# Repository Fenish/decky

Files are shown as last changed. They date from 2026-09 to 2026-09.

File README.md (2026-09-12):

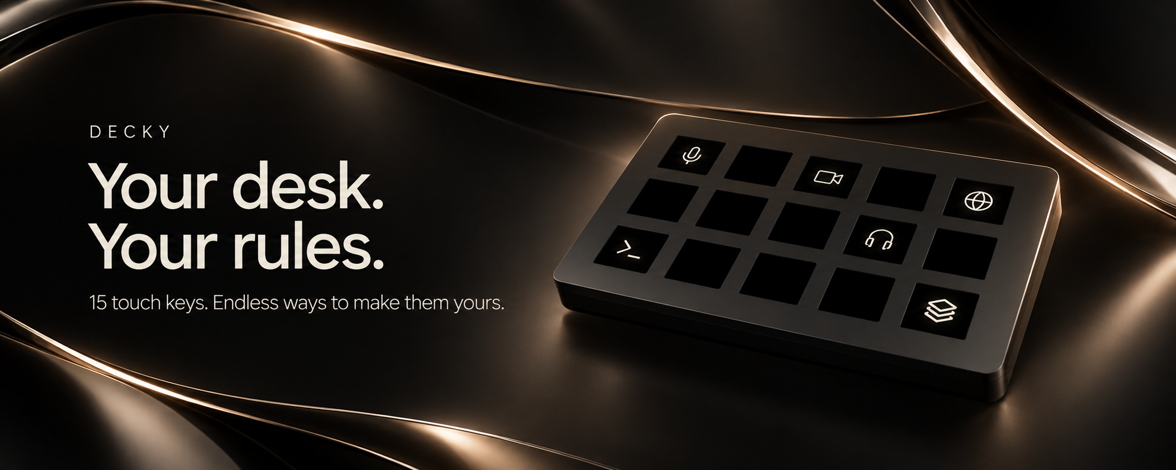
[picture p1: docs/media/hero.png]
Decky — Your desk. Your rules. Fifteen touch keys, endless ways to make them yours.


<p align="center">
  <strong>A personal touch control surface for the things you do every day.</strong><br>
  Built around a 7-inch display, a Windows app, and an enclosure you can print yourself.
</p>

<p align="center">
  <a href="#meet-your-new-workspace">Explore Decky</a> ·
  <a href="#make-it-your-own">Customize it</a> ·
  <a href="#build-your-decky">Get started</a> ·
  <a href="DeckSrc/desktop/README.md">Build it</a>
</p>

https://github.com/user-attachments/assets/fdbf7ccb-014a-4768-bcb0-b18ee1778c3f

https://github.com/user-attachments/assets/bed2e491-3eae-4fae-b585-68fe51a1e4fc

15 touch keys, USB and Wi-Fi, local SD artwork, and a Windows desktop app

## Meet your new workspace

Mute a call. Open your tools. Start the sequence that gets you live.

Decky puts your shortcuts, programs, scripts, and routines on a **5 × 3 touch
grid**. Give each key a purpose, build pages for different parts of your day,
and keep the controls you reach for right in front of you.

The desktop app pairs a floating grid with a contextual editor. Select a key and
the workspace slides aside; close the editor and the deck takes center stage
again.

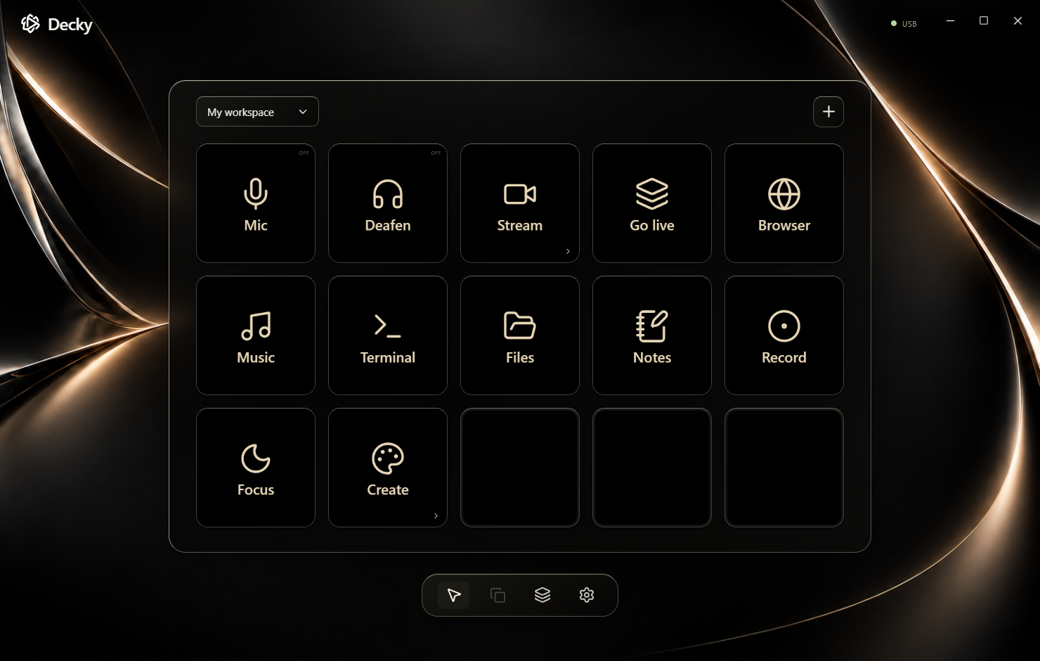
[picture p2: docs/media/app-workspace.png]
The actual Decky app with an example workspace for audio, streaming, tools, and focus


<p align="center"><sub>Actual Windows app · Example configuration · New workspaces start empty</sub></p>

### Small keys. Useful things.

| Shortcuts & hotkeys | Programs & websites | Macros & scripts |
| :--- | :--- | :--- |
| Bind your existing apps, record a combination, or let Decky reserve a free shortcut for you. | Find installed programs with their real icons. Put a favorite website one touch away. | Chain actions and delays into a routine, or launch a PowerShell script independently. |
| **Pages & folders** | **Normal & toggle keys** | **Your own artwork** |
| Keep streaming, work, and creative tools on separate pages, with a dedicated way back. | Run an action once, or give its OFF and ON appearances their own visual identity. | Search the Lucide icon library or bring your own PNG, JPEG, and WebP images. |

## Make it your own

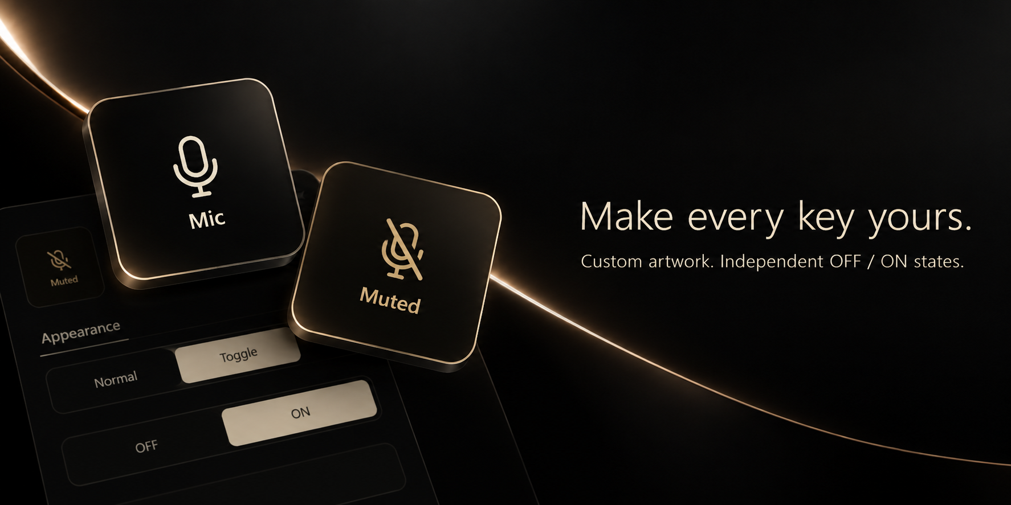
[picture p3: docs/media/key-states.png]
Illustrated close-up of Decky's microphone and muted appearances — Make every key yours


Choose the icon, label, accent, and background. Fine-tune image zoom, position,
rotation, and brightness. Leave the label out for a centered icon, or adjust the
space between the icon and its title.

**The editor and deck preview update together**, so you can see the result
before saving. Drag keys to move them, drop onto an occupied spot to swap, or
duplicate a key to build out a page. Unassigned keys stay pitch black.

<details>
<summary><strong>Look inside the real appearance editor</strong></summary>

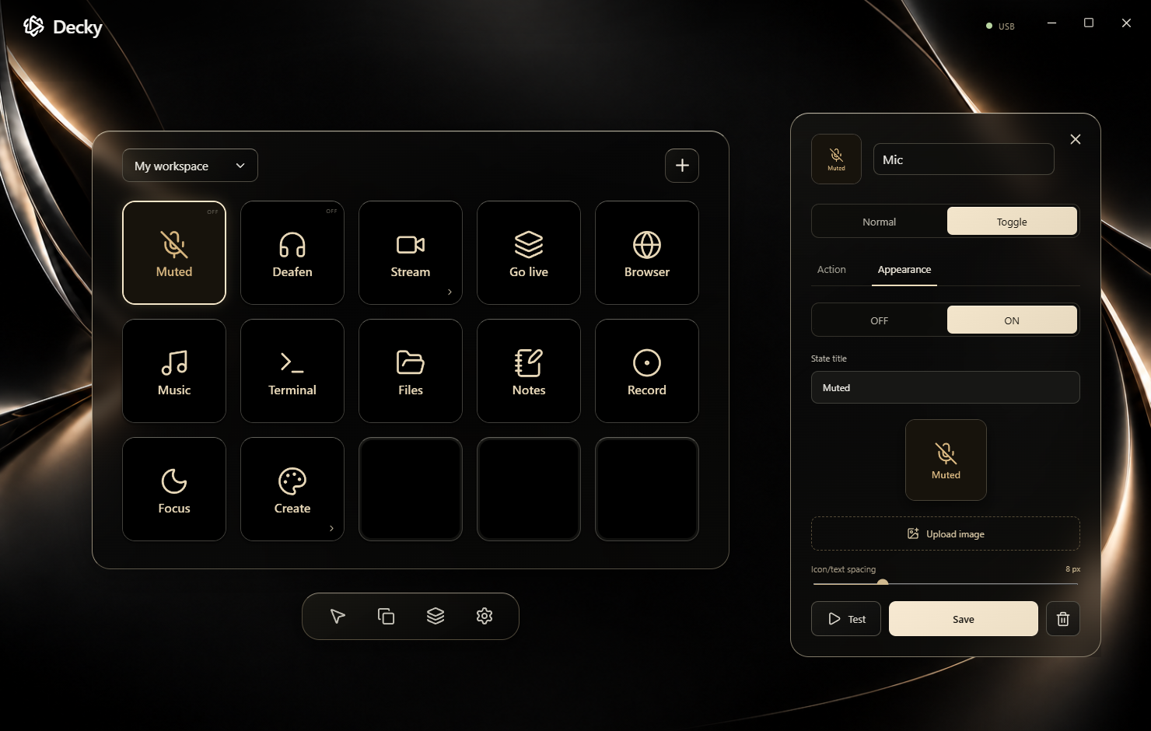
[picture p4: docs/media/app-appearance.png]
Decky's actual appearance editor with a custom ON-state preview


OFF and ON artwork are designed independently. Toggle state changes after a
successful action; it tracks the Decky session rather than reading another app's
state automatically.

</details>

<details>
<summary><strong>Build a routine with the macro editor</strong></summary>

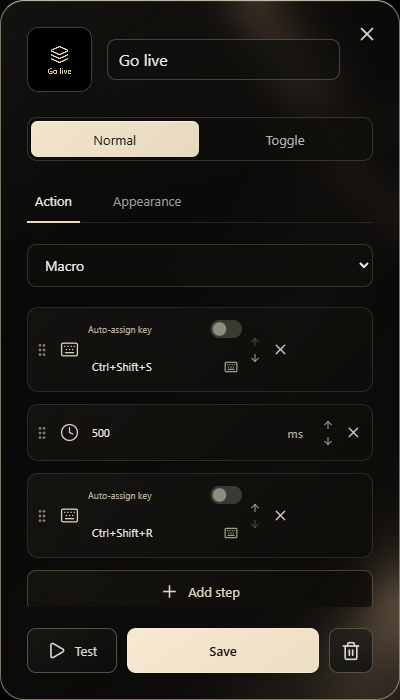
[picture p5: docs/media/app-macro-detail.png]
Actual macro editor showing two hotkeys separated by a 500 millisecond delay


Combine hotkeys, programs, websites, scripts, and delays into an ordered
sequence. Reorder steps with the editor controls. Independent scripts can keep
running while you use other keys.

</details>

## Give it a place at your desk

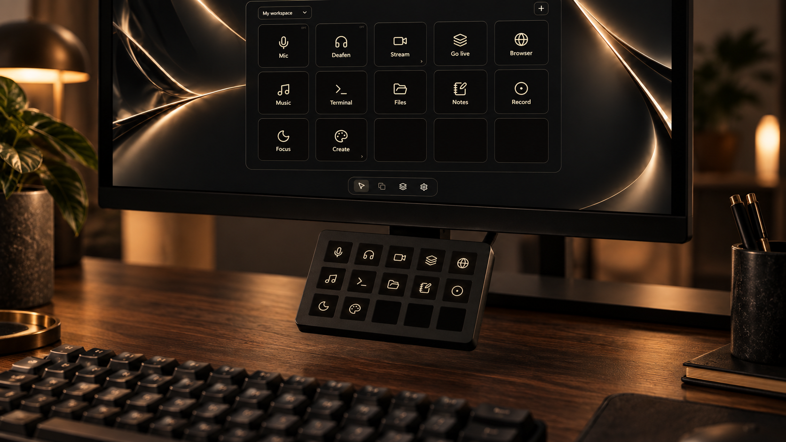
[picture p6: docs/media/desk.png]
Concept desk scene showing Decky mounted beneath a monitor with its Windows app on screen


Decky's 3D-printed enclosure is designed to hang beneath a monitor, keeping its
touch surface within reach. The repository includes the enclosure and clamp
assets alongside the software and firmware.

Pair a restrained ivory icon set with the obsidian-and-gold app, or fill your
keys with your own images. The same surface can become a streaming panel, a work
launcher, or a set of tools for the project you're in.

## Connected when you need it. Ready when you return.

### Plug in. Pair once.

Start over USB. In Settings, scan for a **2.4 GHz Wi-Fi network**, choose it,
and connect. Decky uses USB when available and falls back to paired, encrypted
Wi-Fi on your local network. USB still supplies power, and the Windows app keeps
your actions running from the system tray.

### Keep your artwork on the deck.

Add a microSD card and Decky saves your page artwork and toggle appearances
locally. After a restart, unchanged images load from the card into memory
instead of being uploaded again. Changing a toggle selects its preloaded
appearance and redraws the affected key.

### Make the next setup easier.

Export your profile to keep a copy of your configuration or move it to another
setup. Firmware installation and updates are available from the desktop app over
USB.

## Build your Decky

Decky is a **DIY hardware and software project**. Start with:

| Part | What you need |
| :--- | :--- |
| Display | Elecrow CrowPanel **Basic 7-inch**, ESP32-S3 with GT911 touch |
| Computer | A Windows PC running the Decky desktop app |
| Connection | A USB data cable; a shared local network for optional Wi-Fi |
| Storage | A microSD card for artwork that survives power cycles |
| Enclosure  | The project's 3D-printable enclosure and monitor-mount parts  |

To run the desktop app from the repository, install Node.js 22.16 or newer and
pnpm, then run:

```powershell
cd DeckSrc/desktop
pnpm install --frozen-lockfile
pnpm dev
```

Use the [firmware guide](DeckSrc/firmware/README.md) to prepare the panel. The firmware uses a pinned PlatformIO toolchain; the
repository's [hardware notes](DeckSrc/notes/memory/MEMORY.md) document the
board, touch input, SD card, and display setup.

## Under the surface

| Explore | Inside |
| :--- | :--- |
| [Windows desktop](DeckSrc/desktop) | Electron, React, TypeScript, key editing, actions, and device connections |
| [Device firmware](DeckSrc/firmware) | ESP32-S3 firmware, touch handling, rendering, wireless transport, and SD caching |
| [Hardware & build notes](DeckSrc/notes/memory/MEMORY.md) | The decisions and practical details behind the build |
| [Enclosure & mount](3D%20Models) | CAD exports and 3MF print files |
| [Branding](Branding) | Decky's logo sources and visual assets |

---

<p align="center">
  <strong>Make room for the way you work.</strong><br>
  <a href="#build-your-decky">Build Decky</a> · <a href="DeckSrc/desktop/README.md">Build the desktop app</a>
</p>

<p align="center"><sub>Hardware scenes and floating-key artwork are AI-generated product illustrations based on the project. App captures show an illustrative configuration in the real interface.</sub></p>

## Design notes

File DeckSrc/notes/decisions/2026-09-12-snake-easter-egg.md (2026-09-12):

---
name: 2026-09-12-snake-easter-egg
description:
  Five taps on an empty key play snake on the deck; one board behind the fifteen
  windows, steered by swiping, with the panel crushing into falling tiles at
  either end
metadata:
  type: decision
---

# Snake on the deck, and how it takes the panel

**Decision.** Five taps in a row on a key with nothing assigned to it start
snake on the deck itself (`firmware/src/game/snake.cpp`). The deck draws and
plays it; the window only keeps the score. When it ends the deck draws its own
page again, and the keys work as before.

**One board, not fifteen little ones.** The board is a single 20x12 grid over
the whole panel, and each key opening shows a 4x4 corner of it. The snake runs
behind the printed ribs and comes out the other side. Fifteen separate boards
was the alternative; it makes the ribs into walls, which is not a board.

**Swiping, not pressing.** A key press is a tile of the board, not a direction:
there is no natural place for four arrows on a grid that is also the playfield.
So a finger dragged anywhere across the panel turns the snake - 24 px in a
direction is a flick, less is a wobble - and the count-down before the first
move says SWIPE TO MOVE, a word to a key, because nothing else would tell you.
`KeyListener` gained a raw `touched(x, y, down, now)` for this: the game needs
the finger before the grid has decided which key it is over.

**The crush comes from the framebuffer.** Both ends of the game shatter what is
on screen into tiles that fall out of their openings. The tiles are the
picture's own colours, sampled one pixel per tile straight from
`panel::framebuffer()` (8x8 tiles a key, 960 in all, about 5 KB). Nothing has to
be kept, no page has to be re-read, and the memory the widgets needed back
yesterday ([[widgets]]) is untouched.

**Nothing else may draw while it runs.** Live patches, wheels and page states go
on arriving from the desktop during a game. They are all taken - the deck keeps
them - but the drawing is gated behind one predicate, `Deck::panel_free()`,
which now also covers the status screen and page changes it used to be spelled
out for at six call sites. The page is drawn whole when the panel comes back, so
everything that arrived meanwhile appears at once. Pausing the desktop's sends
instead was the alternative: more moving parts, and a deck that could still be
drawn over by anything that forgot.

**Why the desktop counts the taps.** The deck does not know which of its keys
are empty - it has pictures, not meaning. The desktop does, so `EmptyTaps` in
`deck-events.ts` counts taps on one empty key within 2.5 s of each other and
sends `GAME snake`; the deck's part is `GAME snake|off` and `EV GAME
SCORE|OVER`.

**Would change it.** A board that is too fast or too small to be fun on a real
panel (220 ms a step, down to 90 ms). Anyone finding it by accident - five taps
on an empty key is meant to be deliberate, and nothing on screen hints at it.

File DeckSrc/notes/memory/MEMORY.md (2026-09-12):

# Memory index

Durable facts about this project. One file per fact — read these before assuming
project context.

- [crowpanel-display](crowpanel-display.md) — the panel everything is
  dimensioned from
- [fusion-source-of-truth](fusion-source-of-truth.md) — measure in Fusion, never
  from memory
- [fusion-file-split](fusion-file-split.md) — which Fusion file holds what
- [print-support-free](print-support-free.md) — no supports, Bambu Studio, test
  prints
- [key-grid-layout](key-grid-layout.md) — 5x3, cell pitch, pixel-aligned
  openings
- [touch-input](touch-input.md) — GT911 on 0x14, no expander needed, no switches
- [no-visible-screws](no-visible-screws.md) — top cover stays clean, fasten from
  below
- [monitor-mount-scheme](monitor-mount-scheme.md) — magnet plate, clamp, GoPro
  joints, measured limits
- [open-source-unnamed](open-source-unnamed.md) — public open-source project
  named Decky; do not rename
- [decky-desktop](decky-desktop.md) — Decky identity, rewrite, black defaults,
  toggles, firmware and startup fix
- [bom](bom.md) — parts list, and the half of it the touch change killed
- [panel-pclk-limit](panel-pclk-limit.md) — 24 MHz pixel clock, bounded by
  bounce buffer size, not by the panel
- [screen-tearing-fix](screen-tearing-fix.md) — beam-synchronised writes, not
  double buffering
- [gif-encoding-for-the-panel](gif-encoding-for-the-panel.md) — full frames, no
  duplicates, and why the desktop file lies
- [pushing-media-without-flashing](pushing-media-without-flashing.md) — put an
  image or GIF on a key over serial, no reflash
- [frame-pack-format](frame-pack-format.md) — host decodes, deck only blits; the
  wire format
- [where-content-plays-from](where-content-plays-from.md) — PSRAM if it fits,
  card if not; and the card's hard 383 KB/s
- [sd-card-storage](sd-card-storage.md) — 4 MB flash is a hard limit; there is a
  TF slot on SPI
- [flashing-the-panel](flashing-the-panel.md) — CH340 driver, moving COM port,
  460800 baud, and the encoding trap
- [firmware-build-status](firmware-build-status.md) — what the board is
  currently running; the GIF player was deleted and is not in git
- [build-status](build-status.md) — what is printed, what is stale, what has not
  started
- [dont-run-long-lived-commands](dont-run-long-lived-commands.md) — the user
  starts dev servers and the app; they hang here
- [firmware-install](firmware-install.md) — the app flashes over USB; never NVS;
  two esptool-js traps
- [wifi-encryption](wifi-encryption.md) — AES-GCM frames after pairing, both
  sides must match
- [connection-priority](connection-priority.md) — USB first, Wi-Fi fallback, no
  manual switch
- [serial-unplug-stall](serial-unplug-stall.md) — a write to an unplugged port
  never returns and stalls every deck command
- [visual-tweaks-checked-by-hand](visual-tweaks-checked-by-hand.md) — styling
  changes: lint + UI checks, then hand over; the user checks the live app
- [release-pipeline](release-pipeline.md) — every product-code push to main
  releases itself; firmware has its own version
- [app-self-update](app-self-update.md) — installed Decky updates itself via
  electron-updater, differentially (blockmap, ~3 MB); the silent install is not
  yet seen on a real install
- [titlebar-drag-regions](titlebar-drag-regions.md) — nothing over the title
  bar's buttons may belong to the title bar; it steals their clicks
- [rgb-scanout-slip](rgb-scanout-slip.md) — a wrapped, shifted picture is the
  driver's bounce parity flipped by flash stalls; guarded every VSYNC, re-init
  never fixed it
- [packaging-drops-files](packaging-drops-files.md) — electron-builder silently
  drops *.obj and other extensions; package-check.mjs guards the installer
- [electron-run-as-node](electron-run-as-node.md) — shells here set
  ELECTRON_RUN_AS_NODE=1; unset it to launch Electron or the packaged app
- [deck-first-for-animation](deck-first-for-animation.md) — animated or heavy
  keys run on the deck; static or occasional ones are drawn by the app
- [widgets](widgets.md) — drawn by the app, LIVE-patched onto the deck;
  time-free base pictures, patched keys tracked per deck copy, every page warmed
  while loading, sound and prices as events, long titles slid by the deck,
  retired settings dropped on load
- [profiles](profiles.md) — several setups, one in use; a .deckyprofile carries
  one whole, and what travels is declared by each kind, never listed by hand
- [speedtest](speedtest.md) — our own Speedtest.net client: ask c.speedtest.net
  first or Istanbul gets Liechtenstein; one dropped connection must not fail the
  run
- [usb-upload-blocks](usb-upload-blocks.md) — 2 KB acknowledged blocks after
  BLOCK, thanks to the 8 KB receive buffer; test tools must honour READY's size
- [deck-restart-diagnosis](deck-restart-diagnosis.md) — why the deck restarted:
  `reset=`, deck.log, the core dump (empty means power), error 31 means replug
- [firmware-golden-run](firmware-golden-run.md) — prove a firmware change keeps
  behaviour: tools/golden_run.py record, flash, check (replies + screens)
- [generic-over-copies](generic-over-copies.md) — handler tables, not chains;
  one generic module told what it is, never per-type wrapper files
- [boot-loads-everything](boot-loads-everything.md) — nothing may be slow the
  first time after boot: every look, state and helper is loaded while the deck
  loads
- [discord-mute-state](discord-mute-state.md) — mute/deafen from Discord's local
  storage, ~5 s behind; RPC voice refused even for Decky's own app
- [discord-rich-presence](discord-rich-presence.md) — the public app ID is all
  it needs; never "Playing", only one of those shows
- [discord-rpc-control](discord-rpc-control.md) — full RPC control via
  StreamKit; channel members without joining; camera and stream state from
  Windows
- [integrations](integrations.md) — third-party apps (OBS first): declared in
  shared/integrations, a service each in main, widgets grouped by app
- [user-does-testing](user-does-testing.md) — the user tests on the deck and in
  the app; Claude checks the code and hands over

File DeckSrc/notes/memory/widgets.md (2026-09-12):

---
name: widgets
description:
  Widget keys are drawn by the desktop and patched onto the deck with LIVE; base
  pictures stay time-free; patched keys are tracked per deck copy; every page is
  warmed while the deck loads; sound and prices arrive as events, not polls
metadata:
  type: project
---

Widget keys (clock, timer, pomodoro, countdown, counter, ping, note, now
playing, volume, microphone, system, crypto, dice) are drawn by the desktop; the
deck receives pictures, and looks for the keys it turns itself.

- **Base pictures are time-free.** Page uploads carry what a widget's settings
  alone decide, so a page's signature never changes with the time. A digital
  clock's base picture is only its background, pixel-identical to an empty key.
- **The signature must stay the CRC of the pixels.** The SD store refuses any
  page whose pixels don't match it (`artwork_store.cpp`). Widget positions
  cannot go into the signature.
- **Live updates:** `LIVE <page> <sig> <cell> <baseCRC> <bytes> <crc>`, a
  tile/RLE patch, to any page the deck holds. The deck refuses it on a base
  mismatch, and the app then sends the whole key with base 0. It is gated by
  `live=1` in `ID`; hidden pages by `warm=1`.
- **Live pictures are kept apart from the page's own**
  ([[2026-09-11-live-layer]]). A page copy's own pictures stay exactly as sent,
  so they always match the signature and the card's copy loads. `LIVE` writes a
  per-key live picture.
  - **New versions:** a version built from a copy carries its live pictures and
    sliding text (`live=<mask>` in the `CACHE` reply). Only keys whose own
    picture changed go, as `PATCH`.
  - **Tracking:** `livePatched` in `main/widgets/live-keys.ts` (page id, then
    signature) mirrors what each copy shows.
  - **Widgets moved or removed:** such keys get their live picture dropped
    (`LIVE … 0 0 0`), or a moved clock leaves its time behind
    ([[2026-09-11-widgets-live-patches]]).
  - **Why:** re-sending every live widget whole took 10.4 s on the Debug page.
  - **The card save never holds an edit:** the deck shows a committed page
    first, then its main loop writes it to the card in 8 KB slices, so `COMMIT`
    answers in about 6 ms. Anything else on the card, or reusing a page slot,
    finishes the save first. Keep long card writes out of command handlers: the
    deck reads no touches and runs no animations meanwhile.
- **Every page is warmed while the deck loads** (`warm=1`). With the page cache
  the renderer sends each widget's picture as it is now and every look each
  deck-turned key can take ([[boot-loads-everything]]): a dial's muted look too,
  and a running countdown's drum, the page shown last. The app sends them after
  the pages and before showing one, counted in `HELLO`'s units. Afterwards a
  page not shown gets a widget's new picture when its state changes, at most
  every 5 s. The user asked for this: pages they switched to showed placeholders
  until visited.
- **The app waits for the deck.** While it loads - on connecting, or when the
  deck restarts - the app stays on its connection screen ("Decky is starting")
  and nothing is editable; the reveal plays after.
- **Presses:** a widget taps on release, and holds at 600 ms while still down
  (`HOLD_MS`). A finger that moved 10 px is a swipe: no tap, no hold.
- **Deck wheels (adjustable countdowns)** need finger movement:
  `EV <page> <cell> MOVE <y>`. The deck sends it only for keys named with
  `DRAG <mask>` (`drag=1` in `ID`). **Never let the firmware send unsolicited
  new line types:** released apps hand any line they can't parse to the command
  waiting for a reply (`serial.ts`), which breaks transfers. The app sends the
  mask when a page lands, and the deck clears it on `HELLO` and on disconnect.
- **Live frames are coalesced per key** (`liveQueue`): a waiting send takes the
  newest picture, so a fast swipe skips steps instead of queueing USB patches.
- **An adjustable countdown at rest is turned by the deck itself**
  (`firmware/src/keys/`, `wheel=1`).
  - **The look:** the app sends it once (`WHEEL`, `src/shared/wheel-spec.ts`):
    backdrop, the digits rasterised in the app's font, labels, and drum and
    physics settings. The deck keeps four looks by CRC, and `WHEELAT` re-arms
    one. `WHEEL` with cell -1 keeps a look without arming it.
  - **Motion:** the deck animates at the panel's rate and reports only the label
    it lands on (`EV … WHEEL`).
  - **Outside the page picture:** the wheel is drawn over the page copy without
    changing it, so `livePatched` is untouched. A `LIVE` picture for a key of
    the page shown ends its wheel.
  - **Tuning:** feel constants are in `WHEEL_FEEL` (app side) and need no
    reflash.
  - **Fallback:** without `wheel=1` the app steps the wheel from `MOVE` events.
- **Countdown sound** plays in the renderer through an `<audio>` element
  (`use-countdown-alarms.ts`), looping `kalimba.wav`. Fetching a bundled file
  would fail: Chromium's fetch refuses `file://` and the CSP allows only
  `connect-src 'self'`. The window needs
  `autoplayPolicy: "no-user-gesture-required"`, because it rings hidden in the
  tray, where no click ever happens. A tap on an ended countdown resets it.
- **Ping** times TCP to port 443 (ICMP is blocked on the user's network), with a
  second connection raced after 500 ms and ping.exe as a fallback.
- **Dials, rolls and the die (`dial=1`).** The volume is a dial: a version 2
  look (the key at its lowest, at its highest, and a per-pixel fill map). The
  deck reports `EV … VALUE` at most every 40 ms and the app sets Windows'
  volume.
  - **Coin, yes/no, list:** a drum; the app picks the side, and `WHEELROLL`
    spins to it, always forward (`rolling` in `ArmedWheel`).
  - **The die:** a 3D cube the deck draws and throws (look version 3,
    `src/shared/die.ts` mirrors its sums). Its "label" is how it lies (face,
    place, turn) and is kept as `rest` in widget state. How it lands must stay
    fair: see [[2026-09-11-deck-dice]].
  - **Same-kind looks:** a new look of the same kind takes over a key that is
    still moving without stopping it.
  - **How many looks the deck keeps:** one per key and one more, and never a
    look an armed key uses (`AnimatedKeys::LOOKS`). Released firmware up to
    0.1.4 kept four and dropped the one armed least lately, disarming its key
    without a word. So a refused `WHEELROLL` makes the app roll in its place and
    forget the arming (`rollOnDeck`); the look goes again with the key's next
    picture. Every mute makes a look of its own (greyed), so each dial on a page
    can need two.
- **Sliding text (`slide=1`).** A Now playing title or artist too long for the
  key is left out of its picture and sent to the deck as `SLIDE`
  (`shared/slide-spec.ts`; drawn by `features/widgets/slide.ts`). The deck
  slides it over the picture, so `LIVE` pictures change under it.
  - **Lifetime:** it belongs to the deck's copy of the page and goes with the
    key's live picture. `liveOverlays` in `main/widgets/live-keys.ts` mirrors
    `livePatched`: a new version carries it with the live picture, and `HELLO`
    and disconnect drop everything.
  - **Sending:** new text goes after its picture and is taken away before one,
    only when its CRC differs. The strip must render the same every time: the
    media key redraws every second, and new text restarts the slide.
  - See [[2026-09-11-sliding-text]].
- **Rings' arcs (`sweep=1`).** Only OBS's 5-second countdown ring has its arc
  moved by the deck (`SWEEP`, `shared/sweep-spec.ts`); the key's picture keeps
  only the track. Its drawing hands the arc to `moment.sweeps` through
  `sweepArc` (canvas-kit), with a motion: held, or `(t - zero) / turn` in the
  PC's clock. Keep motions exact integers from widget state, so the payload is
  identical second to second and goes once.
  - The timer (stopwatch and countdown) and pomodoro rings step with their
    digits, drawn into each second's picture (`timeRing`). The user tried them
    smooth and asked for "old version" for all but OBS.
  - Sliding text and arcs are both firmware `KeyOverlay`s and travel as
    `KeyOverlays` (`{ slide, sweep }`) through `liveKey`, the warmup and
    `LiveKeys`. An overlay taken away goes before the picture without it; one
    that comes or changes, after.
  - See [[2026-09-11-deck-rings]].
- **Readings** (volume, mic, media, CPU, prices) come from `WidgetFeeds` and are
  never saved. Only `KEPT_STATE` fields (what a person did) go to
  `widgets.json`.
  - **Sound is event-driven:** the Windows helper registers Core Audio volume
    callbacks (`watch-audio`) and writes `{"event":"audio"}` lines by itself;
    the app polls only every 15 s as a safety net. Echoes of the app's own
    volume sets are ignored for 400 ms so a turning dial never jumps back.
  - **Taps show at once:** mute and play/pause change the key before Windows
    answers; Windows' own word follows.
  - **Windows helper:** one persistent PowerShell
    (`main/system/windows-host.ps1`), one JSON line per request, answered in
    order; lines without an id are events.
  - **WinRT traps in PowerShell:** a WinRT stream is read by invoking
    `IInputStream.ReadAsync` through reflection on `$x.psobject.BaseObject`.
    Operations with progress need `AsTask` with both type arguments.
    `AsStreamForRead` and `GetInputStreamAt` fail from PowerShell. WinRT events
    are out of reach: the main loop blocks on `ReadLine`, so media is still read
    every second.
  - **Prices are live:** Binance's public stream
    (`wss://data-stream.binance.vision`, no key) for all coins on one socket,
    klines hourly for the chart, REST then CoinGecko for a coin the stream is
    quiet about (`main/widgets/crypto-feed.ts`). US dollars only (USDT).
- **Retired settings are dropped on load** (`retireWidgets` in
  `shared/config.ts`, each kind's `retire`): the network widget, crypto currency
  and interval; a microphone in a style since gone becomes an arc. Without it an
  old profile fails validation and the whole configuration is refused.
- **New firmware commands that older desktops can skip are `ID` flags**, not
  protocol bumps. Released apps reject any protocol above 7 (`serial.ts`).

**Why:** a 29 KB key cannot be resent every second over USB; patches take 20-95
ms, and uploads are bounded by [[usb-upload-blocks]].

**How to apply:** a new widget type needs no firmware change. It needs its kind,
its view, its action if it has one, and one registry line in each; a type
missing from a registry does not compile.

- **Kind** (`shared/widgets/<type>.ts`, `WidgetKind`): its settings type,
  defaults, validation, `nextChange`, and `press`/`swipe` if those change its
  state. Its type also joins the `Widget` union in `shared/widgets.ts`.
- **View** (`renderer/src/features/widgets/kinds/<type>/`, `WidgetView`): its
  drawing, its settings fields, `sample` (the made-up readings its style tiles
  show), and a `deckLook` if the deck turns it.
- **Action** (`main/widgets/actions/`, `WidgetAction`): only if a press does
  something beyond its own state - mute, play, roll. Its `gestures` table says
  what `tap`, `double`, `triple` and `hold` do. Only an action with `double` or
  `triple` makes its taps wait `TAP_GAP_MS` (300 ms) for another
  (`tap-runs.ts`), so give those to a widget only where the later tap is worth
  it.
- **Registries:** `shared/widgets/registry.ts`,
  `renderer/src/features/widgets/kinds/registry.ts`,
  `main/widgets/actions/registry.ts`.
- **Alike types share one generic module** ([[generic-over-copies]]): the volume
  and the microphone are `levelKind(...)`, `levelView(device)` (the
  `kinds/level/` folder, per-device icons and words in its `DEVICES`) and
  `SoundAction(device)`; the helper's `level`/`mute` requests take the device's
  flow. A turned dial goes to its action's `turned`.

Anything it reads goes in `WidgetFeeds` (a line in `sync`'s `reads`) - as events
where the source can tell of its changes - and anything a person sets that must
survive a restart goes in `KEPT_STATE`. Keep its base picture time-free.
Anything that must animate or follow a finger goes on the deck instead
([[deck-first-for-animation]]). Text that can outgrow its key goes to
`moment.slides` through `slideLine` rather than being cut with `clip`. A ring
the deck should move goes through `sweepArc` with a motion; the user wants that
only where asked (OBS's countdown). Removing a
setting needs its kind's `retire`.

**Designs are picked on the key, not only in the app.** A kind's `designs()`
lists the whole widgets it can be shown as (a clock's three faces, a die /
coin / yes-no / list, a level's arc and bar); a hold offers them on the key
itself, a dot each, every tap moves on, and three quiet seconds save the one
showing through `Workspace.setWidget`. `WidgetState.choosing` carries it, and
`deckTurned` answers null while it is set so the deck stops turning that key
and shows the preview instead. A widget whose hold already does something
never gets the picker, so freeing dice's hold (a duplicate of its tap) was
what let dice into it.

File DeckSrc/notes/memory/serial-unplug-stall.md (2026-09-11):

---
name: serial-unplug-stall
type: project
---

When the USB cable is pulled, the serial library closes the port itself (a
`close` event with `disconnected: true`). After that, a `write` or `drain` on
that port object never calls back: `@serialport/stream` holds them until the
port reopens, which it never does.

**Why it matters:** every deck command runs through one serial queue in the main
process. One write to a dead port stalls the queue forever, so the status check,
the Disconnected page and the Wi-Fi fallback all stop. Measured on the real
deck: the close event arrived about 1 s after the unplug, and a PING sent after
it was still waiting 12 s later.

**Wi-Fi has the same trap, worse.** A deck whose power goes never closes its TCP
connection: a write waits on TCP's own timeouts (minutes), and the whole queue
waits with it, so Decky goes on looking connected. Since 2026-09-12 the socket
is dropped when the deck ends it, a write over Wi-Fi gives up after 3 s, and a
ping still waiting while `DeckLink.silentFor` passes 8 s counts as the link gone
(`DeckSession.linkLost`, which also frees the queue by closing the link).

**How to apply:** `DeckLink` drops its port on `close` and refuses to write to a
port that is not open (`src/main/device/serial.ts`). Keep both, and the Wi-Fi
guards above. Any new code that talks to a port must not reuse a port object
after `close`. Watch the host, never the deck: listing ports and reading socket
state cost the deck nothing, while polling it would. `tests/serial.test.ts` pins
this with a fake port that behaves like the library.

Related: [[connection-priority]].

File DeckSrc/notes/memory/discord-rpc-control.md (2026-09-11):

---
name: discord-rpc-control
type: constraint
---

With a StreamKit-route token (see [[discord-mute-state]]), Discord granted every
extra scope asked for:
`rpc rpc.voice.write rpc.video.write rpc.screenshare.write rpc.notifications.read`
(2026-09-11). So the commands exist for mute/deafen, volumes, devices,
push-to-talk, soundboard, camera (`TOGGLE_VIDEO`), screen share
(`TOGGLE_SCREENSHARE`), and join/leave (`SELECT_VOICE_CHANNEL`).

What Decky can see:

- **Who is in any voice channel, without joining:** `GET_CHANNEL` returns each
  person's user (id, names, avatar hash) and mute/deafen. All 237 channels
  across 22 servers took 213 ms. Subscribing to `VOICE_STATE_CREATE` for a
  channel you are not in is accepted.
- **Camera and screen-share status do not come through RPC.** A voice state
  holds only `mute, deaf, self_mute, self_deaf, suppress`. Windows records them
  instead:
  `HKCU\...\CapabilityAccessManager\ConsentStore\{webcam, graphicsCaptureProgrammatic, graphicsCaptureWithoutBorder}\NonPackaged\*Discord.exe*`,
  where `LastUsedTimeStop` is 0 while in use. Discord's Clips recording counts
  as screen capture too.

On this PC, standalone Node (25) is reset by `discord.com` and
`cdn.discordapp.com`, while Electron's Node and `net.fetch` reach both. Run
Discord network tests through Electron (`ELECTRON_RUN_AS_NODE=1`, output
redirected to a file, since Electron is a GUI program).

**Notifications are events only, never counts.** No RPC command reads unread or
mention counts or read state (the client's full command list, datamined
2026-09-11). `NOTIFICATION_CREATE` (needs `rpc` and `rpc.notifications.read`)
fires from Discord's NotificationStore on a new message that would notify - not
while Discord's window is focused, not while a game with Discord's overlay is in
front (the overlay shows it instead), but even with desktop notifications set to
never. One that came before the link is never sent. `GET_CHANNEL` gives a
channel's last messages, with no read state; DMs cannot be listed over RPC. Old
mentions would need Discord's REST API with the user's account token -
self-botting, against Discord's terms: never offer it. The taskbar button's UIA
help text ("0 notifications") is Windows' own toast count, not Discord's badge,
and Discord's window title carries no count.

**Just started, Discord lists no devices yet.** The RPC voice settings take the
device in use from saved settings but `available_devices` from the media engine,
which fills it a moment later; `VOICE_SETTINGS_UPDATE` is sent at once on
SUBSCRIBE and again on any change. Until then the list holds one stand-in with
the default device's id `"default"` ("No Input Devices"), so an unlisted list is
"only that", not "empty". Anything drawn from the list must wait for the real
one (the switchers stay out of reach until then), or it changes twice.

**Deafened is muted, but `mute` does not say so.** Discord's `isSelfMute()`
includes deafened; the RPC reports the stored `mute`. Mute shows `mute || deaf`,
and `SET_VOICE_SETTINGS {mute: false}` while deafened undeafens.

**discord.log** (`%APPDATA%/Decky`) records the link coming and going and the
devices: read it first when a Discord start misbehaves.

**Discord's refusal echoes the token.** `AUTHENTICATE` with a bad token errors
`4009 Invalid access token: <the token>`. A script must not print RPC error
messages from `AUTHENTICATE` raw. A new Authorize (Decky's) ends the token an
earlier one gave (the lab's was refused after Decky authorized, 2026-09-11).

**Why it matters:** a Discord integration can drive almost everything from RPC,
but its camera and screen-share keys must read their state from Windows.

Related: [[discord-rich-presence]], [[electron-run-as-node]].

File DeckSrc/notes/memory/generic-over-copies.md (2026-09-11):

---
name: generic-over-copies
description:
  Code style the user asks for - handler tables instead of long if/else chains,
  and one generic, parameterised module instead of near-identical per-type files
metadata:
  type: feedback
---

**The user's rule:** structured, object-oriented code, never spaghetti.

- **Tables, not chains.** A long `if`/`else` or `switch` over kinds becomes a
  handler table: `{name, &Class::method}` rows in the firmware, typed
  `{ [K in Kind]: handler }` records in the app. A short exhaustive `switch`
  over a small closed enum is fine.
- **One generic module, told what it is.** When two things behave alike (the
  volume and the microphone), write the shared behaviour once and have each
  caller pass what differs: the level view is `levelView(device)`, called from
  the registry for each widget type, and `SoundAction(device)` does the same in
  main. Never a per-type file that only wraps the shared one.

**Why:** people try Decky within a week of 2026-09-11, and the user does not
want to ship badly structured code. They rejected a `switch (widget.type)`, and
then separate `volume-view.ts`/`mic-view.ts` wrappers around a shared module.

**How to apply:** before adding a second, similar type, make the first one
generic and rename it for what it is. Keep per-type data in a small table inside
the generic module, looked up lazily, never read while modules load (the widget
modules import one another in a ring). Related: [[widgets]].

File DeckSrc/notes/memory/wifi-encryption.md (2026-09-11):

---
name: wifi-encryption
type: constraint
---

From protocol 7, everything on the Wi-Fi link after the pairing handshake is
AES-128-GCM framed: `[u16 length][ciphertext][16-byte tag]`, a key per direction
from HMAC-SHA256(pairing secret, "decky c2s " / "decky s2c " + challenge), and a
per-direction frame counter as the nonce. The deck's challenge ends with
`aesgcm1`; the desktop refuses Wi-Fi to firmware without it. The framing exists
twice - `firmware/src/security/secure_link.cpp` and
`desktop/src/main/device/secure-channel.ts` - and the two must match byte for
byte. USB is not framed.

**Why it matters:** without it, anyone on the LAN able to inject into the TCP
stream could send deck commands or fake key presses that run the PC's bound
actions. Changing one side alone breaks every Wi-Fi connection.

See [[decisions/2026-09-10-encrypted-wifi]].

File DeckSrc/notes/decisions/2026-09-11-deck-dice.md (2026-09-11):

---
name: 2026-09-11-deck-dice
description:
  The die is a 3D cube the deck draws and throws; how its throw stays fair, and
  what made it fast enough
metadata:
  type: decision
---

# A 3D die on the deck, and keeping it fair

**Decision.** The dice widget's die is a cube the deck renders and simulates
itself (`firmware/src/wheel.cpp`, look version 3), not a drum of face pictures.
A tap throws it; it tumbles, hops, bounces off the key's edges, rolls and lies
flat wherever it stops. The deck reports its pose (face, place, turn) and the
app draws the same pose at rest (`src/shared/die.ts`).

**Why on the deck.** The user wanted it "rotating so fast and hitting walls,
think like it's 3D, then it stops wherever it is". Frames from the app take
20-130 ms each over USB ([[deck-first-for-animation]]). The look is 363 bytes;
the old drum die was 22 KB.

**Within its key, not across the screen.** The user wrote "roll around the grid"
and "boundary of screen". The deck's printed cover hides everything between the
key openings, so a die crossing keys would vanish under it. It stays in its key.

**Fairness - found by simulating before building.** A Node port of the physics
over thousands of throws:

- A throw that tumbles about a random axis by a random angle came up on its
  starting face about 40% of the time. A random axis-angle is not a uniformly
  random rotation; small turns are over-weighted.
- Picking where the air tumble ends as a Haar-random rotation (a random unit
  quaternion, Shoemake's method) is fair only if it is reached exactly. Landing
  3% short of the planned spin skewed it 21% / 10%. So the air phase is driven
  by elapsed time, not integrated.
- After landing, the spin must not continue about the air axis, which is tied to
  the chosen rotation. On the table it comes from the roll plus a fresh twist,
  and in the air the walls treat the die as a ball, so the path does not depend
  on how it is turned.
- With all three: 120,000 simulated throws came up 16.50-16.79% on every face.
  40 on the deck: [6, 4, 10, 7, 6, 7] (chi-squared p about 0.7).

**Speed.** The first build ran at 21 fps (26-37 ms a frame). Measuring each part
and a benchmark with no memory access showed the float code itself was slow.

- `-O2` and fast-math for `wheel.cpp` (min, max and square roots as single
  steps) took it to about 50 fps.
- Walking each face row by row, a shade table per face, pips drawn as their own
  ellipses and skipping black pixels under the shadow took it to 53-56 fps. The
  panel refreshes at about 54 Hz, so that is every frame it can show.
- An internal-RAM scratch buffer made no measurable difference and was taken
  out.

**Alternatives set aside.** App-rendered sprite frames (too big to send, and
limited to set orientations). Letting the app pick the face and steering the
settle onto it (a visible late flip). The drum of faces (not 3D, which the user
asked for).

**Would change it.** A measured bias on the deck over many throws. A panel with
headroom for a second animated die at full rate: two dice on one page share the
~54 Hz budget, untested.

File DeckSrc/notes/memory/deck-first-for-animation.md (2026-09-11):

---
name: deck-first-for-animation
description:
  Animated or heavy keys run on the deck itself; static or occasionally-updating
  keys are drawn by the Decky app
metadata:
  type: feedback
---

**The user's rule:** for heavy work or animated keys, use the deck first. For
static keys or ones that update now and then, use the Decky app.

**Why:** the link is the bottleneck. USB moves about 24 KB/s; a small patch
takes 20-130 ms and a whole key about a second. The deck redraws a key in about
2 ms. Anything that must follow a finger or move smoothly (a scrolling wheel,
momentum, snapping) cannot be streamed from the app. It was the user's call
after the app-drawn countdown wheel "teleported" from step to step (2026-09-11).

**How to apply:**

- **On the deck:** real-time or animated behaviour. The app sends what the deck
  needs once (shapes, lists, parameters) and the deck animates locally,
  reporting only the result.
- **In the app:** pictures that change on events or every second or more (a
  clock, ping, counter). These stay as `LIVE` patches.
- Put tunable feel (speeds, springs) in what the app sends, so tuning needs no
  reflash.

See [[widgets]].

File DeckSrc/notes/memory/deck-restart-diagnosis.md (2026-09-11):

---
name: deck-restart-diagnosis
description: How to tell why the deck restarted - reset reason, deck.log, core dump, error 31
metadata:
  type: project
---

When the deck restarts or disappears, find out why before changing code:

- `ID` ends with `reset=<reason>` (`poweron`, `sw`, `panic`, `taskwdt`,
  `brownout`...). The app writes crash, watchdog and brownout restarts to
  `%APPDATA%/Decky/deck.log`, along with uploads the deck did not answer and
  stray lines it printed.
- A crash leaves a core dump at `0x3F0000` (64 KB), which outlives power
  cycles. Decoding needs the `firmware.elf` of the build that crashed, so keep
  the ELF of anything you flash for testing. Commands are in the firmware
  README. Erase the partition after reading it, or a later restart gets blamed
  on the old crash.
- **An empty partition after a restart means it was not a panic.** It was
  verified on 2026-09-11 that this build does write dumps (a deliberate
  abort decoded correctly). So empty means power: a brownout or a dip.
- Windows "error code 31" / "device not functioning" on the COM port means
  the CH340 adapter is wedged. Only a replug fixes it; flashing cannot reach it
  until then. It came with the one unexplained restart, which points to power
  as well.

**Why:** the first restart (2026-09-11) looked like a firmware crash, but the
evidence said power.
**How to apply:** read `deck.log` and the dump first. A different USB port or
cable is the first thing to try for power restarts. See [[flashing-the-panel]]
and [[serial-unplug-stall]].

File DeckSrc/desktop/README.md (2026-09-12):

# Decky desktop

The Windows app for Decky: it draws the keys, sends them to the deck over USB or Wi-Fi, and runs
what a press asks for. This file is how to install, run, build and package it. What it does and why
it does it that way is in [`../notes/`](../notes/).

## Requirements

- Windows 10 or 11
- Node 22.16 or newer, and pnpm 10 (`corepack enable` gives you the pinned one)
- Google Chrome, for the UI and visual checks only
- PlatformIO, only if you also want the firmware bundled into the installer

## Install and run

From `DeckSrc/desktop`:

```powershell
pnpm install --frozen-lockfile
pnpm dev
```

`dev` and `preview` first run `scripts/ensure-electron.mjs`, which installs the Electron executable
when it is missing. Without it, Electron 44's on-demand installation conflicts with electron-vite
5's direct `path.txt` lookup and fails with `Error: Electron uninstall`.

Closing the window keeps Decky in the tray so its keys go on working; quit from the tray menu.

## Checks

Each exits on its own, so they can be chained in CI:

```powershell
pnpm typecheck     # both TypeScript projects
pnpm lint          # ESLint, Prettier included
pnpm test          # unit tests (vitest)
pnpm test:ui       # builds, then drives the built app in headless Chrome
pnpm test:visual   # the UI checks plus the disconnected screen
pnpm test:connection
```

The browser checks need Chrome installed. They route the built files straight to the page, with no
server and no Electron launch. Screenshots and other artifacts land in `output/`.

## Package

```powershell
pnpm package   # dist/win-unpacked/Decky.exe
pnpm dist      # NSIS installer
```

Both run `scripts/package-check.mjs`, which fails the build if a file that should be in the package
is missing. Builds are not code-signed; signing needs a publisher certificate.

To bundle firmware with the installer, build it first: `pio run -d ../firmware` copies the images
and `manifest.json` into `resources/firmware/`, which is gitignored and packed into the installer.
Without them the app still builds, and installs firmware it downloads from GitHub instead.

## Assets

Both scripts write files that are committed, so run them only when the source art changes:

```powershell
node scripts/build-icons.mjs     # resources/icon.png and icon.ico from Branding/logo-app.png
node scripts/convert-model.mjs   # public/models/decky.glb from the OBJ
```

## Where Decky keeps things

In `%APPDATA%/Decky`: `decky.json` (the profile), `widgets.json` (counters, timers),
`presence.json`, `wifi-pair.json`, `integrations/*.json`, and the logs `deck.log` and `discord.log`.

## Releases

A push to `main` that changes desktop or firmware sources builds and publishes both as one release
(`.github/workflows/release.yml`). The version counts up by itself: the patch number by default,
`[minor]` or `[major]` in the first line of a commit for a bigger step, `[skip release]` to hold a
push back. Setting `version` in `package.json` fixes the next number.

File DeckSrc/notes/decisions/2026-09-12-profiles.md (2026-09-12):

---
date: 2026-09-12
status: accepted
---

# Several profiles, and a .deckyprofile that carries everything a profile needs

**Context:** Decky has one profile, `decky.json`, and Settings can export it as
plain JSON and import it back over the top. That JSON names scripts and images
by absolute path, so it is only a profile on the PC it came from, and importing
replaces what you had. The user wants several profiles, switched only after
looking inside one, and a single file they can hand to someone else that brings
the whole setup with it: scripts, artwork, the lot.

## What a profile is

`%APPDATA%/Decky/profiles/<id>/`, one folder each:

```text
profiles.json            the list, and which is active
profiles/<id>/
  profile.json           pages and keys - today's decky.json
  widgets.json           counters, timers, the last dice roll
  integrations/*.json    one per app Decky talks to
  files/                 scripts and images the keys use
```

Kept out of profiles, because they belong to this PC and not to a setup: the
deck's Wi-Fi pairing, the window's own settings, update state. Switching
profiles never logs the deck out of anything.

Today's `decky.json` becomes `profiles/default/profile.json` the first time the
new build starts, and the old file is left where it is.

## The file

`<name>.deckyprofile`: a header (`DECKY`, a format number), a random salt and
IV, then the archive encrypted with AES-256-GCM. Inside: `meta.json` (name,
when, the Decky and protocol versions it came from, and counts), `profile.json`,
`integrations/`, and `files/`.

The key is derived from a constant inside Decky. **This is obfuscation, not
secrecy** - any copy of Decky opens any `.deckyprofile`, which is what "only
Decky can read it" means in practice. It stops the file being edited in a text
editor and makes it clearly Decky's. The UI says as much where it matters, and
credentials never go in at all (below).

Windows learns the extension from the installer (`fileAssociations`, icon built
from `Branding/decky-profile.png`), and the app registers it under HKCU when it
starts so a `pnpm dev` build behaves the same. Double-clicking one starts Decky
if it is closed, or wakes the running one through the single-instance lock it
already has; either way the file waits until the deck has finished loading, and
then Decky asks.

## It must catch new things by itself

The rule for everything below: **one declaration, where the thing is declared;
the profile machinery only walks the registries.** Adding a widget, an action, a
credential or an integration must not mean remembering to edit an export list.

- **Files a key uses.** Each action kind already declares how it is validated
  (`ACTION_CHECKS`); it now declares its file fields beside that. The bundler
  asks each kind for the paths in an action and for a copy of it with new paths,
  so it can rewrite them on import. The table is a mapped type over the action
  kinds, so a new kind **does not compile** until it says whether it has files.
  Widget kinds get the same optional hook.
- **Integrations.** The bundle walks `Object.keys(integrations)`, so a new app
  is carried the day it exists. Each service declares which of its settings are
  secret; those are dropped from an export and asked for again after an import.
  Same mapped type, same compile-time nag.
- **Everything else in the profile** travels as the JSON it already is, so a new
  field on a key, or a new widget type, rides along with no change here at all.
  `validateConfig` and `retireWidget` decide what survives the trip back.

## Looking before you leap

One inspector, used for both importing a file and switching to a stored profile.
It shows: where it came from and when, its pages and keys, its widgets by type -
**including the ones this Decky no longer has, named and counted, with the keys
that will be dropped** - the files it carries, and every program and script a
key would run. That last list is the point: a `.deckyprofile` is someone else's
setup, and it can point keys at executables. Nothing is written until the button
is pressed.

Importing always **adds a profile**; it never overwrites the one in use. Its
files land in the new profile's own folder and its keys are rewritten to point
there, so the profile works on a PC that has never seen those paths, and
deleting the profile takes its files with it. Programs (`.exe` you launch) are
recorded by path, not copied.

**Rejected:**

- _A password on the file._ Real secrecy, but it has to travel with the file
  anyway, and a lost password is a lost profile. Offered later if wanted.
- _Restoring files to the paths they had._ Exact on the machine it came from,
  and wrong everywhere else - it writes into folders that may belong to someone
  else.
- _Importing over the current profile._ A double-clicked file should never be
  able to wipe the setup you are using.
- _A hand-kept list of what to export._ It is wrong the first time someone adds
  a widget and forgets, and the failure is silent: a profile that quietly leaves
  something behind.

See [[integrations]], [[widgets]].

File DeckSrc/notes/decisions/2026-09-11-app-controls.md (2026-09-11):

# App controls: toggle keys that follow an app

**Asked:** Discord's mute, deafen, camera and screen share as toggle buttons,
"so i can put my own stuff on and off states".

**Decided:** one general action, `{ kind: "app"; app: IntegrationId; control:
string }`, checked against the app's declared `controls`. The alternative was a
Discord-only action kind (`{ kind: "discord", control }`). The general one
lets OBS offer a "Record" toggle, or any later app its own controls, with no new
action kind.

- A toggle with one does not flip on a press. `AppControls` sets every such key
  to `service.controlState(control)` whenever the app says something changed,
  and the page shown gets `STATE`.
- The press goes to `service.press(control)` from `Workspace.runKey`, as pages
  go to navigation. The runner never sees it (`isStep`).
- Picking a control makes a toggle at once. OFF is the app at rest (Mic); ON
  is the control's `on` look (Muted, red).

**What it constrains:** profiles now hold `kind: "app"` actions. Renaming or
reshaping it after a release needs a `retire` migration. It is unreleased, so it
can still change freely.

No critic: the schema is unreleased and changes for free until the next push.
The StreamKit route was the user's call, made knowing it is unofficial
([[discord-mute-state]]).

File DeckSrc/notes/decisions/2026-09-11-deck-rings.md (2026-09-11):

# Rings' arcs moved by the deck

**Problem (user report):** the OBS 5-second countdown ring and the timer's ring
step once a second. The user wanted them smooth.

**Decided:** the deck draws and moves the arc ([[deck-first-for-animation]]).
The key's picture keeps the ring's track; `SWEEP` sends the arc once: where the
ring is, its look, and how its end moves with the clock. The digits under it
stay `LIVE` patches, once a second.

**Why not the app:** a patch takes 20-130 ms over USB and competes with every
other live key, so a few steps a second at best. The user chose the deck when
asked.

**Why not a dial look:** a dial already fills per pixel against a map, but it is
a wheel look, and a `LIVE` picture ends a key's wheel. A timer's digits change
every second, which would stop it each second: the reason sliding text is an
overlay too ([[2026-09-11-sliding-text]]).

**The clock in the line, not the payload:** the motion is `(t - zero) / turn`
in the PC's clock, and `SWEEP`'s line ends with that clock as it is sent. The
payload is then the same for as long as the motion holds, so the CRC check that
keeps slides from being resent does the same here: a running stopwatch's arc
goes once. The price is the line's transit time (a few ms) as a fixed offset,
and the two clocks' drift (tens of ppm) over a long run. Neither shows on a
ring.

**One overlay base:** sliding text and the arc are both `KeyOverlay`s, one per
kind per key, drawn in a row pass. `SLIDE` and `SWEEP` share one handler, and
the desktop sends both as `KeyOverlays`. A new kind needs a class, a kind and a
table row ([[generic-over-copies]]).

**Order, changed for slides too:** an overlay taken away goes before the
picture that has none; one that comes or changes goes after its picture. Before,
removing sliding text went after the new picture, which briefly showed the text
twice.

No critic: `SWEEP` is behind an `ID` flag and unreleased, so the format can
still change on both sides for free (as with `SLIDE`).

**Later the same day:** having tried a 10-second countdown smooth on the Debug
page, the user asked for the Timer's countdown "stepped like before". Its arc
is drawn into each second's picture again; the stopwatch, pomodoro and OBS
countdown stay on the deck.

Then: "only obs 5 second smooth other old version pls". The stopwatch and
pomodoro step once a second again too; `SWEEP` carries OBS's countdown ring
alone. The mechanism stays general.

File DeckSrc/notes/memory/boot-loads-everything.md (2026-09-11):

---
name: boot-loads-everything
description:
  The user's rule - when the deck finishes loading, nothing may lag on first
  use; boot preloads every cache and every state a key can reach
metadata:
  type: feedback
---

**The user's rule:** "boot basically will load everything... every cache, every
state... when boot ends I don't want any lag on my deck." Nothing may be slow
the first time and fast afterwards.

**Why:** the first mute on the volume or the microphone took about a second (its
greyed dial look, 25 KB, travelled then: 889 ms, against 20 ms once the deck
kept it). The user asked that every widget and button get the same care.

**How to apply:** for any new widget, button or state, ask what its first use
builds, sends or starts, and do that while the deck loads.

- **Looks:** every look a key can take goes at boot (`lookKeys`, `deckLooks` in
  the renderer), not only the one for its state now.
- **Helpers:** start them at boot where the profile needs them. The keystroke
  helper starts with `ActionRunner.prepare`, and the Windows helper with the
  first sound or media widget.
- **Pictures:** pages, ON pictures, and widget pictures and sliding text are
  loaded for every page.
- **Limits:** the deck keeps looks one per key plus one; more than that and the
  oldest unused ones go. More than 8 pages do not fit in its memory at all, and
  then nothing is preloaded (`cachePages` refuses).

Related: [[widgets]], [[deck-first-for-animation]].

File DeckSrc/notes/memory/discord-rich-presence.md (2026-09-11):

---
name: discord-rich-presence
type: constraint
---

Decky's Discord application is `1548005754705813654` ("Decky", owned by the
user). The ID is public, and Rich Presence needs nothing else: handshake on
`\\.\pipe\discord-ipc-0` with `{v: 1, client_id}`, then
`SET_ACTIVITY {pid, activity}`. No OAuth, no secret, works for every user. The
activity clears when that pid's process exits or the pipe closes. The Public Key
is only for interaction webhooks. The Client Secret must never be in the repo or
the app.

Discord shows one "Playing" (type 0) activity at a time, and the one already
there stays. With the VS Code presence ("Code") running, "Playing Decky" was
accepted but shown nowhere; the same activity as type 3, "Watching Decky",
showed next to it (tested 2026-09-11).

**Why it matters:** as "Playing", Decky's presence is either invisible or pushes
out the game a user is actually playing. Use another type, behind an on/off
setting.

Related: [[discord-mute-state]].

**Built (2026-09-11):** Settings → Show on Discord (off by default).
`src/main/discord/discord-ipc.ts` is the pipe client, reusable for Discord's
controls later. `src/main/discord/presence.ts` gathers the facts: the deck
connected, a key open in the editor, OBS outputs, updates installing, and
presses today. `src/shared/presence.ts` turns them into the card. The user
chose "presses only, no names": pages and keys are never named. The picture
is the art asset `decky`, which the user uploads in the Developer Portal. At
most one update every 4 s, and only when the card changed.

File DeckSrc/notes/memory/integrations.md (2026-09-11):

---
name: integrations
description:
  Third-party apps Decky talks to (OBS first) - one family declared in
  shared/integrations, a service per app in main, widgets grouped by app; how to
  add one
metadata:
  type: project
---

**The family:** an app is declared once in `src/shared/integrations/<id>.ts`:
name, icon, settings fields (text, or secret), and for each standing (missing,
closed, off, denied, ready) a `brief`, the full `says`, and the card's button
(`buttons`: open, download or settings), plus its `download` page.
`INTEGRATIONS` names them all.

- **Main:** each app has a service (`src/main/integrations/<id>/`,
  `IntegrationService`: load, sync, status, check, save, open, stop) and a row
  in `IntegrationServices`. `WidgetReadings` syncs and stops them with pings and
  feeds.
- **Settings:** `integrations/settings-store.ts` keeps each app's settings in
  `%APPDATA%/Decky/integrations/<id>.json`, secrets encrypted, never in the
  profile.
- **Window:** the IPC is generic (`integration:status` / `integration:save` /
  `integration:open` / `integration:download` / `integration:status` events).
  The picker (Actions → Apps → app) is drawn from the declarations. Each app's
  page opens with its connection in one line (a brief standing from `brief`, and
  the standing's button: Open OBS while closed, Get OBS while missing, else
  Connect… or Edit opening a dialog with its fields and the full `says`), then a
  rule, then its keys; the same line is in its keys' editor. The user wanted it
  there, not in Settings, and the Apps rows as bare names.

**OBS:** obs-websocket 5 (OBS 28+, default `localhost:4455`). Widgets
`obs-record` and `obs-stream` come from `obsKind`, `group: "obs"`.

- A touch counts down 5 s before start or stop; a second touch calls it off.
- **Follow OBS's events, never re-asked statuses:** obs-websocket answers
  requests on a pool of threads, so answers can come back out of order. A status
  asked for during a stop once kept the Recording key running. Keys follow the
  events' `outputState` in order (`STATES` in `obs-service.ts`); the status is
  read only as the link opens.
- The link is kept while any OBS key exists, from Decky's start
  ([[boot-loads-everything]]). It retries every 3 s while OBS is closed or its
  server is off, every 15 s while OBS is not installed, and waits for new
  settings after a refused password.
- On the user's PC OBS is installed (registry `HKLM\SOFTWARE\OBS Studio`,
  default value the install folder; `bin\64bit\obs64.exe` under it).
  `ObsFinder.launch` starts it from that folder; never start OBS from a
  session - the user starts apps.

**How to apply:** a new app follows the README's "A new app needs" paragraph. It
is a new id, its declaration, its service folder and a row in each table; its
screens follow. Keep per-app specifics in tables inside its own module
([[generic-over-copies]]). Its widgets go through the widget registries as usual
([[widgets]]).

**Discord (2026-09-11):** the second app. Its keys:

- **Mute, Deafen, Camera, Screen share, Noise suppression, Echo cancellation,
  Auto gain, Leave call** are app controls: the Action
  `{ kind: "app", app, control }`, declared in the app's `controls`. A toggle
  key's ON and OFF follow the app (`AppControls`, `KeyStateStore.follow`), and a
  press never flips it. The user wanted toggles so they can draw their own ON
  and OFF - Leave call too (red while in a call). The window never says ON and
  OFF for them: each control declares its `states` words (Unmuted/Muted, Not in
  a call/In a call), used by the editor's look switch and the key's corner
  (`stateNames`). The user asked for that.
- **Out of reach, every key of the app looks disabled** - widgets and control
  keys alike: grey icon, the one slash (`strike` in canvas-kit), grey label.
  Control keys get it in their page pictures (`renderKey`'s `disabled`, from the
  window's `useAppsDown`). The user asked for it for all of them; a new app's
  keys should follow it too.
- **Never change toggle ON pictures with runtime state.** The deck takes ON
  pictures (`ALT`) only whole (29 KB), reloading one from its card only by the
  same checksum. Changing them on Discord's reach froze the deck for seconds
  each time (2026-09-12). The disabled look is on the OFF picture only; an app
  out of reach reports no control state, so its toggles show OFF.
- Noise suppression is Discord's **Standard** mode: the RPC's
  `SET_VOICE_SETTINGS` has only a `noise_suppression` boolean
  (`setNoiseSuppression`; Discord's own client code, datamined). Krisp
  (`noiseCancellation` in its settings) cannot be set over RPC; the user
  accepted that.
- **Widgets** (`discord-*`, `group: "discord"`): Voice channel, Current call,
  Mic and Output switchers, Notifications. The voice keys show avatars only,
  past four "+n", green while you are in it, speaking rings in your own call.
  **Use current** fills the channel ID (`integration:call`, "currentChannel").
  Every Discord widget draws the key's own library icon (in the key's colour, at
  its Icon size) when it has nothing else to show - the user asked for that and
  for per-key design choices (layout, name on/off) in the Appearance tab
  (`WidgetView.appearance`, `icon: true`).

It reaches Discord's RPC as **StreamKit** (`207646673902501888`; see
[[discord-mute-state]], [[discord-rpc-control]]). This is unofficial: Discord
shows "Discord StreamKit Overlay". The token lasts 7 days, has no refresh, and
is kept encrypted in `integrations/discord.json`.

- Camera and share state come from Windows (the helper's `capture`), which
  Discord's RPC does not report.
- Starting a screen share opens Discord's picker, so Discord is brought to the
  front by starting it again through its `Update.exe`, which leaves its view as
  it was. Never use a bare `discord://` for that: it navigates to Home (the user
  saw /@me open). `discord://-/channels/<guild|@me>/<channel>` is right only
  where going there is wanted (a notification's conversation).
- A token's scopes come back in `AUTHENTICATE`. One given before a scope was
  asked for (notifications) keeps working; only the key needing it waits for
  Authorize again.
- The Windows helper is shared: whoever needs it calls `hold(who, needed)`.

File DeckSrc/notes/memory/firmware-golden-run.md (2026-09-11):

---
name: firmware-golden-run
description:
  How to prove a firmware change leaves the deck's behaviour unchanged -
  tools/golden_run.py record, then check
metadata:
  type: project
---

The firmware has no unit tests. A change that should not alter behaviour (a
restructure, a refactor) is checked on the deck with
`DeckSrc/firmware/tools/golden_run.py`.

1. Run `record` on the build before the change.
2. Flash the change.
3. Run `check`.

It drives every command the desktop uses in a fixed order and compares every
reply, and two `SCREEN` captures pixel for pixel. What it controls for:

- **A restart first** (RTS), so nothing a previous run left in RAM changes the
  replies.
- **A new page signature every run**, so the SD card never has the page. The
  nonce pixel sits under the die, which covers it.
- **Replies that vary for reasons that aren't the firmware's** are normalised:
  `fw=` (the git-derived version stamp), `reset=`, `base=`, and ALT `cached=`
  (the card keeps ON pictures between runs).

**Why:** on 2026-09-11 the firmware was split from two big files into folders
and classes. The run showed the new build identical: 59 replies, both captures.
Frame rates were measured separately: die 52-55 fps thrown, drum 70-80 fps spun.

**How to apply:**

- Run it before calling any "no behaviour change" firmware work done.
- For speed, time frames with `DISPLAY_STATE` during `WHEELROLL`/`WHEELSPIN`.
- The fixtures in `tools/golden/` are the app's own looks. A change to a look's
  format needs new fixtures and a check by eye.
- The app must be closed (COM5), as for flashing. See [[flashing-the-panel]].

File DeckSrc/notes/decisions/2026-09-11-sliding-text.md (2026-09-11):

# Sliding text on the deck

**Asked:** a song title too long for the Now playing key should slide so all of
it can be read. The user picked the loop (rest, slide left, the start following
after a gap), and Now playing only for now.

**Decided:** the deck slides it. The app draws each overflowing line once, as
coverage in its own font, and sends it with `SLIDE`. The deck lays it over the
key's picture, at the panel's pace. Only a line that does not fit slides, and
the key's picture leaves it out.

**Why the deck:** the user's rule ([[deck-first-for-animation]]). The numbers
agree: a moving strip is a new picture every 33 ms. USB carries a patch in
20-130 ms, so the app could manage 3-10 steps a second at best, and they would
queue behind the progress patches.

**Why not a wheel look:** a `LIVE` picture ends a key's wheel. Now playing's
progress line patches the key every second, so a wheel-based slide would stop
each second. Sliding text is an overlay on the page copy instead: `LIVE` changes
the picture under it without restarting it.

**Lifetime, and the risk it answers:** text hangs off the deck's copy of the
page (page id + signature), like LIVE patches, and the app mirrors it
(`liveSlides`).

- If text were kept per page id and cell only, moving the widget would slide a
  stale title over whatever key took its place, until the app noticed.
- With per-copy text, a new version of a page starts clean.
- `HELLO` and disconnect drop everything. So a new session never inherits text
  that the app thinks is absent: "absent" is the one state the app never
  re-sends.

**Drawing:** each frame writes only the box the lines cover.

- The box is built from the key's own picture, then each line is blended in.
- Title and artist windows overlap by a few rows, so they are drawn together in
  one pass rather than each restoring its own window.
- Windows stay 2 px inside the key, clear of the pressed outline.

**Checked:**

- A Python copy of the deck's blending, run on the app's real output.
- On the deck itself: at rest, after a LIVE picture under it (it kept going),
  two lines at once, and taken away.
- Unit and simulated-deck tests cover the format, the timing, and when the app
  sends it.

No critic: the command is behind an `ID` flag and unreleased, so the format can
still change on both sides for free.

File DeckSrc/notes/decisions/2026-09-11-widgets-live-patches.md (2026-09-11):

---
date: 2026-09-11
status: accepted
---

# Widgets: drawn by the app, patched onto the deck

**Context:** the user asked for widget keys: a clock (12/24-hour, several
styles), timer, pomodoro, countdown, counter, ping (first built as a server
status check) and note. A clock with seconds changes a key every second, and a
key image is 29 KB. Over USB, measured at about 24 KB/s, sending a whole key
takes about 1.2 s.

**Choice:**

- The desktop draws every widget on a canvas, like any other key. The deck gets
  pictures, not widget logic: no clock, timers or network checks in firmware.
- Page uploads carry each widget's _base picture_, which only its settings
  decide. The time never changes a page's signature, so the PSRAM and SD caches
  keep matching.
- While a page is shown, the renderer redraws a widget when its picture next
  changes. The main process sends the difference from the picture the deck
  holds: `LIVE <page> <sig> <cell> <baseCRC> <bytes> <crc>`. The patch holds the
  changed box of each 32 × 32 tile, run-length encoded. It travels through the
  existing READY/block-ack transfer. The deck refuses the patch when its copy
  does not match `baseCRC`, and the app then sends the whole key (base 0).
- Widget state (timer, pomodoro, counter) lives in the main process, in
  `widgets.json`.
- The firmware announces `live=1` in `ID`; `DECKY_PROTOCOL` stays at 7.

**Rejected:**

- _The deck draws widgets._ It needs fonts, time zones, time sync and network
  checks in firmware, and a reflash for every new style.
- _Resending the whole key every tick._ At about 1.2 s per key over USB it
  cannot keep up with a seconds display.
- _Protocol 8._ Released apps accept only protocols 1-7 (`serial.ts:113`,
  `BOOT decky [3-7]` at `:147`), so they would reject the new firmware as not a
  Decky. A flag lets either side update first.

**Review:** a fresh critic read the code and returned _sound with caveats_.

1. **The deck's copy drifts from the app's baseline** (SD reloads, a rebuild
   copying patched pixels, failed patches), and `LIVE <cell>` could race a page
   switch. _Accepted:_ page, signature and base CRC go in the command, and base
   pictures are time-independent. Falsifier given: after eviction, a reboot and
   an app restart, the deck's key matches the app's image and startup is no
   slower.
2. **Taps are lost inside transfers**, which widgets make constant. _Accepted:_
   the firmware polls touch between blocks and while waiting for data, at least
   15 ms apart. Falsifier: 100 quick taps on a page with a seconds clock give
   100 `EV DOWN` events.
3. **Chromium slows timers in the hidden (tray) window.** _Accepted:_
   `backgroundThrottling: false`. Falsifier: ticks stay 1000 ± 50 ms apart after
   10 minutes in the tray.

Also raised was protocol 8 being rejected by current apps; the capability flag
answers it. The critic also suggested batching all changed keys of a tick into
one command. _Not adopted:_ a page holds one or two ticking widgets, so each
sends its own `LIVE`. Revisit if a page of seconds clocks lags.

**Measured (USB):** a small patch takes 21 ms. A 968-byte patch, the worst
seconds-digit change, takes about 94 ms. A whole plain key, run-length encoded,
takes 35 ms. A wrong base is refused. The critic's budget of 30-80 ms per tick
was close, and the worst case ran a little over it.

**Did it matter:**

- **Objection 1: yes, and it went further than the fix.** The base-CRC check
  covers keys that are still widgets. The user then moved a digital clock, and
  its last picture stayed behind on the deck. A digital clock's base picture is
  only its background, the same as an empty key's. So moving it changed neither
  the signature nor any picture, and the deck's patched copy was shown as it
  stood.
  - _Fix (desktop only):_ `livePatched` records, for each copy of a page the
    deck holds (page id and signature), which keys patches drew into.
  - A patched key is re-sent whenever the page is rebuilt from that copy, so
    committed pages and their SD copies hold exactly their own pictures. The SD
    loader checks the pixel CRC against the signature, so patched pixels there
    would also have made it refuse the page after a reboot.
  - When the deck already holds the page, a patched key that is no longer a
    widget is restored with a whole-key `LIVE`. `sendLive` refuses keys that are
    not widgets.
  - `tests/widget-live-sync.test.ts` reproduces the bug against a simulated
    deck. Switching off either half of the fix fails it.
- **Objections 2 and 3:** open; their falsifiers have not been run yet.

**Ping, settled by measurement:** on the user's network (behind a VPN adapter),
ICMP to the internet never answers while TCP to port 443 answers in 16-46 ms.
One TCP handshake in 30 was lost outright (no answer within 8 s). So the ping
widget times a TCP connection to port 443, and a refusal counts as an answer. A
second connection starts if the first has not answered after 500 ms, and
whichever answers first counts, timed from its own start. In the result, 40 of
40 answered. ping.exe runs only when TCP gets no answer; a LAN router that
dropped TCP to 443 answered it in 1 ms.

See [[widgets]].

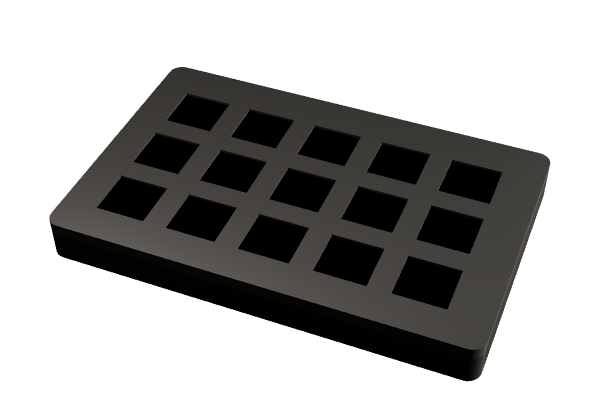
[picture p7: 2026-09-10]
DeckSrc/desktop/src/renderer/src/assets/decky-studio-fallback.png

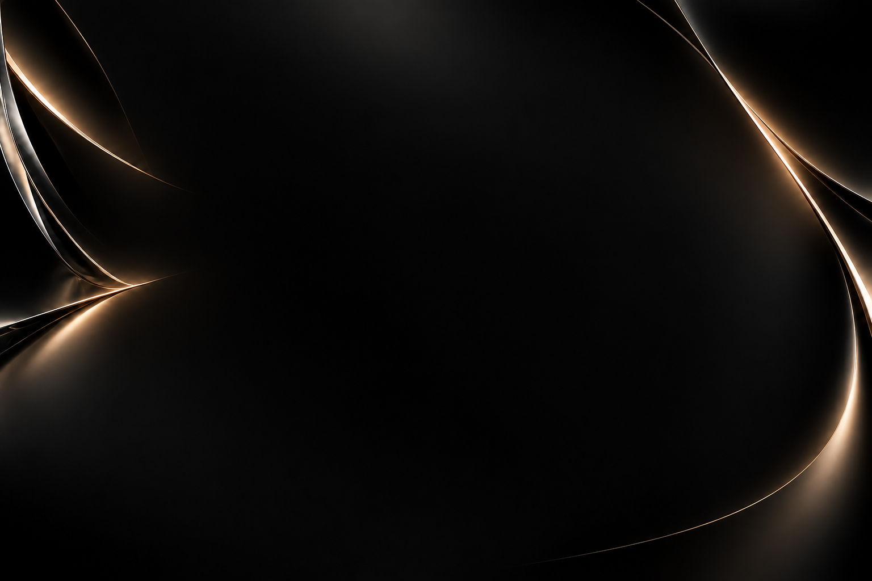
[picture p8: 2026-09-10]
DeckSrc/desktop/src/renderer/src/assets/dashboard-obsidian.webp

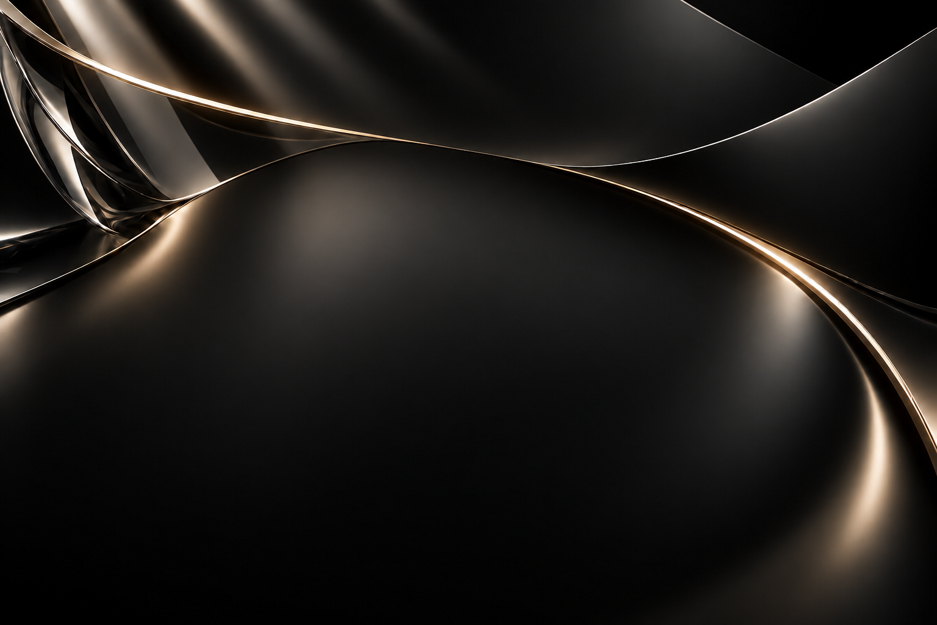
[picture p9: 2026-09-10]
DeckSrc/desktop/src/renderer/src/assets/disconnected-obsidian-smooth.webp

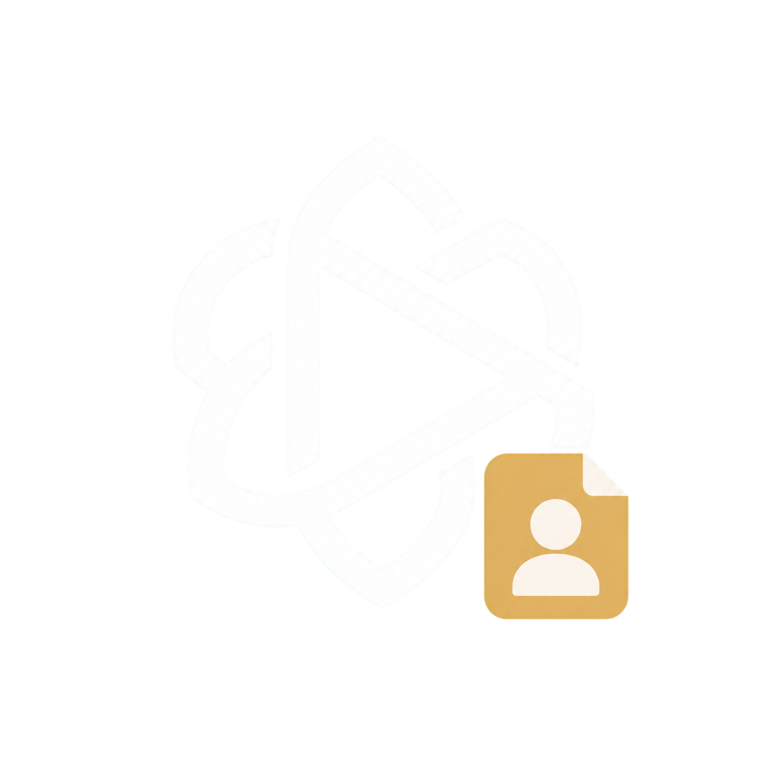
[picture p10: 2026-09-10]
Branding/decky-profile.png

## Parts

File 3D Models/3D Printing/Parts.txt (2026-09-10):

4x M6x30 Screw
4x M6 Nut
4x M3x10 Countersunk head screw

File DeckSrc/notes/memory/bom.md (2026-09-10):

---
name: bom
type: reference
---

Bill of materials as it stands after the move to touch input (2026-09-09):

- 24 x neodymium magnet 6x3 (12 in the case, 12 in the mount plate)
- 4 x M3x10 self-tapping, for the cover
- M6 screws for the GoPro joints
- silicone pads for the clamp faces

**Dropped when the switches went.** 60 x tact switch 6x6x6.5 mm, 1 x MCP23017
I2C expander, 30 AWG stranded silicone wire, and the 15 plexi keycaps
(24.2 x 23.3 x 2.0 mm) are all out of the design - the finger touches the glass
directly now. Do not re-order any of them. The plexi thickness used to be a
hard interface dimension; it constrains nothing any more.

**Why it matters:** most of the old parts list was there to serve a switch
matrix that no longer exists. See [[touch-input]],
[[decisions/2026-09-09-touch-instead-of-switches]].

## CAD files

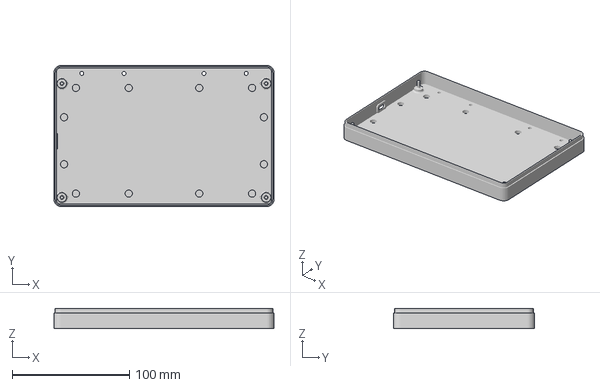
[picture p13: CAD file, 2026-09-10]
3D Models/3D Printing/Deck/Bottom Case.3mf
187.3 x 120.2 x 17.4 mm

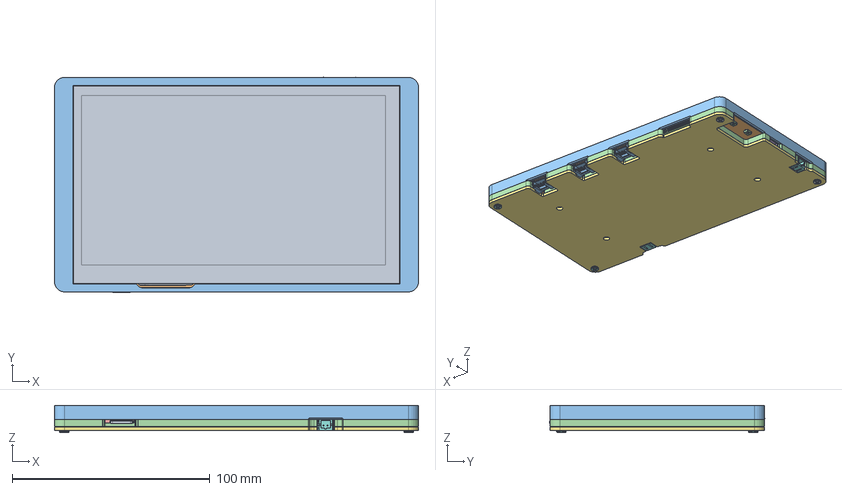
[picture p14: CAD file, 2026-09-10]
3D Models/3D_File_CrowPanel_7.0-ESP32_HMI-3.0.stp
184.0 x 108.9 x 13.8 mm
BREP_34
BREP_3
BREP_1-527
BREP_1-551
BREP_2-552
BREP_2-528
BREP_4
BREP_5
BREP_6
BREP_7
BREP_8
BREP_9
BREP_10
BREP_11
BREP_12
BREP_13
BREP_14
BREP_15
BREP_16
BREP_17
BREP_18
BREP_19
BREP_20
BREP_21
BREP_22
BREP_23
BREP_24
BREP_25
BREP_26
BREP_32
BREP_33 x 2
GPIO-D-8PIN
7IN-CHECK
7IN-JZ
CROWPANEL_ESP32_DISPLAY-7_0-INC

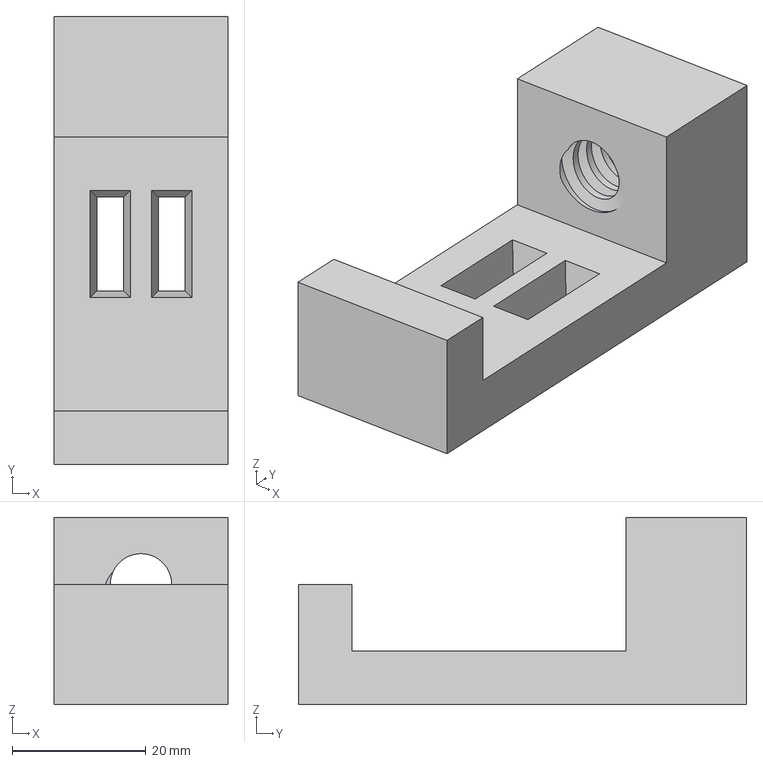
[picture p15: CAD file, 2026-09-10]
3D Models/3D Printing/Clamp/Monitor Clamp.3mf
26.0 x 67.0 x 28.0 mm

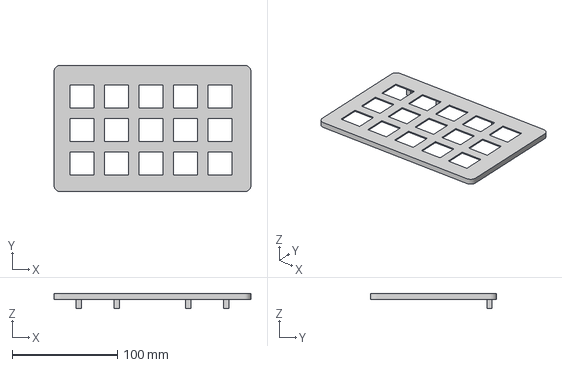
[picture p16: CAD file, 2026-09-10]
3D Models/3D Printing/Deck/Top Cover.3mf
187.3 x 120.2 x 14.1 mm

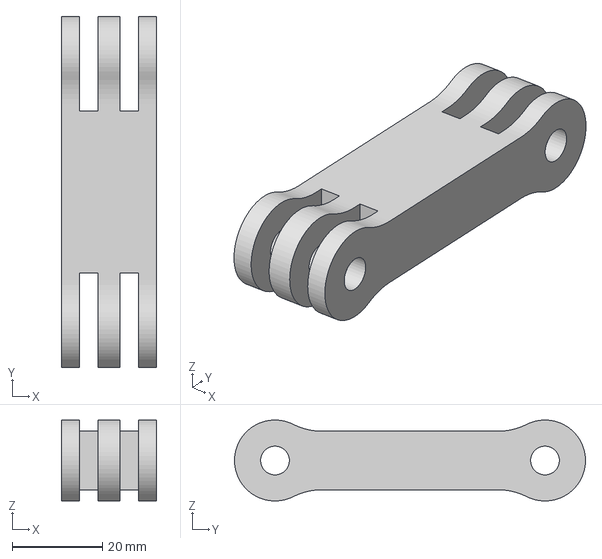
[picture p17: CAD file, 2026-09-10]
3D Models/3D Printing/Clamp/Strut-m6.3mf
21.2 x 78.0 x 18.0 mm

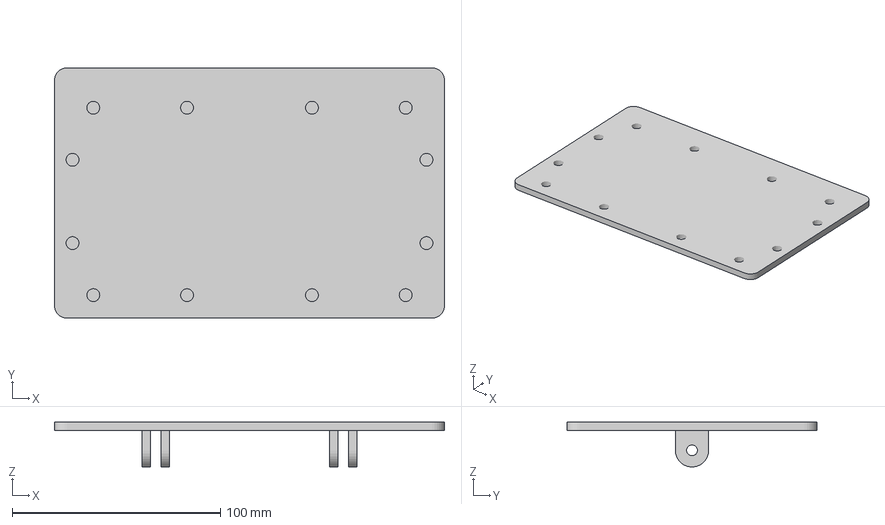
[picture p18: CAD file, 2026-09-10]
3D Models/3D Printing/Clamp/Mount Plate.3mf
187.3 x 120.2 x 21.6 mm

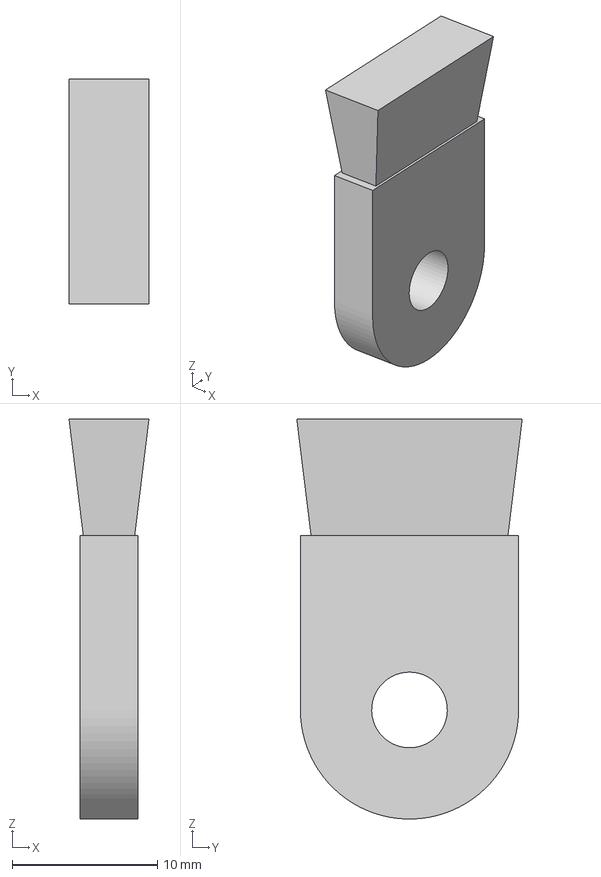
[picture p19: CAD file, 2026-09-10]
3D Models/3D Printing/Clamp/Clamp Ear.3mf
5.50 x 15.5 x 27.5 mm

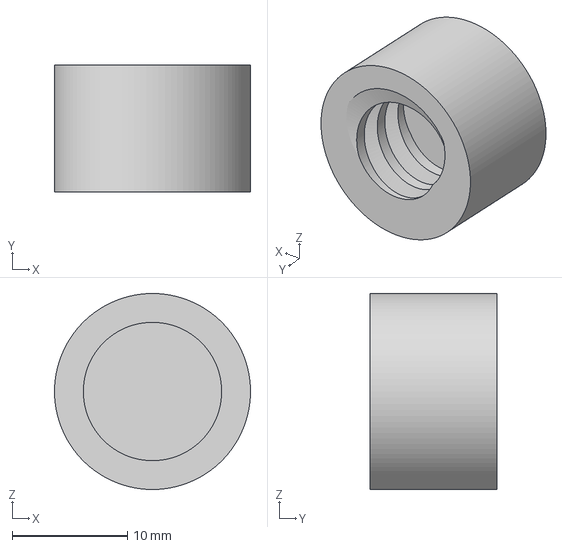
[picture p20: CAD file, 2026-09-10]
3D Models/3D Printing/Clamp/Clamp Pad.3mf
17.0 x 11.0 x 17.0 mm

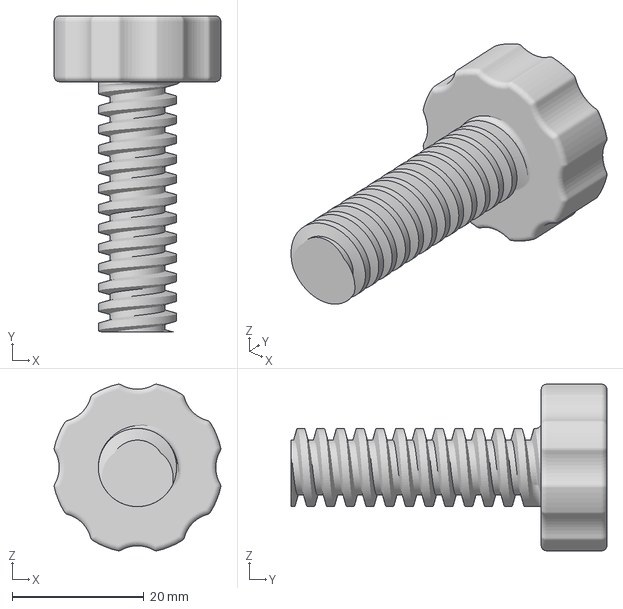
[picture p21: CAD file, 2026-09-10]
3D Models/3D Printing/Clamp/Clamp Screw.3mf
25.3 x 48.0 x 25.3 mm

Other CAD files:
3D Models/3D Printing/Clamp/Strut-m5.3mf

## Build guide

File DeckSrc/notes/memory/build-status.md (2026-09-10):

---
name: build-status
type: goal
---

As of 2026-09-09:

- **Bottom Case** — printed once, but has changed since (cavity corner fillets
  R4, locating pins 3.00 -> 2.60), so it needs a reprint.
- **Grid** — never printed; outer corners changed to R3. **Its purpose is now
  in question**: with the keycaps gone it is a bezel rather than a carrier of
  15 openings, and has not been redesigned for that.
- **Key Carrier** — **obsolete.** It existed to hold a plexi keycap over four
  switches; there are no keycaps and no switches. Not yet removed in Fusion.
- **Top Cover, Base Plate** — not reported as printed.
- **Strut** — designed (60 mm between pivots, 78 mm overall, three prongs at
  both ends, print two), not printed.
- **Electronics** — nothing to wire. The switch matrix and the MCP23017 are out
  of the design; the panel's own touch controller is the input.

**Why it matters:** two parts are known-stale versus the current model, and two
more are now solving a problem the design no longer has - printing either would
waste filament on a dead interface. Update this note as parts get printed.
See [[fusion-source-of-truth]], [[touch-input]].

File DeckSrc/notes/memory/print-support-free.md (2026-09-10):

---
name: print-support-free
type: constraint
---

Every part must print without support. Slicer is Bambu Studio; the workflow is
iterative test prints rather than one final print.

Consequences already baked into the design: the Grid's pockets open downward
(switch pushed in from below) and the Key Carriers are printed flipped.

**Why it matters:** a geometry change that adds an overhang is a design bug, not
a slicer problem.

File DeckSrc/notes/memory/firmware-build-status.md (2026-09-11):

---
name: firmware-build-status
type: goal
---

As of 2026-09-11 the panel runs the full Decky firmware (protocol 7), built
locally as `fw=0.1.4-dirty` and not yet released: pages sent by the desktop,
widgets patched with `LIVE`, wheels, the volume dial and 3D dice drawn by the
deck, every page warmed while loading, 2 KB upload blocks, and `reset=` in `ID`.
Since the evening of 2026-09-11 also sliding text and ring arcs drawn by the
deck itself (`slide=1`, `sweep=1` in `ID`), with VSYNC timed from the ISR so the
loop never blocks on it. Factory firmware has been erased (backup in
`factory-backup/` at the repo root). The touch test of 2026-09-09 is long gone.

Structure: `lib/panel` owns the RGB bus, timing, backlight, frame buffers, beam
timing **and the GT911** - the only place that knows GPIO numbers. `lib/keygrid`
owns the layout, the millimetre-to-pixel conversion and `hit()`, which turns a
touch point back into a key index. Since 2026-09-11 `src/` is in folders by
area, one class or two each, all owned by a `Deck` (`src/deck/deck.h`); the
firmware README's Layout section maps them. A restructure is checked on the deck
by a golden run: every command in a fixed order, replies and screen captures
compared with the build before (see [[firmware-golden-run]]).

**Touch is the input.** Reversed 2026-09-09; the earlier "permanently out of
scope" is gone. See [[touch-input]] and
[[decisions/2026-09-09-touch-instead-of-switches]].

**GIF animation playback is gone.** The player (`lib/gifcell`, `lib/gifassets`,
`lib/sdlock`), its generator `tools/make_gifs.py` and the test GIFs in `assets/`
were deleted on 2026-09-10 at the user's request. The repository had been
re-initialised before that, so no copy survives in git. Animated keys would have
to be rebuilt; [[gif-encoding-for-the-panel]] keeps the decoder lessons.

The `ID` handshake is kept, so the desktop app still finds the board.

**Why it matters:** do not look for the animation code in the tree or in git
history; it is not there.

See [[flashing-the-panel]], [[panel-pclk-limit]], [[screen-tearing-fix]],
[[key-grid-layout]], [[where-content-plays-from]].

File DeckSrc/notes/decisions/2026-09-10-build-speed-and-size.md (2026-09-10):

---
date: 2026-09-10
status: accepted
---

# Faster releases and a smaller installer, without lossy shortcuts

**Context:** the user asked for a smaller bundle and faster builds. Measured
first: a release took about 7 minutes, 4 of them the firmware job, and 2.5 of
those were PlatformIO downloading and unpacking its platform, framework and
libraries on a fresh runner. Every new version recompiled all 194 firmware
files, because the version was a compiler flag. The installer was 110.9 MiB, of
which the app's own files are about 5 MiB; the rest is Electron. The measuring
also found that the installed app had no 3D model: electron-builder's default
ignore list drops `*.obj`.

**Choice:**

- The firmware version moves from a compiler flag to a generated header that
  only `main.cpp` includes. A new version rebuilds 1 file in 17 s instead of 194
  in 58 s.
- A release whose firmware did not change downloads the zip already released
  under that version and checks every image's SHA-256, instead of rebuilding. If
  anything fails, it builds.
- When the firmware is built, `~/.platformio` and the libraries are cached. The
  key is platformio.ini plus the exact Python version, because PlatformIO's venv
  is tied to it. The download archives are left out of the cache.
- The installer ships only the `en-US` Chromium locale and only the win32-x64
  serial binding. It leaves out source maps, serialport's C++ sources and
  node-addon-api. esptool-js becomes a devDependency: Vite already bundles it,
  so its `node_modules` copy, with pako, was dead weight.
- The model ships as a GLB, converted by `scripts/convert-model.mjs`. It keeps
  the OBJ's float32 vertices bit for bit and is 1.37 MB instead of 6.3. The
  render is byte-identical to the OBJ's.
- The two backgrounds become lossless WebP: pixel-exact and about 42% smaller.
- `scripts/package-check.mjs` fails the release if any built file is missing
  from `app.asar`.

**Measured:**

| | Before | After |
| --- | --- | --- |
| Installer | 116.2 MB | 106.3 MB, now with the model |
| Unpacked | 383 MB | 330 MB |
| `app.asar` | 13.4 MB  | 10.1 MB |
| Local electron-builder | 31 s | 23 s |

The CI savings are estimates until the next releases run: about 4 minutes on a
release without firmware changes, and about 2 when the firmware changes.

**Rejected:**

- _Solid 7z compression (`differentialPackage: false`)._ −9.7 MiB, but
  compression went from 10 s to 63 s here, and CI runs about 4× slower. A 16 MB
  dictionary would be the middle ground (−7.4 MiB, 22 s), but electron-builder
  does not expose it. The two goals conflicted, and speed won.
- _Lossy WebP for the backgrounds._ 70% of neighbouring pixels differ by
  dither-sized steps. The backgrounds are dithered on purpose, and q85 moved
  some pixels by 55 levels.
- _Deleting `dxcompiler.dll` / `dxil.dll`._ −6.6 MiB. WebGL does not use them,
  but it was not tested on other GPUs, and a broken first screen costs more than
  6 MiB.
- _A compiled-object cache in CI (`build_cache_dir`)._ About 45 s more per
  firmware release. Builds are not byte-reproducible (the ELF hash in the app
  descriptor changes every build), so a stale object could not be ruled out by
  comparing outputs.
- _Raising the firmware build's job count._ `-j 12` built in the same 60 s as
  Elecrow's cap of 4. The local time is not CPU-bound.
- _Caching Electron's downloads on Windows._ The CI log shows them taking under
  a second.

**Accepted afterwards:** differential updates. The user agreed to a fourth
release file if downloads got faster. The `.blockmap` is now uploaded, and an
app-only update measured 3.2 MB instead of 101.4 MB. This is also why solid
compression stays off: it would defeat the blockmap. The original note read:
uploading the `.blockmap` as a fourth release file would let updates download
only the changed parts. The user chose the short file list before this was
measured.

See [[release-pipeline]], [[packaging-drops-files]].

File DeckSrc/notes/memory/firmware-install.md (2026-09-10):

---
name: firmware-install
type: constraint
---

The desktop app installs firmware over USB with esptool-js: the four images
PlatformIO's upload writes (bootloader 0x0, partition table 0x8000, boot_app0
0xE000, app 0x10000), each MD5-verified on the chip, at 460800 baud. It never
writes NVS (0x9000: Wi-Fi credentials, pairing secret) or anything from 0x210000
on, and never the merged `firmware.factory.bin`, which runs through NVS. Key
artwork is on the microSD card and untouched by any install.

Packages come from `desktop/resources/firmware/` (written by the PlatformIO
post-build script `scripts/bundle_for_desktop.py`) or the newest GitHub release
(zipped as `decky-firmware-<version>.zip`), both as `manifest.json` plus images with SHA-256 and MD5. The firmware version
is read from the manifest, never from the release tag. See [[release-pipeline]].
The protocol number lives only in `firmware/include/decky_version.h`.

Two traps, found on the real board: `serialport`'s `set()` asserts any line left
out, so both DTR and RTS are always sent; and esptool-js 0.6.1's
`after("hard_reset")` never resets the chip, so the flasher pulses RTS itself.

**Why it matters:** writing NVS silently unpairs the deck and forgets its Wi-Fi;
either trap makes a healthy deck look dead after an install.

See [[flashing-the-panel]], [[decisions/2026-09-10-desktop-flasher]].

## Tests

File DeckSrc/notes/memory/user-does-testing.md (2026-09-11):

---
name: user-does-testing
description:
  The user tests features on the deck and in the app themselves; Claude builds,
  checks the code, and hands over
metadata:
  type: feedback
---

From 2026-09-11 the user does the hands-on testing: "from now let me do the
tests not you".

**Why:** said while Claude was about to flash again and probe the deck (SCREEN
captures, golden runs) to check a new feature. Those runs hold COM5, restart the
deck, and take minutes.

**How to apply:**

- Don't run probes, golden runs or SCREEN captures on the deck, and don't flash
  it just to check something. Don't launch the app to test a feature, unless the
  user asks.
- Code-only checks are still fine: typecheck, lint, unit tests, a firmware
  compile (no upload), and the headless UI check (`scripts/ui-check.mjs`, a
  browser against fakes - neither the deck nor the user's app).
- Hand over with what to try, and what to look for in each case.
- While the user is testing, hold edits that would hot-reload the running app
  until they are done, or ask first.

Related: [[visual-tweaks-checked-by-hand]], [[firmware-golden-run]].

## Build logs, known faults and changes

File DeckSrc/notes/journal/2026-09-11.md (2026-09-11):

# 2026-09-11

Decky 0.2.4 with firmware 0.1.3 released overnight: 6 min 43 s end to end,
including a cold-cache firmware build. It has four files: the installer (106.3
MB), its blockmap, `latest.yml` and the firmware zip.

The README plays the demo video. GitHub strips `<video>` tags pointing into the
repository, so the user uploaded it as a GitHub attachment instead. The upload
was compressed from 41 MB to 9.3 MB (720p60, SSIM 0.998) to fit the 10 MB limit
for attachments on free accounts. Both MP4s were committed by the user anyway.

## First install over factory firmware

The board was restored to Elecrow's factory firmware from
`factory-backup/crowpanel7-factory-4MB.bin`, leaving NVS alone so Wi-Fi and
pairing survived. The factory image boots its LVGL Widgets Demo and never
answers `ID`. Its partition table differs from Decky's: app0 is 3840 KB against
2048 KB, with NVS at the same place.

What the user saw, and what changed:

- **The card showed up 12-16 s after plugging in.** A silent port is now asked
  twice a second apart within one status check, and a newly plugged-in port
  triggers a check within a second. Estimated now: about 6 s, with Wi-Fi tried
  first for a paired deck.
- **Four steps became one question,** "Install Decky on this device?". The click
  checks it is a CrowPanel and installs; anything else is left untouched. It
  still waits for the click, because the check restarts the device. The card was
  redesigned, and "Looking for Decky…" hides while it shows.
- **The install message showed the git version.** It now uses the same plain
  number as the rest of the app; `formatVersion` moved to
  `src/shared/firmware.ts`.

## The picture slip, found

After the first install the picture sat 48 lines too high, wrapped. On the
slipped deck, `DISPLAY_RESYNC` (`esp_lcd_panel_init`) left it shifted, which
disproved the earlier realign theory.

Diagnostic firmware read the RGB driver's private bookkeeping at every VSYNC:

- **Correct state:** `pos=76800`, 10 EOFs per frame, even count.
- **Provoking it:** random 30 ms flash erases on the unused data partition
  showed frames losing EOFs (as few as 1 per frame). By the second stall the
  picture stayed slipped, with an odd count and nothing else different.
- **Nudging the count by one** straightened it, confirmed on the screen.

The v5.5.4 source explains why the slip lasts: with RESTART_IN_VSYNC, the driver
never zeroes the count. The fix zeroes it in our VSYNC callback. It survived 40
random stalls with 75 corrections, and a first install through the app now
leaves the picture straight, confirmed by the user. The old realign calls are
gone; `DISPLAY_STATE` stays for diagnosis. The user had also found a forum
thread describing the same drift and blaming bounce-buffer synchronisation. See
[[2026-09-11-bounce-parity-guard]].

## Page switching

The user felt page switches as "not instant". Measured with a temporary
benchmark on the deck, a full page redraw took 83 ms. About 45 ms of that was
copying: each key was copied pixel by pixel with an integer division per pixel.
The rest was waiting on the beam. Two firmware changes:

- **Line-by-line copy:** each key row goes with one memcpy (or a column table
  for off-size cells). That brought the redraw to 61 ms; a key write now costs
  about 2.1 ms, the PSRAM-to-PSRAM floor beside the scanout.
- **Greedy order:** keys are drawn as soon as their row is clear of the beam,
  instead of in index order. That brought it to 35 ms.

The write estimate now eases back down instead of only ratcheting up.
`DISPLAY_STATE` reports the last redraw as `draw=`. The user confirmed switches
feel instant.

Back-to-Home still lagged slightly. With protocol 4 and later, opening a page
was `CACHE`, then an `ALT` check per toggle key, then `STATE`, each a Wi-Fi
round trip: 4 for Home with two Discord toggles, against 2 for other pages. The
app now remembers the pages and the ON artwork it confirmed on the deck this
session, and opens those with a single `STATE`. If the deck has dropped the
page, `STATE` is refused and the full exchange runs.

## Widgets

Widget keys: clock (digital, analog or minimal; 12/24-hour; seconds; date; time
zone), timer, pomodoro, countdown, counter, ping and note, each with its own
settings, under a Widgets group in the action picker. The desktop draws them.
Pages carry time-free base pictures, and the deck gets `LIVE` tile patches while
a page is shown. Firmware 0.1.4-dirty on COM5 reports `live=1` and passed a
hardware script: 21 ms for a small patch, about 94 ms for the worst seconds
change, and a wrong base refused. A critic reviewed the transport; see
[[2026-09-11-widgets-live-patches]].

Feedback from the user testing it in the dev app:

- **12-hour time dropped the leading zero** ("2:39" beside "02:39"). Hours are
  two digits in both formats now, in the minimal style too.
- **A moved widget appeared twice on the deck,** once in the app. A digital
  clock's base picture is only its background, like an empty key's, so the move
  changed neither the page's signature nor any picture. The deck's copy kept the
  clock drawn by patches. The app now tracks patched keys per deck copy: it
  re-sends them on rebuilds and restores them on cached pages. A simulated-deck
  test reproduces the bug.
- **Holds waited for the release.** A hold now acts the moment the press reaches
  600 ms, so a stopwatch shows its reset under the finger.
- **"Server status" became "Ping"**, for everyday use. ICMP to the internet
  never answers on this PC, which is behind a VPN adapter, while TCP to port 443
  answers in 16-46 ms. So the widget times a TCP handshake, with a second one
  raced after 500 ms because 1 handshake in 30 was lost, and falls back to
  ping.exe for hosts that answer no TCP. The router answered that way in 1 ms.

## Countdown wheel and the picker

- **Countdown set on the deck.** A timer in countdown mode can have "Set time on
  the deck". At rest its key shows a picker wheel, and a swipe steps it every 15
  px: 10 s steps to a minute, minutes to an hour, 5 minutes to 3 hours. The user
  chose this design (a wheel on the key, snapping steps, adaptive steps) over a
  multi-key picker page and a smooth scroll run on the deck.
  - **Firmware:** `DRAG <mask>` plus `EV … MOVE <y>`, gated by `drag=1`.
    Released apps would take an unknown `EV` line as a command's reply, so the
    deck reports movement only for keys the app names.
  - **Measured:** a wheel step's patch is 0.8-3 KB, about 40-130 ms over USB, so
    live frames are now coalesced per key.
  - **First try on the deck:** swiping started the countdown. The deck still had
    the old firmware, with no `MOVE`, so every touch was a tap. Flashed: `ID`
    shows `drag=1` and `DRAG` answers `OK drag`.
  - **Tests:** a simulated-deck test covers swipe, tap and a swipe while it
    runs.
- **Picker.** Widgets moved behind a Widgets row with its own panel and Back.
  After picking, a ‹ in the editor returns to the panel the choice was made in,
  until the key is first saved.

## The wheel moves onto the deck

The user wanted the countdown wheel to follow the finger in real time, with
iPhone-style momentum and snapping. App-drawn steps "teleported": each patch
takes 40-130 ms over USB. The user set a rule: animated or heavy keys run on the
deck, static or occasional ones in the app ([[deck-first-for-animation]]).

- **Built:** `firmware/src/wheel.cpp`.
  - **The look:** the desktop sends it once (`WHEEL`). It holds the key picture
    under the numbers as a `LIVE` patch, the digits at two sizes rasterised in
    the app's Segoe UI (not embedding the font), the 89 labels, and the drum and
    physics settings. The deck keeps four looks by CRC, and `WHEELAT` re-arms
    one with a single line.
  - **Drawing:** the deck draws a drum (labels at `row/angle · sin θ`, squashed
    by `cos θ`, faded by `cos² θ`) that follows the finger 1:1.
  - **Motion:** a flick glides with exponential decay (τ 0.32 s) until below 4
    labels/s. A critically damped spring (ω 16) then lands it on a label, and it
    bounces at the ends. It reports `EV … WHEEL <label>` when it stops.
  - **Tearing:** frames are composed before the beam check, so only the copy has
    to fit between the beam's passes.
- **Measured on the deck** with the real 15 KB look generated by the app's code:
  - the upload took 1.06 s over USB; each frame composes in 4.3 ms, at 61-67
    fps;
  - `WHEELSPIN` +30/s moved 9 labels and settled in 1.08 s;
  - −60/s ran into the start, bounced and settled in 1.22 s;
  - a mid-spin screen capture shows two rows straddling the band, so the motion
    is continuous, not stepped.
- **App:**
  - an adjustable countdown at rest is handed to the deck (`wheelKey`) instead
    of receiving pictures;
  - a tap starts it, and the first `LIVE` picture ends the wheel;
  - on firmware without `wheel=1` the app-stepped wheel remains.
  - The preview draws the same drum with the shared `drumRow` sums.
  - The feel constants travel in the look, so tuning needs no reflash.
- **Tests:** spec round trip and rejection, the drum geometry, and the whole
  arm, settle, swipe and tap cycle against the simulated deck.
- **Not yet seen with a real finger or the real app:** the user was away.

## Countdown sound

- **The sound:** the user wanted a soft, looping sound when a countdown ends,
  played by the PC. Five synthesised candidates went to them as WAV files (soft
  bell, glass fifth, kalimba, ding-dong, airy chime); they rejected a listening
  page and picked the kalimba.
- **Built:** countdowns have "Sound when it ends", on by default.
  - **Looping:** `kalimba.wav` is one 2-second cycle, its tail faded to silence,
    and loops until the key is tapped.
  - **Stopping:** a tap on an ended countdown now resets it (it used to restart
    it) and stops the sound.
- **Checks:**
  - The UI check pushes an ended countdown into the app and checks the kalimba
    starts, then that resetting stops it.
  - `pnpm package` confirmed the `.wav` ships.

## Seven more widgets

- **Asked for:** now playing, volume dial, system monitor, network speed,
  microphone status, dice and crypto price. The user wanted them good-looking
  rather than flat, minimal, customisable without over-engineering, and each
  with a style choice. For crypto: a chart or a price with an up/down arrow,
  plus an interval. For now playing: art, title and progress. They went to sleep
  and asked for no questions.
- **Built:**
  - each widget has two styles, drawn live side by side in the editor from
    made-up readings (`samples.ts`);
  - the Widgets panel now holds 14, in an order for daily use.
- **Windows readings** go through one persistent PowerShell helper:
  - Core Audio through a C# shim, for volume, mute and the microphone;
  - WinRT media sessions, for the track, its position and the cover, read once
    per track;
  - network counters of physical adapters only.
- **Measured on the user's PC:** audio 23 ms, network 21 ms, media 63 ms (with a
  16.8 KB cover) and 2 ms once cached; the helper starts in 555 ms. CoinGecko
  answered in 330 ms, TRY included.
- **Deck-first, per the user's rule:**
  - the volume is a dial the deck turns (`dial=1`, a version 2 look of 7-24 KB)
    and reports every 40 ms;
  - dice are a drum the deck rolls to the face the app picked (`WHEELROLL`).
- **Found and fixed while testing:**
  - dice neighbours showed at rest (`DICE_FEEL`, fade 1);
  - a second tap mid-roll would have spun the drum backwards (rolls now go on
    from the last target);
  - the ticker showed the day's change in the arrow's colour, even when the two
    disagreed (each is now coloured by its own direction);
  - a hold on System claimed to open Task Manager.
- **Checks:**
  - typecheck and lint clean;
  - 125 tests, including the feeds against a mocked helper, the dial look round
    trip, and the volume dial and dice against the simulated deck;
  - UI check (14 widgets, crypto settings saved);
  - the disconnected check.
- **Not flashed:** the user's dev app held COM5, and it is not to be killed. The
  firmware builds. Its hardware test (`scratchpad/looks.json`: arm the arc, bar,
  die and list looks, turn, roll, time the frames) waits for the port.

## The user's review, and a night's list

- **Feedback on the new widgets:** "Die" should read "Dice"; the network
  widget's KB/s did not fit - then "remove network"; crypto in dollars only;
  microphone: keep the first style, no "Muted" text. They could not find Now
  playing or Volume at first (the widgets panel scrolls); search now matches
  what a widget is for ("music", "spotify").
- **Removed:** the network widget, crypto currencies and interval, the
  microphone's badge style. Old profiles load with those dropped
  (`retireWidgets`); without it the whole configuration was refused.
- **The die, made 3D on the deck** ([[2026-09-11-deck-dice]]): a cube rendered
  and thrown by the firmware, bouncing off the key's edges and lying wherever it
  stops. Simulating first showed the obvious throw was unfair (40% starting
  face); the fix is a Haar-random end pose reached exactly. 53-56 fps on the
  deck after `-O2`/fast-math and a row-by-row renderer (from 21).
- **Asked before sleeping:** instant mic and volume with no polling, live
  prices, other pages' widgets loaded at boot, a faster deck, and the app not
  editable while the deck boots.
  - Sound: Core Audio callbacks in the helper; taps shown at once. Verified end
    to end on this PC: the key changed 1 ms after a tap.
  - Prices: Binance's public WebSocket, a price a second; verified live.
  - Boot: every page's widget pictures and looks sent while the deck loads,
    counted in its progress; hidden pages kept current afterwards; the app shows
    "Decky is starting" until then.
  - Faster uploads: 2 KB blocks after `BLOCK` - a 24 KB look 0.8 s, from 1.7 s
    ([[usb-upload-blocks]]). A bug in my own test script (ignoring `READY`'s
    size) looked like lost bytes and sent me down two wrong theories before I
    found it; an A/B then showed the receive buffer alone does it.
- **Checks:** typecheck and lint clean, 132 tests (new: feeds with live audio
  and prices, the arrow's minute, profile migration, the die's look and pose,
  the boot warm-up on the simulated deck), UI and connection checks (loading
  before the reveal). Firmware flashed and tested on the deck: die throws, block
  sizes, looks kept ahead.
- **Not tested with the real app and deck together:** the boot warm-up and the
  booting screen ran against the simulated deck and the UI harness only - the
  user's app was closed.

## The deck restarted itself; the volume arc

- **The restart:** on starting the app the deck restarted, the app logged
  `the deck did not answer` and then `error code 31`, and after that it no
  longer found the deck. Error 31 is the CH340 USB adapter wedged: only a replug
  brought it back, and a flash could not reach it until then.
- **Not a firmware crash.** The core dump partition was empty after it. To know
  whether an empty partition means anything, a deliberate `abort()` build was
  flashed and made to crash: it left a dump that decoded to the right line, so
  this build does write dumps. The first restart was therefore most likely power
  (a brownout or dip), which also fits the adapter wedging. The test dump was
  erased afterwards and the test command removed before the final flash.
- **Diagnostics now in place:** `reset=` in `ID` (why the deck last started);
  `%APPDATA%/Decky/deck.log`, recording crash, watchdog and brownout restarts, a
  deck that started again while connected, uploads it did not answer, and stray
  lines it printed; the Disconnected screen tells you to replug when Windows
  reports the adapter not working. How to read a dump is in the firmware README.
- **Volume arc:** at 56% a white stretch showed again near the end of the arc.
  The fill map measured each pixel's angle from the arc's start but wrapped it
  at the wrong point, so the last part of the arc read as near 0% and filled at
  any level. Now it wraps in the middle of the gap. A test pins it, and the deck
  showed 0/20/56/85/100 correctly. Dials already on the deck keep the old map
  until the app restarts and sends the new look.
- **Also:** die speed and bounce are bounded on both sides (an unbounded look
  could make the physics run away).
- **Checks:** typecheck, lint, 133 tests, UI, connection and package checks
  pass. The firmware on the deck is the final build; it answers `reset=poweron`.
- **Still not proven:** why the power dipped. If it happens again, `deck.log`
  will say `brownout` or `panic`.

## Sliding song titles

- **Asked:** a Now playing title too long for its key should slide. The user
  chose the loop, for Now playing only.
- **Built** ([[2026-09-11-sliding-text]]): the deck slides it (`SLIDE`,
  `slide=1`). Title and artist each slide only when they don't fit, in both
  styles. It rests 1.5 s, moves at 30 px/s, comes round after a 32 px gap, and
  fades at the edges. Short titles are drawn as before.
- **Checked:** a simulation of the deck's blending on the app's real output,
  then on the deck: at rest, mid-slide, after a progress patch under it (kept
  going), two lines at once, and removed. Lint, 137 tests (new: the format and
  timing; the simulated deck: picture then text, only on change, fresh for each
  new version of a page, loading), build, UI and connection checks. The deck is
  flashed with it.
- **Not yet seen with the real app and a real song:** the user's app was closed.
  It needs a restart to pick up the new code.

## Fast edits; the bar without a number

- **Asked:** changing a widget's style on the Debug page took about 5 s, and
  everything froze meanwhile.
- **Found:** every edit re-sent all 8 live widgets whole (29 KB each) so the
  committed page matched its checksum. Measured on the deck: 10.4 s. The app's
  own drawing was 0.3 s at most, so not the cause.
- **Fixed** ([[2026-09-11-live-layer]], critique logged there):
  - The deck keeps live pictures apart from the page's own, so an edit sends
    only the changed key, as a patch. The same edit now takes 0.66 s; 0.4 s of
    that is the SD card save, left for later.
  - Pages load as patches: the Debug page is 22 KB, not 311 KB.
  - Sliding text travels with its live picture into new versions.
- **Bar volume:** the user asked for the number turned 90° beside the bar, then
  for no number at all. The bar is now nearly the key's height, with no number.
  The dial look says whether the deck writes a number.
- **Checks:** lint, 139 tests (new: an edit sends one patch and keeps every
  widget's picture; the bar look without digits), build, UI and connection
  checks. Flashed, and timed on the deck with the Debug page as the app draws
  it.
- **Asked next:** restructure the firmware into folders and classes before
  others try it in a week.

## Firmware in folders and classes

- **Asked:** before others try Decky in a week, split the firmware's two big
  files into folders (buttons/, security/...) with object-oriented, expandable
  code; the app's main process too. Approved structure: deck/, protocol/,
  pages/, display/, input/, keys/ (drum/, dial/, die/, text/), storage/,
  network/, security/, common/, with one `Deck` owning all of it. The buttons
  folder is `keys/`, as the code calls them.
- **Checkpoint first:** three local commits (firmware, app, notes), signed, not
  pushed.
- **Proof it changed nothing:** before touching the code, a golden run on the
  deck recorded 59 replies and two screen captures for a fixed pass through
  every command. The restructured build gave identical replies and
  pixel-identical captures. Die 52-55 fps and drum 70-80 fps, as before.
  - The run is now `tools/golden_run.py` with its fixtures
    ([[firmware-golden-run]]).
  - It had to restart the deck first. Without that, a copy left in RAM, and ON
    pictures on the card, changed two replies between identical builds.
- **Shape:**
  - Each animated kind is a `Look` subclass (what the desktop sends) and a
    `KeyAnimation` (how it moves and draws).
  - Each area's commands are a `CommandSet` behind a router.
  - RAM: 92.7 KB static before, 69.2 KB now, since looks are made as needed.
  - Flash is 20 KB smaller: the unused AnimatedGIF library is gone.
- **One accepted change:** commands are routed by their first word. Garbage like
  "CACHE1 2", which the old sscanf chain took as CACHE, is now unknown.

## Tables, not chains; the app in folders

- **Asked:** a `switch (widget.type)` in the app's press handling "will be
  huge", not object-oriented; then: replace every long `if`/`else` chain with a
  handler table, in both codebases.
- **Firmware:** each command set is a `CommandTable` (a row per command, a
  method per row); looks come from a version table in `Look::parse`; the Wi-Fi
  commands and reset reasons are tables. A golden run after the change matched
  again, and the deck runs it.
- **App**, done by an agent in a worktree, then read and merged by hand:
  - Each widget type is a kind (`shared/widgets/<type>.ts`: settings, defaults,
    validation, press), a view (`renderer/.../widgets/kinds/<type>/`: drawing,
    settings, samples, deck look) and, if a press does more than change its
    state, an action (`main/widgets/actions/`). Three registries, typed so a
    type missing from one does not compile.
  - Step and action kinds, and the serial link's line kinds, are tables too.
  - `main/index.ts` went from 1,839 lines to 152 that build and wire the parts
    in `app/`, `deck/`, `pages/`, `widgets/`, `profile/`, `updates/`, `ipc/`,
    `logging/`.
  - Comments and the README that named the old firmware files now name the new
    ones.
- **Checks, run in the main checkout:** typecheck, lint, 139 tests (1 skipped),
  build, UI and connection checks, package check. No `if`/`else` chain longer
  than three short branches is left; the two `switch`es left are exhaustive over
  small closed enums.
- **Bugs the agent reported while reading, not yet reproduced:**
  - switching a Dice list of 7-8 choices to die mode throws (`yaw` of null);
  - Browse in a step's fields resets the script settings;
  - creating pages does not stop at 64;
  - the warm-up sends drum looks without checking `wheel=1`;
  - crypto style tiles always show $76,904;
  - a style tile's sample time carries over;
  - `MainWindow.send` can run after quitting;
  - macro step state is keyed by index.
- **Checked by reading the code:** seven are real and were there before the
  restructure. The warm-up one is not: every firmware with `warm=1` also has
  `wheel=1` and `dial=1`.

## The card save off the edit

- **Asked:** a small freeze is left when a widget's style changes. The user
  proposed a "begin upload" message, a spinner on the deck key and every key
  disabled meanwhile.
- **Found:** the freeze the user sees is on the deck. `COMMIT` saved the whole
  page to the card inside the main loop, before drawing it: 548-569 ms for a
  one-key edit and for a whole page alike, with no touches or frames meanwhile.
  A spinner could not have turned during it. The app redraws the page on the
  window's thread (up to 0.3 s), but the user does not notice that.
- **Chosen (the user):** remove the freezes rather than signal them.
- **Done:** `COMMIT` draws first, then `artwork_store` saves in steps (open, 8
  KB slices, swap) run once per loop pass. One save at a time; loading, `SDINFO`
  and `PageCache::start` finish it first. A failed save shows as `stored=0` in
  the next `COMMIT` reply.
- **Measured on the deck:**
  - `COMMIT` replies in 6 ms, down from 569.
  - A small edit takes 66-86 ms from `CACHE` to the reply.
  - During the save `PING` answers every 11-13 ms, a few times up to 45 ms.
  - After a restart the page loads from the card (`cached=1 storage=sd`).
  - The golden run is identical.
- **Not done:** the app-side parts of the approach (drawing off the window's
  thread, a spinner on the app's key tile for long uploads). The user does not
  see an app freeze.
- **Asked next:** the microphone widget with the volume's arc and bar styles.

## The microphone as a level

- **Asked:** the microphone widget in the volume's arc and bar styles. The user
  chose arc and bar only: the old icon style goes, and existing mic keys become
  arcs when the profile loads (`retire`).
- **Built:** the mic shows and sets the default microphone's level, turned on
  the deck like the volume; a tap mutes. Turning it never unmutes it (the
  speaker does, as Windows' slider does), so a stray swipe cannot open the mic.
  - The helper's sound requests take the device: `level` and `mute` with its
    flow, and `audio` answers `{speaker, microphone}`.
  - `WidgetFeeds` keeps a `LevelSetter` per device (newest value wins, echoes
    let pass for 400 ms); one `SoundAction(device)` replaces the mute and volume
    actions; the deck's `VALUE` goes to the widget action's `turned`.
- **The user's correction:** my first cut had `volume-view.ts` and
  `mic-view.ts`, near-identical wrappers around a shared `level-dial.ts`. The
  user asked for one generic module that the caller tells what it is. Now:
  `levelKind(...)` in shared, one `kinds/level/` folder whose
  `levelView(device)` the registry calls for each type, with per-device icons,
  hint and sample in its `DEVICES` table. Recorded as [[generic-over-copies]].
- **Checked:** typecheck, lint, 142 tests (new: each dial sets its own device, a
  tap mutes its own, nothing without an armed dial; the mic's level never
  unmutes it), build, UI and connection checks. The changed helper was run
  directly: it read both devices, and writing back the mic's current level and
  mute left them as they were. Not yet seen on the deck with the real app.

## Double and triple taps

- **Asked:** double and triple taps, starting with Now playing: a double tap
  skips to the next track. The user chose widgets only (not per-key actions in
  the editor), and a hold on Now playing now goes back a track.
- **Built, in the app only:** the deck already reports each finger down and up,
  and its 120 ms press gap is measured press to press, so a double tap's second
  press gets through.
  - Each widget action has a `gestures` table (`tap`, `double`, `triple`,
    `hold`) in place of `press(..., hold)`.
  - `TapRuns` (`main/widgets/tap-runs.ts`) counts taps on a key. Only a widget
    with `double` or `triple` waits `TAP_GAP_MS` (300 ms) after a tap; at the
    most it knows it acts at once. A hold or a swipe drops the taps just before
    it. A run is continued only by a tap soon after, so a press the deck never
    finished leaves nothing behind.
  - Now playing: tap play/pause, double next, triple or hold previous
    (`media-previous` in the Windows helper).
- **The cost:** a single tap on Now playing plays or pauses 300 ms after the
  finger lifts. Every other key is as it was.
- **Checked:** typecheck, lint, 148 tests (new: one, two and three taps, a hold
  after a tap, slow taps, a widget that acts at once), build, UI and connection
  checks. The helper still answers; `media-previous` was not sent, since it
  would have skipped the user's music. Not yet tried on the deck.

## The dice that stopped rolling

- **Reported:** after the day's changes the dice "doesn't work for a while",
  then suddenly works.
- **Evidence:**
  - The deck log had nothing since 12:52: no restart, no refused upload.
  - The profile's Debug page has four keys the deck turns: the adjustable
    countdown, the dice, the volume and, since today, the mic.
  - The dice's saved state had a face and no `rest`: the app had rolled it
    itself because the deck no longer had it armed.
  - `AnimatedKeys` kept four looks, and a new one dropped the look armed least
    lately, and every key armed with it. The golden reference itself held the
    symptom: `WHEELAT 0 timer -> ERR wheel unknown` after five looks.
- **Reproduced on the deck:** arm the dice, a drum and two dials, then one new
  look on the mic's key (what a mute makes). The dice's `WHEELROLL` went from
  `OK roll` to `ERR invalid wheel`. The app ignored that reply, and kept the
  dice as armed ("Unchanged"), so taps did nothing until something re-sent the
  page.
- **Ruled out on the way:** the stepped card save (a probe that seemed to break
  `WHEEL` after `COMMIT` had only skipped `STATE`, which shows a page `CACHE`
  only stores), and multi-taps (the dice acts on its tap at once).
- **Fixed:**
  - Firmware: a look for every key and one more, never dropping one a key is
    armed with. Unused looks go first, least lately armed, and when PSRAM is
    short (`memory::spare`, now shared with live pictures): `ERR wheel memory`
    if there is still no room.
  - App: a refused roll makes the app roll in its place and forget the arming,
    so decks on older firmware recover too.
- **Checked:** the reproduction now keeps rolling. Five armed keys kept their
  looks through 20 more sent ahead. The golden run differed exactly where
  intended (key 0's drum stays), and was recorded again. Two of its screen dumps
  came back 44 and 137 bytes short, then the same sequence came back whole:
  plain dumps on a fresh deck were whole three times, so the loss is on the USB
  side, not the firmware's. App: typecheck, lint, 148 tests (the simulated deck
  now refuses rolls on unarmed keys; the new test fails without the fix), build,
  UI and connection checks.

## Boot loads everything

- **Asked:** the first mute on the volume or the mic waited about a second, then
  every toggle after was instant. The user: boot should load every cache and
  every state, for every widget and button, so nothing lags afterwards.
- **Found:**
  - Loading sent each deck-turned key's look for its state then only. A mute
    greys a dial: a look of its own, which travelled on the first mute. On the
    deck: the arc's 25.5 KB look takes 889 ms (the bar's 223 ms), while arming a
    look it keeps takes 20 ms.
  - A countdown running while loading got no drum look at all, so stopping it
    would have sent one.
  - The keystroke helper (PowerShell) started on the first hotkey press, about
    half a second by its own comment; a stopped action also killed it.
  - Everything else checked was already loaded: all pages, toggles' ON pictures,
    every widget's picture and sliding text, the Windows helper, pings, prices.
    Scripts and programs start a process per press by design.
- **Done:**
  - `lookKeys` picks every key the deck turns now or at rest, with the page
    shown last. `deckLooks` builds every look a key can take (both mutes). The
    window keeps 96 built looks rather than 24, and main keeps the last 32 looks
    sent at boot rather than the first.
  - `ActionRunner.prepare` starts the keystroke helper at boot, and when a
    hotkey is first added. `cancel` leaves it up; only `stop`, on quitting, ends
    it.
- **Checked:** 153 tests (new: which keys send looks and in what order, every
  look a key can take, the helper starting and staying up), typecheck, lint,
  build, UI and connection checks. Not yet seen with the real app.
- **Left as a limit:** more than 8 pages do not fit in the deck's memory, and
  then loading preloads nothing (`cachePages` refuses).

## OBS, as the first of the apps

- **Asked:** OBS on the deck. Hotkeys already switch scenes and mute; what they
  cannot do is show state. So: recording and streaming indicators.
  - A touch shows a 5-second countdown on the key; another touch calls it off.
  - Adding an OBS key checks OBS is installed, and says "OBS not found" if not.
  - Then, before the UI was built: treat OBS as one member of a third-party
    family, since more apps will come.
  - Picker chosen: Actions → Apps → OBS.
  - Asked in passing: find retired widgets from the widget registry instead of a
    `RETIRED_WIDGETS` list. `retireWidget` now says whether the type exists.
- **Built** ([[2026-09-11-integrations]]):
  - Shared: the `Integration` declaration and `INTEGRATIONS`.
  - Main: `IntegrationService`, the settings store (secrets encrypted), and
    `obs/`: `ObsLink` (obs-websocket 5 with the password proof), `OBS_FINDER`,
    and `ObsService` (the link while any OBS key exists, state per key, the
    countdown).
  - The window: `obsView(output)`, the picker's panel table (Apps, each app's
    page, Back at each step), Settings → Apps cards drawn from the fields, and a
    status line in the OBS key's editor.
  - `WidgetReadings` holds pings, feeds and the integrations.
  - Along the way: `errorText` replaced five copies of Electron's error
    clean-up, and the picker's entry row became `picker-entry`.
- **Checked:**
  - Typecheck, lint, 164 tests. New: the link against a simulated OBS, including
    obs-websocket's documented password example; the service's standings,
    countdown, events, settings, and letting go.
  - Build; UI checks (the Apps pages, and the OBS card: status, save, saved
    password); connection and package checks.
  - The finder on this PC: OBS installed (registry), not running.
  - Not yet tried against a running OBS.

## Discord: mute state and Rich Presence

- **Asked:** detect Discord's mute and deafen on Windows, tested. Then: show
  Rich Presence while Decky runs, without shipping credentials (Decky is open
  source).
- **Found** ([[discord-mute-state]], [[discord-rich-presence]]):
  - Local storage `MediaEngineStore` holds `default.mute` / `default.deaf`.
    Eight slow clicks came through in order. Three bursts timed against click
    times were saved 5.0, 5.2 and 5.1 s after their first click; toggles undone
    within the 5 s never reached the disk.
  - RPC over `discord-ipc-0`: the handshake works, voice settings answer `4006`
    without OAuth. The `rpc` scope is for the app owner and 50 testers only, so
    the user's own app cannot serve other users, and its secret must not ship.
  - UI Automation: a tray-hidden Discord exposes no web content.
  - Rich Presence with only the app ID: accepted. As "Playing" it stayed hidden
    behind VS Code's presence; as "Watching" it showed.
- **Checked:** by hand on this PC (Discord 1.0.9256), with throwaway scripts
  kept out of the repo. The RPC route with the user's own app (instant events,
  toggling) was not tried: no secret was given.
- **Later the same evening:**
  - A live presence fed by local storage: the user judged 5 s too slow.
  - The user's own app, with its secret, was refused `rpc` and `rpc.voice.read`
    at the Authorize click (`invalid_scope`). The secret was pasted into the
    chat, so it has to be reset.
  - StreamKit's app ID and token endpoint gave realtime events: 11 toggles in 11
    s, each shown in 5-41 ms. After rapid toggling the presence display lagged
    (Discord throttles activity updates); the events did not.
  - What the StreamKit token (`rpc` only) allows, probed without changing
    anything:
    - **Allowed:** reading and writing voice settings (mute, deafen, mic and
      output device and volume, noise suppression, echo, AGC, voice mode); the
      current voice channel; servers and channels; the soundboard list (175
      sounds); subscribing to `VOICE_SETTINGS_UPDATE`, `VOICE_CHANNEL_SELECT`,
      `VOICE_CONNECTION_STATUS` and `GUILD_STATUS`.
    - **Refused (`4006`):** `PLAY_SOUNDBOARD_SOUND` (needs `rpc.voice.write`)
      and `NOTIFICATION_CREATE` (needs `rpc.notifications.read`).
    - **Untried:** speaking and voice-state events (they need a call), and
      camera and screen-share toggles.
  - Later ([[discord-rpc-control]]): the extra scopes were granted, channel
    members were read without joining, and a lab script was handed to the user
    for the camera and share toggles.
  - **Streamer Mode** kept switching on: Discord's `autoToggle` (saved in local
    storage as `StreamerModeStore`) turns it on while OBS runs. With OBS open,
    StreamKit connections in four stages changed nothing. Not tested with OBS
    closed; the user let it go.
- **Open:** nothing built. Choosing between shipping the unofficial StreamKit
  route, 5 s local storage, and no Discord mute key. Rich Presence as a
  non-Playing type behind a setting either way.
- **Then, from the user's screenshot:** an OBS key's widget list offered every
  widget. Now an app's widget lists only that app's (Recording, Streaming),
  under the app's name, and other widgets no app's. The editor's ‹ said "Back to
  actions" after an app pick; every Back button now names its panel
  (`panelName`), so it says "Back to OBS Studio". The UI check covers both.
- **Then:** "do not put server host password at settings, put it under the OBS
  Studio application panel". The connection card (status, address, password) now
  sits on Apps → OBS Studio under its keys, and in an OBS key's editor; Settings
  has no Apps section. The UI check saves the password on the OBS page and finds
  the card, connected, in the Recording key's editor.

## The Recording key that kept counting

- **Reported:** after the "stopping REC" countdown, the key went on showing the
  recording's time, though OBS had stopped.
- **Evidence, from OBS's own log** (`%APPDATA%\obs-studio\logs`):
  - Decky's link stayed up from 19:38:27 to 19:41:14.
  - Recording Start at 19:39:08, Recording Stop at 19:39:19. So the stop arrived
    and worked.
- **Cause:** on every output event Decky asked OBS for the status again. A stop
  sends "stopping" and "stopped" a millisecond apart. obs-websocket answers
  requests on a pool of threads, so an answer from before the stop can come last
  and keep the key running. A test with a stale status answer reproduced it: it
  failed before the fix.
- **Fixed:** the keys follow the events themselves, which come in order
  (`STATES`: started, stopped, paused, resumed, reconnecting). The time is kept
  from them. The status is asked for only as the link opens. 165 tests, UI and
  connection checks.
- **Also in OBS's log:** "Stream output type 'rtmp_output' failed to start!" at
  19:39:57. OBS itself could not start a stream; nothing was set up to stream
  to.

## OBS keys redesigned; the connection made compact

- **Asked:** the credentials area was too big ("an authorize button and a
  popup"); the REC and LIVE keys did not look good.
- **Seen first:** every key state, drawn by the app's own code in a headless
  Chrome (a throwaway esbuild bundle, scratchpad). Every state was text in a
  black square: REC and LIVE differed by a word, and running was a small red
  dot.
- **Keys now:**
  - Idle: a glyph (record button, broadcast mast) and REC or LIVE.
  - Running: a tally light - on-air red wash and frame, a badge that breathes
    each second, the time large.
  - Paused or reconnecting: amber.
  - Countdown: a ring with "tap to cancel".
  - Unreachable: the glyph dimmed, "OBS" and why.
  - Checked by eye in two renders.
- **Connection:** one line (status dot, a brief standing - new `brief` in the
  app's declaration - and Connect… or Edit) opening a "Connect OBS Studio"
  dialog. The UI check drives it, and saves screenshots of the page and the
  dialog.

## OBS's page: the connection first, a button for each standing

- **Asked:** "OBS is closed" at the top of the OBS page, set off from the
  widgets by a rule, and a button that opens OBS while it is closed. Also: no
  description under OBS Studio on the Apps page.
- **Page:** the connection line, a rule, then Recording and Streaming. The Apps
  row is the name alone; the declaration's `blurb` went with it.
- **Buttons from the declaration** (`buttons`, keyed by standing): closed says
  Open OBS, missing says Get OBS (its `download`, https), and off, denied and
  ready open the settings. The card dispatches `does` through a table. Beside
  Open or Get, a small settings button. While OBS starts, the line says
  "Starting OBS Studio…".
- **Starting OBS:** `ObsFinder.launch` walks one `COPIES` table - the
  installer's folder from the registry plus `bin\64bit\obs64.exe`, started from
  its folder; Steam's `steam://rungameid/1905180`; else the program catalog's
  `obs64.exe`. `installed()` walks the same table. `ObsService.open` starts
  nothing if OBS runs, then tries OBS every 1.5 s for up to 30 s, until it is
  ready or refuses the password. OBS's process comes up before its WebSocket
  server, so a "server off" meanwhile keeps trying.
- **Checked:** 167 tests, including the new open tests with a fake finder.
  Typecheck, lint and prettier (src, tests, scripts) are clean. The build, the
  UI check (a new closed → Open OBS → Connect… walk; screenshot
  `output/decky-obs-closed.png`, looked at) and the disconnected-screen check
  pass. OBS itself was not started from here: "Open OBS" on this PC is for the
  user to try.

## OBS keys out of reach: no words

- **Asked:** the closed, not found, WebSocket off and wrong password states
  should look different; no texts like "closed" or "WebSocket off".
- **Now:** all four draw the idle key greyed, with a slash through the glyph
  (cut from it by a gap in the key's background, as a muted icon's is). OBS's
  card in the app still says which. Checked in a render of every state.

## Smooth rings: the deck moves their arcs (SWEEP)

- **Asked:** the OBS 5-second countdown and the stopwatch "count without lag"
  but step once a second; make them move smoothly. The user chose the deck
  drawing the arc (over the app sending more pictures).
- **Firmware:** a `KeyOverlay` base (keys/overlay.h) that sliding text and the
  new `Sweep` (keys/sweep/) both are. A page copy holds one of each kind per
  key; KeyView composes a key's rows from its picture and lays each overlay over
  them, redrawing only their rows when one moved (`overlay_frames`). `SWEEP`
  goes through one handler with `SLIDE` (`PageCommands::overlay`,
  `OVERLAY_KINDS`). `sweep=1` in `ID`; `DISPLAY_STATE` adds
  `overlays=<frames>/<us>`.
- **The arc:** 32 bytes (`src/shared/sweep-spec.ts`): centre, radius and stroke
  in 1/16 px, colour, opacity, glow and its reach, and the motion - held at a
  share, or `(t - zero) / turn`, once or round. The motion is in the PC's clock
  and `SWEEP`'s line ends with the clock as it is sent, so the payload stays the
  same while the motion holds: a running stopwatch's arc goes once. The deck
  maps each pixel's angle and ring coverage when the arc arrives; a frame
  compares angles with the end and works out the round ends.
- **App:** `timeRing` and `ring` take a motion; `sweepArc` hands the arc to
  `moment.sweeps` where the deck takes it (it must fit 2 px inside the key),
  else paints it. The timer, pomodoro and OBS countdown give motions whose
  numbers are exact integers, so they don't change from second to second.
  Overlays travel together as `KeyOverlays` (`{ slide, sweep }`) through
  `liveKey`, the warmup and main's `LiveKeys`, which tracks both per deck copy
  by CRC. An overlay taken away now goes before the picture without it (for
  slides too); one that comes or changes, after. The key editor's preview paints
  the arcs every frame while they move, as the deck does.
- **Also fixed on the way:** a paused timer or pomodoro drew its track with
  `fade()` of an already faded colour - an invalid colour, so no track.
  `widgetFrame` (unused) went.
- **Checked:** 176 tests (new: the format, the fit rule, the motions, and that
  each ring's arc is identical second to second; SWEEP on the simulated deck).
  Typecheck, lint, build, UI check. Flashed (all parts "Hash of data verified").
  Golden check: every reply and both screens identical but `ID` (the new
  `sweep=1`); the run covers SLIDE, so the overlay refactor changed nothing
  there. The golden reference still predates `sweep=1`.
- **Flashed again** at the user's word, with the `-O2`/fast-math pragma in
  sweep.cpp and the `overlays=` counter (all parts "Hash of data verified"). The
  user then does the testing ("from now let me do the tests not you"), so the
  on-deck probe (still and moving arcs, frame rate) was not run.

## A 10-second countdown on the Debug page is "not that smooth"

- **Found by reading the loop:** the arc is only redrawn from the deck's main
  loop, and the loop was held still in three places:
  - `Screen::resync()` waited for the next VSYNC every 200 ms: up to a frame
    (18.5 ms), five times a second, on every page.
  - A picture for a key of the page shown waited for the beam to clear that key
    (`draw_key`, up to two frames), doing nothing else. The Debug page's 8 live
    widgets bring several such pictures a second.
  - During a transfer, overlays were drawn at most every 15 ms, with touch. A
    hold longer than the ~14 ms a frame leaves between the beam's passes over
    the ring skips a frame: the end sits still, then jumps.
- **Fixed:** the panel's VSYNC interrupt stamps the time
  (`Bus_RGB::lastVSyncMicros`, in the LovyanGFX patch; `panel::last_vsync_us`),
  so `resync()` never waits. `draw_key` draws other keys' overlays while it
  waits for the beam. `between_blocks` draws overlays on every idle poll; touch
  and animations stay every 15 ms. `DISPLAY_STATE` gains `gap=`, the longest the
  loop went without looking at overlays since last asked.
- **Checked:** compiled. Not measured on the deck: the user tests.

## The timer's countdown steps again

- **Asked, after trying it:** "make countdown stepped like before". The Timer's
  countdown ring is drawn into each second's picture again, stepping with its
  digits (`draw-timer.ts` hands a countdown's arc no deck sink). The stopwatch,
  the pomodoro and OBS's 5-second countdown still go to the deck (`SWEEP`) and
  move smoothly.
- **Checked:** 176 tests (the timer tests now check a countdown hands the deck
  nothing and paints its arc as it is at that second), typecheck, lint. The
  firmware fix for loop holds (previous entry) is still compiled, not flashed.

## Only OBS's countdown moves smoothly

- **Asked:** "only obs 5 second smooth other old version pls". The stopwatch and
  the pomodoro step once a second again, as the countdown already did:
  `timeRing` paints its arc at a progress, as before, and hands the deck
  nothing. Only OBS's arming ring goes to the deck (`SWEEP`). The motions for
  the timer and pomodoro, and `pomodoroView`'s `length`/`spent`, went.
- **Kept from the smooth version:** a paused timer or pomodoro shows its faint
  track again (before, a faded colour faded twice was invalid, so no track).
- **Checked:** 175 tests, typecheck, lint. App only; no flash needed. The
  firmware fix for loop holds is still built, not flashed.

## Uneven steps on a 10-second countdown

- **Reported:** the ring stepped unevenly - "20%, then 5%, then another random",
  sometimes two steps at once.
- **Cause, from the code:** the digits count whole seconds, but the ring was
  drawn at `run / total` to the millisecond. And the app redraws every live
  widget key of the page whenever any widget's state changes (`useWidgetLive`'s
  effect depends on all states) - on the Debug page, price ticks, CPU, ping,
  media, many times a second. Each redraw between two seconds put the ring
  somewhere new, and each such picture was a new `LIVE` patch, queueing ahead of
  the next second's.
- **Fixed:** `timerView` and `pomodoroView` give the ring's progress by the
  whole seconds the digits show (a stopwatch: `floor(run / 1000) % 60 / 60`; a
  countdown: `1 - ceil(left / 1000) / seconds`). Now playing's progress line is
  by whole seconds too. Redraws between two seconds now draw the same picture,
  which main never sends.
- **Checked:** 177 tests (new: progress the same anywhere within a second, for
  the timer and the pomodoro), typecheck, lint. App only.
- **Left:** every state change still redraws every key on the page; it costs
  only the drawing now, for widgets whose pictures change by whole seconds.

## Decky on Discord: Rich Presence

- **Asked:** a Settings toggle for Rich Presence as Decky's own application
  (`1548005754705813654`), with cards for what is going on - presses,
  editing, disconnected and more - "cool minimalist", as Watching. Discord
  controls come later (`discord_lab.mjs` from another session has the RPC
  work).
- **The user chose:** presses only, never page or key names; the picture as
  an art asset they upload (`decky`), not an image from the repo.
- **Built:**
  - `shared/presence.ts`: the facts and a table of scenes, most telling
    first. Updating the deck or Decky, Live, Recording (paused), Editing keys,
    Deck disconnected, At the deck; "N presses today" under the live ones;
    timed from when each began.
  - `main/discord/discord-ipc.ts`: the local pipe (handshake, nonce'd
    commands, ping, close), tried on pipes 0-9.
  - `main/discord/presence.ts`: looks at the facts every 2 s, sends only a
    changed card and at most every 4 s, tries Discord again every 15 s,
    clears the card when turned off. It keeps on/off and today's presses in
    `presence.json`.
  - The sources: `session.status`, a new `Updates.updating`,
    `ObsService.presenceOutputs()`, deck key presses (deck-events), and the
    key editor's open/close (`presence:editing`).
  - Settings: a Discord section with the switch and a small copy of the card
    as friends see it, ticking; a line when Discord isn't running.
- **Art:** `output/decky-discord-art.png` (1024 px, the logo on a near-black
  tile), for the user to upload as `decky`.
- **Checked:** 186 tests (new: the scenes, the service with a fake Discord -
  off by default, throttling, retries, turning off, the day rolling over -
  and the pipe client against a fake Discord on a real named pipe),
  typecheck, lint, build, and the headless UI check (switch, card preview,
  editing). Not tried against the real Discord: the user tests.

## Discord keys, through StreamKit

- **Asked:** Discord features from the StreamKit lab (`discord_lab.mjs`): the
  user picked Voice channel, Camera and Screen share, and Mute and Deafen.
  Screen share opens Discord's picker, and Discord should come to the front.
  Mute, deafen, camera and share are toggle buttons with their own ON and OFF
  looks. The voice channel key shows avatars only, "+x" past four, and has a
  button for the current channel. Lucide's brand icons (it has none) go into
  the icon library.
- **Built:**
  - `shared/integrations/discord.ts`: the declaration, with `controls` (each
    with an ON look), Authorize buttons (`does: "authorize"`), and download.
  - `{ kind: "app" }` actions ([[2026-09-11-app-controls]]): `AppControls`,
    `KeyStateStore.follow`, and `isStep` for the runner and key layout.
  - `main/integrations/discord/`: a finder (Stable, PTB, Canary; launches
    through Update.exe) and `DiscordService`. It handles authorize (AUTHORIZE,
    then StreamKit's token endpoint through `net.fetch`; the token kept
    encrypted) and the link. It follows voice settings, the selected channel,
    and each shown channel's members (read again on voice state events, and
    every 15 s). It also covers the controls (SET_VOICE_SETTINGS,
    TOGGLE_VIDEO, TOGGLE_SCREENSHARE and `discord://`), join and leave
    (SELECT_VOICE_CHANNEL), and avatars (Discord's CDN, as data URLs).
  - Camera and share state: the Windows helper's new `capture` request
    (ConsentStore: a use by Discord with a start and no stop). The helper is
    shared, and kept while anyone `hold`s it.
  - The window: the app card's Authorize, and the app's page listing controls,
    then widgets (search finds controls too). The key editor gets a Control
    select and the card. The voice channel widget (`kinds/discord/`) has its
    layouts and a Use current button.
  - Brand icons: `simple-icons` (a dev dependency, CC0), 64 logos as
    `brand:<Title>`, drawn solid a little smaller; 7 in the picker's defaults.
    OBS's app icon is its logo now.
- **Test hygiene found on the way:** the two app-level tests used
  `app.getPath() = "/fixture"`, a real `D:\fixture` on Windows. Once Rich
  Presence's save created that folder, widget state persisted between runs, and
  a countdown was running at the start of the next. Each run now gets a fresh
  temporary folder, removed afterwards; the stray folder is deleted.
- **Checked:** 193 tests (new: Discord's authorize and kept token, mute and
  deafen following and switching, capture from Windows and focus on share, a
  channel's members and avatars with join and leave, a refused token, app
  control validation and following). Typecheck, lint, build. The headless UI
  check walks Apps → Discord: Authorize, the controls, Mute as a toggle, Use
  current. Voice keys rendered in every layout and looked at. Not tried
  against the real Discord: the user tests.

## Discord: more keys, and keys of your own design

- **Asked:** Icon size in Appearance for keys showing their icon. A voice
  channel key the user can design: an icon from the library for an empty
  channel, in the key's colours; the channel name on or off; other layouts.
  Then, from a list of what else Discord allows, the user picked: a mic and
  headset switcher, notifications, leave call, noise suppression, echo
  cancellation, automatic gain, and current call. Also a bug: screen share
  opened Discord's Home (/@me) even with Discord in front; it should only
  come to the front.
- **Built:**
  - `KeyAppearance.iconSize` (40-200 %, 100 saved as nothing) and its slider,
    for any key without an image and any widget that draws the key's icon.
    `drawKeyIcon` (`key-icon-canvas.ts`) draws any library icon on a widget's
    canvas at once (the SVG KeyIcon renders, read into Path2D shapes).
  - `WidgetView.appearance` (a widget's own looks in the Appearance tab) and
    `icon: true` (Appearance picks and sizes its icon). `widgetLook(key)` is
    the one place a key becomes a widget's look.
  - `shared/widgets/discord.ts`: `discordKind`, `voiceKind` and `deviceKind`
    make Voice channel, Current call, Mic switcher (`discord-input`), Output
    switcher (`discord-output`) and Notifications. Voice keys have `layout`
    (grid, row, stack) and `showName`.
  - `IntegrationControl.on` is optional: without it a control is picked as a
    plain key. New controls: noise, echo, gain (toggles), leave (plain; ON
    while in a call as a toggle).
  - `DiscordService` reworked around tables: `SWITCHES` (control → voice
    setting field) makes the switch controls, `CONTROLS` adds camera, share
    and leave, `STATES` gives each Discord widget type its state, and
    `EVENTS` adds SPEAKING_START/STOP and NOTIFICATION_CREATE. Voice settings
    are kept whole (merged, devices a level deeper). Speaking is followed in
    the current call only, unsubscribed on leaving. The notifications scope
    is asked for; a token without it leaves only the Notifications key struck
    through. Avatars no key shows any more are dropped.
  - Screen share's focus: `finder.launch()` (Update.exe --processStart), as
    Discord's shortcuts do, and only when starting a share. A Windows-helper
    SetForegroundWindow op was considered; launching is simpler, also brings
    up a Discord hidden in the tray, and is the path Discord itself handles.
  - Key taps: `DiscordAction` with each type's tap (join or leave, leave,
    next device, open inbox). The inbox opens
    `discord://-/channels/<guild or @me>/<channel>` (GET_CHANNEL for the
    guild) and counts from zero again.
  - Drawings (`kinds/discord/`): `discord-kit.ts` (key icon, struck icon,
    avatars, caps), `draw-voice.ts` (three layouts, whoever speaks ringed and,
    in a stack, brought to the front), `draw-device.ts` (the part of a device
    name in brackets large, the rest small, a dot per device), `draw-inbox.ts`
    (avatar, Discord's red badge, name).
  - A key replied "Connected to Discord." when pressed between a card check
    and the keys' own link: it now says Decky is still reaching Discord.
- **Checked:** 198 tests (new: noise, echo, gain and leave; current call with
  speaking and leaving; device switching and wrap-around; notifications
  counted, opened in their server or DMs, reset; a token without the
  notifications scope). Typecheck, lint, prettier, build. The UI check walks
  the new controls and widgets, Leave call as a plain key, and a voice key's
  Appearance (Stack, name off, Headset icon at 150 %). Every Discord key
  state rendered at deck size and looked at. Not tried against the real
  Discord: the user tests.

## Flashed: the loop-stall fix and deck-drawn rings

- The user said "flash". Decky was not running and COM5 (the CH340) was free.
  `platformio run -t upload --upload-port COM5` at 460800 with
  `PYTHONIOENCODING=utf-8`. The bootloader, partition table, boot_app0 and
  app (1 184 240 bytes at 0x10000) were each written and each ended with
  `Hash of data verified`; NVS was not touched. The deck was reset by RTS.
- On the deck now: SWEEP (rings' arcs moved by the deck, `sweep=1` in `ID`),
  VSYNC timed from the ISR (`Screen::resync` no longer blocks), `draw_key`
  waiting cooperatively and drawing overlays meanwhile, and
  `overlays=`/`gap=` in DISPLAY_STATE. Not probed after the flash: the user
  tests.

## Krisp, Leave call's states, and state names

- **Krisp:** the user asked for Krisp instead of Standard. Discord keeps them
  apart (`noiseSuppression` is Standard, `noiseCancellation` is Krisp; its
  local storage shows one on, the other off). The RPC cannot reach Krisp:
  Discord's own client code (datamined, `wavedevgit/discord-client-datamining`
  chunk 177235) validates SET_VOICE_SETTINGS with only `noise_suppression`,
  which calls `setNoiseSuppression`. The published docs agree. Told, the user
  let it go; nothing changed.
- A read-only look with the lab's saved StreamKit token failed: Decky's own
  Authorize had ended it, and Discord's refusal repeated the token in its
  error message (dead, only in this session's output). Noted in
  [[discord-rpc-control]].
- **Leave call** is a toggle like the rest: red "Leave call" while in a call,
  the plain look out of one. The optional `on` (plain-key controls) is gone
  again.
- **State names:** each control declares `states` (Unmuted/Muted,
  Undeafened/Deafened, Camera off/on, Not sharing/Sharing, Suppression off/on,
  Cancellation off/on, Auto gain off/on, Not in a call/In a call).
  `stateNames(action)` gives them, or OFF and ON for other toggles. The
  editor's look switch and the dashboard key's corner use them; the toggle
  itself is unchanged.
- **Checked:** typecheck, 198 tests, lint, prettier; the UI check now finds
  Leave call a toggle with "Not in a call" and "In a call".

## Why a waiting notification is not on the Notifications key

- **Reported:** Discord showed 1 notification; the key showed none.
- **Found:** not a bug in Decky. The user authorized again at 23:52 (after
  the notifications scope was added at 23:23), so the key has permission and
  subscribes. Discord's client (datamined: NotificationStore's MESSAGE_CREATE,
  RPCServerManager's handleNotificationCreate) sends NOTIFICATION_CREATE only
  for a new message that would notify, not while its window is focused and not
  while a game with its overlay is in front. No RPC command reads unread
  counts. The window title carries no count; the taskbar button's help text is
  Windows' own ("0 notifications"). A notification from before the link can
  never reach the key.
- Nothing changed in the code. Offered: keep the count across Decky
  restarts.

## Older notifications: asked, not possible; the count kept instead

- **Asked:** could the key fetch older notifications and mentions, surviving
  a Discord restart, sleep, or a Decky restart?
- **Found:** no RPC command reads read state or mention counts. `GET_CHANNEL`
  (datamined chunk 90924) fetches a channel's last messages but carries no
  read state, and DMs cannot be listed over RPC. Discord's REST API with the
  user's own account token could, but that is self-botting against Discord's
  terms: refused.
- **Built:** the key's count, last sender and channel are kept in
  `integrations/discord.json` beside the token (`keep()`, one write at a
  time; `inboxOf` reads it back). A restart of Decky or Discord keeps the
  count; notifications that come while Decky is not linked are still missed.
  Test: a second service on the same file shows the count.
- The console text the user pasted ("Quitting secondary instance", a
  punycode warning, "blackbox") is Discord's second copy, started by Decky
  to bring Discord up, handing over and quitting. It reaches the dev terminal
  because Update.exe attaches to its parent's console. Harmless; none in a
  packaged Decky.

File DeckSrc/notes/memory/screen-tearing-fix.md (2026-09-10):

---
name: screen-tearing-fix
type: constraint
---

Drawing goes straight into the frame buffer the panel is scanning out, so a
region written while the beam is crossing it tears - the part below the split
shows the new frame, the part above the old one. It looks like a horizontal
glitch partway down a moving shape.

The fix is not double buffering. Copying a 768 KB frame per refresh would cost
more PSRAM bandwidth than the artefacts budget allows and would bring back the
DMA artefacts described in [[panel-pclk-limit]]. Instead the beam position is
tracked - `panel::wait_vsync()` gives a reference point, and elapsed time maps
to a scanline - and a cell is only written when the beam is clear of it, either
far enough above that the write finishes first, or already past it.

Two things make this work: the write must be fast relative to the frame (turbo
mode cut a cell from ~2.4 ms to ~0.6 ms, against a 20 ms frame), and the estimate
of how long a write takes must be pessimistic. Underestimating it starts a write
too close to the beam, which is the tear it is meant to prevent.

Cost is about 5% of the frame rate. Frames are deferred, not dropped.

A full page redraw writes the fifteen keys greedily: each one goes out as soon as
its row is clear, rather than in index order. Some row is always clear, so a page
costs about 35 ms. That is mostly the copies themselves - about 2.1 ms a key,
PSRAM to PSRAM beside the scanout, with one memcpy per row. The write estimate is
still twice the write and jumps up at once, but it eases back down, so one slow
write no longer narrows every later window.

**Why it matters:** the instinct is to reach for double buffering, which on this
board is the expensive wrong answer.

See [[firmware-build-status]].

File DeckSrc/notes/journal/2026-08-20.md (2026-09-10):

# 2026-08-20

## Imported project context from Claude Desktop

Claude Code's memory and Claude Desktop's memory are separate stores with no
sync between them, so the accumulated Desktop context for this build was pasted
in by hand and written into `notes/` here. `notes/` did not exist before today;
it was scaffolded in this session along with the project `CLAUDE.md`.

Nothing in the design changed today — this was context transfer only.

### Dimension snapshot at import

Recorded here rather than in `memory/` because Fusion is the source of truth
([[fusion-source-of-truth]]) and these will go stale. Treat as "what was true on
2026-08-20", not as authoritative.

Deck parts:

| Part | Dimensions (mm) | Notes |
| --- | --- | --- |
| Bottom Case | 188.30 x 120.21 x 25.90 | floor 4.5, wall 2.0, outer R6, cavity R4 |
| Grid | 181.00 x 113.71 x 8.00 | corners R3, pockets open downward |
| Base Plate | 181.00 x 113.71 x 1.50 | corners R3 |
| Key Carriers | Z 9.00 .. 14.50 | 15 pcs, printed flipped |
| Top Cover | 188.30 x 120.21 | plate 1.2 |
| Mount Plate | 188.30 x 120.21 x 4.0 | magnet plate, two GoPro clevises at X +-45 |

Closed device: 188.30 x 120.21 x 32.30 mm.

Monitor clamp assembly, parked at X ~220 in the model: Monitor Clamp body,
2 x Clamp Ear (same part), Clamp Pad, Clamp Screw.

Strut: 60 mm between pivots, 78 mm overall, three prongs at both ends, print two.

Open: [[build-status]] — Bottom Case and Grid both need (re)printing against the
current model; electronics not started; project still unnamed
([[open-source-unnamed]]).

## Panel brought up, grid test flashed

The board is alive and now runs our own firmware. Working tree gained
`firmware` (PlatformIO project) and `firmware/factory-backup`
(4 MB image of the shipped flash, read off before erasing).

Getting it to enumerate took most of the session. It did not appear on USB at
all — not even as an unknown device — while the screen was clearly powered. The
CH341SER driver was genuinely missing, but that turned out to be a *consequence*
rather than the cause: Windows only pulls the CH340 driver once the device shows
up. Installing it changed nothing; the port appeared only after the cable was
dealt with. Worth remembering that "no device at all" points at the cable, while
"device with a yellow bang" points at the driver.

Second snag: `read-flash` at the board definition's default 921600 baud returned
corrupt data. 460800 worked and is now pinned.

The firmware itself came up first try — panel init, grid drawn, no VSYNC
timeout. The rendered boundaries close flush on 0 and 800/480, which confirms
the active-area assumption baked into the Fusion design.

Decisions: [[2026-08-20-firmware-toolchain]]
Open: touch (needs PCA9557 init on V3.0), MCP23017 matrix, physically checking
the printed Grid against the rendered one.

## Flicker traced to pixel clock, not to the panel

The first flashed build showed flickering lines *inside* the left-hand cells.
Two things were wrong, and separating them mattered:

1. **Pixel clock too high.** 24 MHz starved the scanline DMA. Dropping to the
   15 MHz in Elecrow's readme fixed it outright. Their own LVGL example uses
   24 MHz, so copying that example's value was the mistake.
2. **Second frame buffer never populated.** Instrumentation that read both
   buffers back showed `lit fb0=14224, lit fb1=0` — the entire grid lived in one
   buffer only. Not what caused the visible flicker, but it would have blanked
   the screen on any buffer switch. Fixed by mirroring fb0 into fb1; verified
   `buffer diff total: 0 px`.

Worth keeping: the symptom that cracked this was "same cells always, background
clean". A moving artefact with a noisy background would have meant bandwidth
starvation of a different kind; a fixed one pointed at timing.

The read-back also confirmed the geometry: 948 lit pixels per cell is exactly the
two-pixel border of a 118x123 rectangle.

Decisions: [[panel-pclk-limit]]

## Firmware given a real structure, and a power cut ate nine notes

The firmware project was renamed from `grid-test` to `streamdeck` — the working
name, not a final one — and split out of its single file:

- `lib/panel` — RGB bus, timing, backlight, frame buffers. The only code that
  knows GPIO numbers.
- `lib/keygrid` — the 5 x 3 layout and the millimetre-to-pixel conversion, kept
  in one place because the panel's pixels are not square and every consumer
  needs both scales.
- `src/main.cpp` — the current screen, which is still the alignment test.

Rebuilt and reflashed; the serial report is byte-identical to before the split
and the frame buffers still differ by zero pixels, so the restructure changed nothing
observable.

Then mains power dropped. Nine `notes/memory/` files came back as pure
whitespace with their byte counts intact — an unflushed-write casualty, the
classic unclean-NTFS-shutdown signature. All nine were rewritten from the
session transcript. The firmware sources, the journal, the decisions note and
`MEMORY.md` survived untouched.

Open: this repo is still not under version control, which is the only reason the
loss needed manual recovery.

## Fifteen animations, and the refresh rate that was never the panel's fault

Put a different animated GIF in each of the 15 key openings as a load test. The
question was whether fifteen concurrent decoders are viable at all; they are,
comfortably. Assets are generated by `tools/make_gifs.py` (Pillow) and compiled
in as C arrays.

The interesting part was the refresh rate. It looked low because it was: 30.8 Hz,
which is what 15 MHz pixel clock buys at this panel's blanking. 15 MHz had been
adopted as the panel's limit after 24 MHz produced flickering lines — but the
limit was never the pixel clock. It was Elecrow's 10-line bounce buffer, too thin
to absorb PSRAM contention. Widening it to 40 lines made 24 MHz clean under full
load: **49.3 Hz, and 15 GIFs still decoding**. The earlier note claiming a 15 MHz
ceiling has been rewritten; it was costing 40% of the refresh rate.

Then tearing showed up — reported precisely enough to diagnose from the
description alone ("the bottom 30% of the line runs ahead"). Fixed by tracking
the beam and writing each cell only when the scanout is clear of it. Double
buffering would have been the expensive wrong answer: a 768 KB copy per refresh
would have spent exactly the PSRAM bandwidth that was just recovered. Turbo
decoding is what made the cheap fix possible — a cell write dropped from ~2.4 ms
to ~0.6 ms, small enough to fit between beam passes. I had dismissed turbo mode
as pointless a few minutes earlier, on the grounds that decode throughput was
already 15× what was needed. Throughput was the wrong metric; latency was the one
that mattered.

Also shipped: the generator now writes the real `.gif` files to `assets/gifs/`
instead of only emitting C arrays. It had been producing a working system with
nothing a human could open, which is how a build ends up unfalsifiable.

Last pass made the motion smooth rather than fast, on request: 16 frames over
0.53 s became 48 over 1.92 s, so the sweeping bar steps 2.5 px instead of 7.4 px.
Two animations that were choppy by design (a blinking cross, a flipping
checkerboard) were replaced with continuous ones. Two others only had 16 and 24
distinct frames because they scroll a repeating pattern on whole-pixel offsets —
drifting them through several pattern periods per loop restored the frame count
without changing the look.

Open: still no way to use an externally supplied GIF — the generator draws them,
it does not ingest them. And the repo is still not under version control.

## Three bugs that all reported success

The animation test went wrong three times in a row, and every one of them showed
healthy numbers while the panel was wrong.

**Blank cells.** Turbo decoding only invokes the draw callback when the draw type
is cooked *and* a canvas has been allocated. Neither was true, so `playFrame()`
returned success, the frame counter climbed, and nothing was written to the
screen. Worse, the "2.4 ms to 0.8 ms" speedup I had reported as a win was
measuring a decoder that had stopped drawing. Fixed by meeting the contract
(`allocFrameBuf` + `GIF_DRAW_COOKED`), which also turns the callback into a
straight copy. Real cost with turbo is ~1.9 ms, and ~4.0 ms once frames became
full-canvas.

The instrument that was missing: frames decoded and scanlines written are now
counted separately. One number could not distinguish "working" from "drawing
nothing", and that is precisely the state it was in.

**Ghosting.** Frames were encoded as differences with transparent unchanged
pixels, so anything that desynchronised the decoder's canvas from the panel left
trails. Switched to full frames. `optimize=False` was not enough - Pillow's frame
differencing is separate from palette optimisation and `disposal=2` is what
disables it. Full frames turned out to encode *smaller* here, so the diffs had
been buying nothing at all.

**Stutter.** Reported per-animation, which made it diagnosable: the bouncing ball
and pulsing square stuck, the sweeping bar and equaliser were smooth. Two
distinct causes. Eased motion crawls at its turning points until consecutive
frames round to identical pixels and get merged into one long frame - a real
pause. And the rotating hand had every frame distinct but moved 6.5 px per step
at the tip against the smooth bar's 2.5 px.

Fixed with constant-rate motion and 72 frames, and the generator now reports
distinct-frames-vs-requested. It immediately caught two more I had not noticed.
One of them was not fixable as designed: a pattern repeating every 16 px can only
ever produce 16 distinct frames however far it scrolls, so `concentric` was
replaced with rotating nested squares.

Settled at 15.3 fps per cell, paced to the ~16 fps ceiling that 4 ms per full
frame across fifteen cells allows, so frames land evenly instead of late.

**Also:** the board's boot loop earlier was a hung `esptool` - a background
upload stuck mid-write for ten minutes, leaving the app partition half erased.
Killing an upload mid-write is how that happens; wait for it or stop it
deliberately, then reflash.

## Live content push, and a decoder that invents colours

The imported GIF glitched - cyan streaks and red pixels that never cleared - and
the way in was to stop describing it and read the panel back. `tools/dump_cell.py`
pulls a key's pixels off the board over serial, so the artefact could be measured
rather than reported: the bad pixels were **in the frame buffer**, which killed
the DMA-starvation theory outright, and the offending colours appear **nowhere in
the source file**.

Bisected from there. Turbo mode off: still corrupt. The library's raw draw path
instead of its cooked one: still corrupt. Our own writes clamped to the cell and
counted: zero escapes. That leaves the LZW decode of difference-encoded frames,
which is not something a caller can configure around. Re-encoding the same file
as full frames rendered it clean - so imported GIFs are now re-encoded rather
than embedded as found.

Two earlier theories died here, both mine: that the artefacts were DMA
contention (they were in memory), and that they were out-of-bounds writes (the
counter said zero).

Then built what was asked for: `tools/push_media.py` puts any image or animation
on any key over the serial port, no reflash. Stills and animations share one
format - a still is a one-frame GIF - so there is one decoder and one class of
bug, and a still costs no CPU once drawn.

The transfer took three measurements to get right. Streaming lost ~110 bytes near
the end; 256-byte blocks still lost bytes; 128-byte blocks arrive intact, which
is exactly the hardware FIFO size. Then the first working version ran at 43 bytes
a second, because the firmware was still waiting for 1024-byte blocks and timing
out on each one. Matching both ends took a 200 KB push from 93 seconds to 8.

A quieter bug surfaced only because a number looked wrong: 151 frames encoding to
3.9 KB. `list(ImageSequence.Iterator(im))` returns many references to one image
object, all sitting on the last frame - so every frame was identical. Fixed by
converting each frame while it is current.

Verified by reading the panel back: a pushed still image renders with its exact
colours, within RGB565 rounding.

## Storage: the 4 MB ceiling, and the card that removes it

Questioned whether the board really only has 4 MB, and asked the chip rather than
trusting the module marking: `esptool flash-id` reports device 0xc84016,
"Detected flash size: 4MB". It is a hard limit. After the bootloader, a 2 MB
application and housekeeping, about 1.9 MB was left for content - enough for one
page of 15 keys, not enough for the multi-page deck this is meant to become.

The panel has a TF slot. Elecrow's wiki gives its pins (MOSI 11, MISO 13, CLK 12,
CS 10, no DIP switch on the Basic model) and they mounted a 16 GB card first try,
so they are now confirmed rather than documented. That ends the storage question
entirely: gigabytes instead of megabytes.

Pushed content now lives on the card at `/sd/deck/k<cell>.gif` and is reloaded at
boot. Verified properly - pushed a still and an animation, reset the board, and
read the panel back: `restored 2 key(s)`, and the pixel counts matched the
pre-reset dump exactly.

That readback also settled a loose end. A patch of cream pixels had appeared in
every dump; after the reboot it swapped places with black. So it is the status
report sharing the serial port and corrupting the binary stream - a fault in the
measuring tool, not on the glass. Worth remembering that the instrument had its
own artefact while it was being used to hunt someone else's.

**Workflow:** `pio run -t upload` hung for minutes three separate times, once
leaving the app partition half erased and the board in a boot loop. It is
abandoned. `tools/flash.ps1` drives esptool directly - 37 s for an app-only
flash, 46 s with `-Full` for bootloader and partition table - and has never hung.

## Decoding moved off the deck entirely

The suggestion was better than the plan it replaced: instead of decoding each
animation once on the board, decode on the PC and send finished frames. The deck
now runs no decoder at all - it copies palette indices through a lookup table.

Measured, all fifteen keys: per-frame cost **4.3 ms to 1.3 ms**, decode time
**2.9 ms to 3 us**, core load **90% to 37%**.

Getting there turned up four things worth keeping:

**The PSRAM "leak" was my own prebake.** 3.3 MB unaccounted for at boot turned
out to be a feature I had written and wired in, doing exactly what it was told.
Instrumenting each boot stage found it in one run; theorising about it had not.

**Uploads write straight to the card now.** Buffering the whole payload in PSRAM
was what capped animation length. A 151-frame clip at full cell size is 2.2 MB
and now works - it simply plays from the card instead of from memory, and the
firmware decides which without being told.

**The card reads at 383 KB/s and nothing shifts it.** Read sizes from 14 KB to
112 KB: 382, 382, 382, 383. SDSPI clock 20 MHz against 40 MHz: 386 against 383.
Both measured before building anything on top of them - read-ahead buffering
would have bought nothing, and I would have built it.

**Streaming belongs on the second core.** Earlier, splitting decode work across
both cores broke the panel by starving its DMA of PSRAM. Streaming is the
opposite load - it waits on SPI and barely touches memory - so the same second
core that was useless for decoding took a streamed frame from 41 ms to 26 ms.
The lesson is that "use both cores" was never the right question; what competes
for PSRAM is.

Also fixed: filling memory to the brim left 283 KB free, and the board rebooted
into a state where nothing loaded at all. There is now a 768 KB floor - content
that would cross it streams. Verified stable: 45 seconds, 23 reports, no reboots.

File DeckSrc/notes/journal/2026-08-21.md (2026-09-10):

# 2026-08-21

## Starved keys, twice, from the same mistake

Keys reported as stuttering: the bottom row rough while the top two were smooth,
then the last keys down to one frame a second and sometimes none at all.

Both were the same bug in two places, and neither was what it looked like.

The first: the main loop served keys in index order, and the panel's scanout
beam also runs top to bottom. By the time a pass reached the bottom row the beam
was late in the frame - exactly when that row is unsafe to write - so those keys
were deferred pass after pass. Ordering by lateness instead of by index removed
the bias.

The second only became visible after adding a per-key report, and the totals had
been hiding it completely: a deck averaging 16 fps had four keys streaming from
the card, one getting 24 fps and three getting **zero**. The card reader also
walked keys in index order, and one full-size streamed key needs 357 KB/s of the
383 KB/s the card provides - so the first key took everything. Serving the most
overdue key each time round gave 6 fps each instead.

Worth keeping: I diagnosed the first one correctly from the description, then
assumed the second was more of the same and was wrong. The per-key numbers took
a minute to add and settled in one reading what three rounds of reasoning had
not. Averages hide starvation by construction.

## Card access needed a lock

Uploading while a key streamed corrupted the transfer at 99% with
ESP_ERR_INVALID_CRC. Two cores were using the card at once - the reader pulling
frames, the upload writing a file - and neither the SDSPI driver nor the FAT
layer tolerates that. Every path that touches the card now takes one recursive
mutex. Uploads hold it for the whole file, so streamed keys freeze while one is
in progress; a pause is a better trade than a corrupted file.

## Also today

The deck now answers `ID` with its own name, protocol version, MAC and key
geometry, so the desktop app can identify it rather than guessing from the USB
chip - which had been reporting the machine's built-in COM1 as a connected deck.
The geometry comes from the device so the layout is described in one place.

Content fills each key edge to edge now: the alignment outlines are gone, and
the host crops to the key's proportions rather than fitting a square inside it.

Boot shows progress on the middle key. Reading fifteen keys off the card takes
several seconds with the backlight already on, and a blank grid for that long
looks like a deck that failed to start.

The SD mount at boot now retries five times. A single attempt failed often
enough that keys came up on their built-in animations while the same card
mounted fine moments later.

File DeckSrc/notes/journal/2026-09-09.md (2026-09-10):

# 2026-09-09

## Touch replaces the switch matrix, and it worked first time

The user dropped the 60 tact switches and the MCP23017 in favour of the panel's
own GT911, with the plexi keycaps and key carriers going too - the finger
touches the glass directly now.

The notes said this was impossible, or at least expensive: touch was recorded as
*permanently* out of scope, with a PCA9557 boot sequence standing between the
firmware and the controller. That was wrong, and finding out cost one grep. The
pinned LovyanGFX ships `LGFX_Elecrow_ESP32_Display_WZ8048C070.h`, whose twenty
RGB pins match `panel.cpp` exactly - so it describes this board, not a cousin -
and its touch block wires the GT911 with `pin_rst = -1`, `pin_int = -1` and no
expander at all. LovyanGFX also already had a GT911 driver compiled into the
build, which tries both possible I2C addresses by itself.

It came up on the first flash: `touch: device at 0x14 <- GT911`, `GT911 ready`.

Worth keeping: the PCA9557 warning was an *Advance* model caveat, and the notes
had already made exactly that mistake once before about the SD card's DIP
switches. Two for two. An Elecrow caveat should be checked against the model
before it is believed.

There is a real PCA9557 on the bus - a second device answers at 0x18 - it is
just not in the way.

## What the board now runs

Fifteen numbered keys over two pages. Bottom right pages forward, bottom left
pages back, numbers run 1 to 27 straight through so a page change is visible
rather than inferred. Presses light the key and print to serial.

The GIF player, SD storage and media push are no longer built, but nothing was
deleted - the libraries are still in the tree and simply unreferenced, so
PlatformIO skips them. The image dropped from 769 KB to 443 KB and boot no
longer waits on the card. The `ID` handshake is kept so the desktop app still
finds the deck.

## Two traps found while flashing

`git init` happened here first, at the user's suggestion, before any of the
rewrite - the repo had no version control at all until today.

The flash appeared to succeed while telling us nothing: esptool's progress bar
killed PlatformIO with a cp1252 `UnicodeEncodeError`, and PlatformIO printed
`[SUCCESS]` anyway. `PYTHONIOENCODING=utf-8` fixes it, and `Hash of data
verified` is the line that actually confirms a write. Also, the board was on
COM5, not the COM4 the notes named.

## Press feedback tore, and the page draw was worse

The user reported the press highlight "sometimes glitching". It was tearing:
`draw_key()` wrote straight into the buffer being scanned out, with no beam
check, because I judged a single key flash too brief to see. Measured, that
judgement was wrong - a key takes 1.65 ms to write and the beam crosses one in
4.8 ms, so roughly a third of presses collide. The repo had already solved this
once; `beam_clear_of()` came back out of the first commit.

Measuring to size the estimate found a second defect I had not been told about
and had asserted the opposite of in a comment: a full page redraw took 43 ms,
**2.1 frames**, so page changes could not "outrun the beam" as claimed and the
bottom row tore. Two fixes: each key was being filled twice, a black rect then a
rounded face over 92% of it, and dropping the redundant clear took a key from
2.88 ms to 1.65 ms and the page to 1.2 frames. Then drawing each key behind the
beam removed the rest, at a cost of half a frame - 33.7 ms for a page against
24.8 unsynchronised.

Worth keeping: the estimate is now measured at boot with the backlight off
rather than carried as a constant. The old build's 8000 us was sized for
decoding a GIF frame and means nothing for drawing a rounded rectangle.

Decisions: [[2026-09-09-touch-instead-of-switches]]
Open: nothing verifies that a finger registers - that is the user's hand test.
The mechanical files still describe carriers and keycaps that no longer exist.

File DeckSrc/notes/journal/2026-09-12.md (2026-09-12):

# 2026-09-12

## App control keys look disabled while their app is out of reach

- **Asked:** while Discord is not connected, every Discord key should look
  disabled - grey, with the slash the widgets already had.
- **Built:**
  - `strike()` in `canvas-kit.ts`: the one slash (grey, cut from what is under
    it by a gap). Discord's widgets, OBS's keys and plain keys use it; OBS's
    look is unchanged.
  - `renderKey(..., disabled)`: the icon grey at 45 % and struck, the label
    grey, an image desaturated and darkened with a slash. `pageFrames` and
    `pageToggleFrames` take the apps down; `keyDisabled` and `downOn` say which
    keys and pages that touches.
  - `useAppsDown(config)`: the window asks each controlled app's standing once
    and follows `integration:status`; an app not heard of counts as reachable.
    `useDecky` puts the page's apps down into its bitmap and sync tokens, so the
    shown page is sent again (only the keys that changed) and other pages follow
    as they open. The dashboard's key faces use it too.
  - Found on the way: `ArtworkPreview` left out `iconSize`, so the window's
    previews of plain keys ignored Icon size while the deck followed it. Fixed.
- **Checked:** typecheck, lint, prettier, 198 tests, the UI check. Plain keys
  rendered normal and disabled (no label, 160 %, coloured background, images)
  beside a Discord widget out of reach, and looked at. Not tried on the deck:
  the user tests.

## The freeze when Discord went and came back

- **Reported:** after quitting Discord and opening it again, things froze at
  first - like the first mute press used to.
- **Found:** my disabled look changed every Discord toggle's ON picture too. The
  deck takes ON pictures (`ALT`) only whole, does not carry them into a new page
  version, and reloads one from its card only by the same checksum - the card
  keeps one per key. So each change of Discord's reach sent every toggle's ON
  picture again, 29 KB each: with 8 Discord toggles about 250 KB over USB,
  several seconds with the deck and the serial queue busy - both when Discord
  went and when it came back.
- **Fixed:** only the OFF picture is drawn disabled. `DiscordService` reports no
  control state while Discord is out of reach (camera and share included), so
  its toggles show OFF, and the ON pictures never change. Measured: normal to
  disabled is a 1.5-3 KB patch per key (Mute 2016 B, back 1537 B), about 20 KB
  for 8 keys.
- The deck may hold the disabled ON pictures the earlier build sent: the first
  sync after this one sends the normal ones once more.
- **Checked:** typecheck, lint, prettier, 198 tests. Not tried on the deck: the
  user tests.

## Device switchers came back in two steps

- **Reported:** after Discord reopened, every Discord key came back at once, but
  the mic and output switchers changed twice.
- **Found** (Discord's client, datamined chunks 90924 and 217090): the RPC's
  voice settings carry the device in use from Discord's saved settings, but
  `available_devices` from its media engine, which lists devices a moment after
  Discord starts. VOICE_SETTINGS_UPDATE is sent at once on SUBSCRIBE and again
  whenever the settings differ, so the list arrived in a second update. The
  switchers drew the first as "reachable, no device" (the icon alone), then the
  device.
- **Fixed:** a switcher stays out of reach while Discord is ready but has no
  device list for its flow. Test: every state the key shows while the list
  arrives late - one change to "ready" (without the fix, two).
- **Checked:** typecheck, lint, prettier, 199 tests.

## Switchers again; Mute while deafened; choice keys

- **Reported:** the mic switcher still changed twice: icon and "Default", then
  disabled, then the real device.
- **Found** (Discord's client: MediaEngineStore, chunk 430452; the id in
  731854): before its media engine lists devices, Discord's list holds one
  stand-in, id `"default"` - the default device's id - named "No Input Devices"
  and marked disabled, which the RPC drops. So the first list was not empty, and
  the earlier fix (empty list) missed it. The disabled step in between cannot
  come from the list (never empty over RPC), so the link most likely dropped
  once while Discord started. Not seen directly: nothing recorded it.
- **Fixed:** a list is "listed" only with more than the stand-in; until then the
  switcher stays out of reach. The test now uses the stand-in; it fails with the
  earlier check.
- **Added:** `discord.log` (`LogFile`, deck.log's code made general): link up,
  how long it lived, Discord's standing when it changed, and each flow's device
  count and the device in use when they change. If a Discord start still
  flickers, it will say whether the link dropped.
- **Asked:** Mute should show muted while deafened. Discord's `isSelfMute`
  counts deafened as muted, but the RPC reports the stored `mute`. Mute's state
  is now `mute` or `deaf`, and a press asks for the opposite of what it shows:
  mute off while deafened, which undeafens, as Discord's own button does.
- **Asked:** are the switchers' cycling and dots generic? They were not. Now:
  `shared/widgets/choice.ts` (`Choice`, `choiceOf`, `nextChoice`) and the
  renderer's `choice-face.ts` draw any key whose state has a `choice`; the key's
  own icon helpers moved to `key-glyph.ts`. The Discord switchers use them.
- **Checked:** typecheck, lint, prettier, 201 tests, the UI check.

## Back from a page opened elsewhere; "Invalid toggle artwork"

- **Reported:** with the Discord and OBS pages opened from keys on the Debug
  page, Back went to Home. And main logged
  `Error occurred in handler for 'pages:cache': Invalid toggle artwork`.
- **Back, found:** Back went to the page's parent, the page it was created
  under. Nothing in the window moves a page under another, so pages made at Home
  and opened from Debug went back Home.
- **Back, changed:** `Workspace` remembers, for each page opened (by a page key,
  or the window), the page it was opened from; Back (the deck's key 11, the
  window's, `page:back`) goes there, else to the parent. Not kept across a
  restart.
- **The error, found:** saving the profile does not wait behind page uploads,
  which queue one after another (`session.serial`). An upload drawn before a
  save that added or removed a toggle key (or a page) reached main after it, and
  its ON pictures no longer matched the profile: thrown as an error, though the
  window draws and sends everything again for the new profile anyway.
- **The error, changed:** such a request is answered
  `{ ok: false, stale: true }` (the pages' ids, or a page's toggle cells, differ
  from the profile now); malformed requests still throw. The window says nothing
  for a stale reply. `Reply.stale` is new.
- **Checked:** typecheck, lint, prettier, 203 tests (new, on the simulated deck:
  a stale cache request; Back through Debug and Home), the UI check.

## A fast unplug while loading: EPIPE, a stuck queue, blank widget keys

- **Reported:** a fast unplug and replug during the loading screen; Decky stayed
  "connected" and did not notice; `deck:live` threw EPIPE ("this socket has been
  ended by the other party"). Widget keys on the Debug page (counter, price, CPU
  and memory, now playing) showed nothing on the deck while the window kept
  drawing them, through page changes; Home's now playing was fine.
- **Found:** the write was on the Wi-Fi socket - the unplug had fallen back to
  it - and the deck's power went with the replug. Nothing watched that socket
  for the deck ending it, and a write to a peer that is gone waits on TCP's own
  timeouts, which are minutes. Every deck command shares one queue, so the PING
  that would have noticed waited behind it: the app went on believing it was
  connected. Meanwhile the deck came back from its card with the pages but no
  live pictures, and the app, holding a record of pictures the deck no longer
  had, sent nothing for a key whose picture had not changed. Not reproduced in a
  test: the reproduction needs the link to hang.
- **Built** (all host-side, so the deck is asked nothing more often):
  - The socket is dropped when the deck ends it ("end", "close"), and a write to
    one that is gone is refused rather than throwing EPIPE.
  - A write over Wi-Fi that takes more than 3 s counts as the link gone: it is
    rejected and the socket destroyed, so the queue moves on.
  - `DeckLink.silentFor` says how long the deck has said nothing. A ping still
    waiting while the deck has been silent for 8 s means the queue is stuck on a
    dead link: the deck counts as gone and the link closes, which frees
    everything waiting.
  - The port watch already noticed a port appear; it notices one go too, and the
    deck's own cable going means the deck is gone at once (`linkLost`).
  - A patch that fails because the deck went is no longer reported as an error;
    the window draws the key again when it is back.
  - HELLO drops every live picture on the deck, so the app now forgets its
    record of them there too (it only forgot the overlays).
- **Checked:** typecheck, lint, prettier, 204 tests (new: a load that fails part
  way, then another, leaves the widget's picture on the deck).
- Line endings: the rebase had checked the tree out as CRLF (core.autocrlf was
  true), which made Prettier fail on every file. autocrlf is off for this
  repository now and the tree is back to LF.

## Designs picked on the key: a hold, dots, and three quiet seconds

- **Asked:** a hold on a clock or a dice key should offer its other looks the
  way Discord's microphone key offers its devices - dots along the bottom, a tap
  to move on - and keep the one showing if nothing is touched for three seconds.
- **Built:** each kind names its own designs (`designs()` in
  `src/shared/widgets/`: a clock's three faces, a die/coin/yes-no/list, a
  level's arc and bar, a track's cover and card), `designsOf()` finds which one
  a widget wears, and `shownWidget()` gives the one under the finger.
  `WidgetPresses` holds what is being picked (`WidgetState.choosing`), moves on
  with every tap, and after `KEEP_MS` hands the design to the profile through
  `Workspace.setWidget`. The key draws it in `drawWidget`, slightly shortened,
  over a dot for each - `dots()` in canvas-kit, which the device switchers'
  faces now share.
- **Two things it needed:** dice held to roll, the same as a tap, so its hold
  never reached the picker - the hold is free now and a tap still rolls. And the
  deck turns a dice or a level key itself, which would hide the preview:
  `deckTurned()` answers null while a design is being picked, so a picture goes
  instead (a picture for a key of the page shown ends its wheel), and the wheel
  comes back once the design is kept.
- The state is only cleared once the profile has the design, so the key does not
  flick back to the old one while the save is in flight.
- **Checked:** typecheck, lint, prettier, 212 tests (8 new in
  `tests/widget-designs.test.ts`), and the keys rendered off-screen to look at:
  preview and dots sit right with and without a label.

## A speed test key, over Speedtest.net's own servers

- **Asked for** a real speed test on a key: download and upload, smooth arcs
  like the volume dial's, a word when it finishes and a tap to run it again.
  Ookla's servers, not Cloudflare's - Cloudflare answers Turkey from Frankfurt.
- **Looked at** sindresorhus/speed-test, which the request pointed to: it pins
  `speedtest-net@1.6.2`, the pure-JS client for Speedtest.net's own endpoints
  (config, the server list's ten mirrors, `latency.txt`, `random<n>x<n>.jpg`,
  `upload.php`), not Ookla's CLI. v2 of that package downloads Ookla's binary
  instead, which does not survive packaging.
- **Built** the same method natively (`src/main/widgets/speedtest.ts`, no new
  dependency): their config for where you are, their list for where the servers
  are, the five nearest pinged three times each, the quickest used, then ten
  seconds each way. Bytes are counted as they stream, the first 1.5 s left out
  for slow start, six streams down and four up - so no correction factor is
  needed, unlike the package's 1.135/1.139.
- The key is an arc the deck sweeps itself: round while it hunts for a server
  (no length to it), once through each transfer (`{zero, turn}`), with the speed
  patched into the middle four times a second.
- **Checked:** typecheck, lint, prettier, 219 tests (6 new, over a made-up line:
  the parsing, the nearest-server pick, a whole run, stopping it, and a line
  that is not there), the UI check, and the key rendered through every phase.
- Python `write_text` on Windows turns into , which made Prettier fail on every
  file it touched; `newline=" "` next time.

## The blank widget keys: the deck was out of room, and said so

- **The trace answered it the first time it happened again.** deck.log, after a
  microphone key was added to Home:
  `live home:13: the deck refused it: ERR live memory (14 since)`, forty times,
  every ten seconds, for ever. Nothing was wrong in the sending path - which is
  why the replay test passed.
- **Why:** the profile has 8 pages, 59 keys, 25 of them widgets. A key picture
  is ~118x122x2 = 29 KB, a page copy's own pictures ~430 KB, and the deck caches
  every page. `live_room()` in `page.cpp` asks for the 768 KB floor plus a whole
  page in one piece before it will allocate one 29 KB live picture, so live
  pictures stop long before PSRAM is full. The microphone key was simply the one
  that tipped it, and Home's now playing and clock went with it.
- **Firmware:** `PageCache::free_lives(keep)` - the oldest copy that is neither
  shown, nor being built, nor the one asking gives up its live pictures, and the
  key tries again. The desktop needs telling nothing: its next patch for an
  evicted key fails the base CRC and it sends the whole key.
- **Desktop, so it helps before a flash:** on `ERR live memory` Decky takes back
  the live pictures of pages that are not shown and retries, and for a minute
  after (`CROWDED_MS`) it leaves hidden pages alone rather than filling the deck
  again. What you are looking at wins.
- **Checked:** typecheck, lint, prettier, 223 tests (new: a deck with room for
  no more live pictures gives the page in front of you the last one), and the
  firmware builds.

## Several profiles, and a profile you can hand to someone

- **Asked for:** profiles beside Pages under the deck, switching only after
  looking inside, and one encrypted `.deckyprofile` that carries everything -
  scripts included - registered with Windows so a double-click offers to import
  it. And: it must catch new credentials, integrations and widgets by itself.
- **Designed** in [[2026-09-12-profiles]] against four answers: files land in
  the profile's own folder with paths rewritten, one key inside Decky
  (obfuscation, said plainly), profiles own app and integration settings, and an
  import always adds rather than replaces.
- **Built:** `profiles.ts` (the list, the folders, adopting the old
  `decky.json`), `bundle.ts` (the file format, AES-256-GCM over gzip, reading
  files a profile uses and placing them safely), `report.ts` (what the inspector
  shows), `Workspace.useProfile/offerFile/inspectFile/takeProfile`, the IPC and
  preload, and the Profiles panel with its inspector.
- **The auto-catch is compile-time**, which is the part worth keeping:
  `ACTION_FILES` and `WIDGET_FILES` are mapped types over every kind, so a new
  action or widget will not compile until it says whether it keeps files and
  whether they travel; integrations are walked from `INTEGRATIONS`, and secrets
  are found by the `secret` flag each field already had.
- **Then, asked about it:** the app now registers the file type itself when it
  is packaged (`system/file-type.ts`, four HKCU keys, written only when they do
  not already point at this exe), which also puts right a Decky that moved. Two
  things were wrong before that: nothing but the installer registered anything,
  and `resources/profile.ico` was inside the asar, where Windows cannot read it
  for the file's icon - it ships unpacked now.
- **Deleting a profile takes two presses**: the bin arms and a tick confirms,
  disarming itself after four seconds.
- **The gaps named, then closed:** every row exports itself now, so the profile
  in use is no longer the only one that can travel; an import lands on what it
  added, where the switch is one press away; and an armed bin says that deleting
  also removes the scripts the profile brought.
- **One of those "gaps" was not one.** A switch already calls
  `PageSync.forget()`, which clears `cacheInitialized`, so the next load sends
  HELLO and the deck drops the pages and live pictures of the profile left
  behind - it does not carry two profiles' pages in the memory that ran out
  yesterday. Now asserted rather than assumed.
- **Left:** the double-click has not been tried on a real install, and none of
  the profile work has met a real deck or the user's own decky.json.
- **Checked:** typecheck, lint, prettier, 238 tests (14 new across profiles, the
  bundle and a switch that keeps each profile's counters apart), and the UI
  check, which now walks Profiles.

## Snake, on the deck

- **Asked for:** an easter egg - five taps on an empty cell open snake, played
  on the deck's own keys, with the screen crushing into falling particles before
  it starts and again when it ends.
- **Chosen, from the options put to the user:** one board seen through the
  fifteen windows (not fifteen boards), swiping to steer with a countdown and
  SWIPE TO MOVE before the first move, and a window that shows the score while
  it is played.
- **Built:** `firmware/src/game/snake.{h,cpp}`, a raw `touched()` on
  `KeyListener`, the loop branch and gating in `deck.cpp`, `GAME snake|off` and
  `game=1`, `EV GAME SCORE|OVER`; on the desktop the event and identity flag,
  the parser, `EmptyTaps` in `deck-events.ts`, `playing` in `use-decky.ts`, the
  `SnakeScreen` over the dashboard and a `game:stop` channel behind its button.
- **The gate is now one predicate.** `!status().shown() && !transitioning` was
  written out at six call sites that draw keys; a game running is a third thing
  that owns the panel, so they all became `Deck::panel_free()`. Commands
  arriving mid-game are still taken - only the drawing waits.
- **A disconnect stops it**: nobody is left to score it, and it would draw over
  the Disconnected notice.
- **Checked:** firmware builds (1195699 B flash, 23.3% RAM) and is bundled,
  typecheck, lint, prettier, 253 tests (9 new: the tap run and the `EV GAME`
  lines), and the UI check, which now plays through the snake screen. The
  Discord test's temp cleanup got the same patience as the others - Windows was
  still holding a debounced save.
- **Left:** it has not met a real deck; the deck in hand is still on the older
  firmware.

## Back on the deck, Home on start, and the update screens

- **Asked:** the deck's Back key did nothing; always start at Home (the user
  chose "Decky starts or the deck restarts" over "only when Decky starts" and
  "after every reconnect"); Update firmware showed "Decky is starting", then
  "The update did not finish / Finish the update".
- **Back:** snake's empty-key check in `deck-events.ts` ran before `runKey`, and
  a nested page's Back key has nothing assigned, so every Back press was counted
  as a tap - five would have started snake. `isBackKey` (`shared/config.ts`)
  keeps it out. Tests: `tests/deck-events.test.ts`.
- **Home:** `homePageId`, the first page. `index.ts` applies it after loading
  the profile, and the `reset` handler (the deck's `BOOT` line, so USB) calls
  `Workspace.home()`, which also clears Back's history. Not over Wi-Fi yet: `ID`
  has no boot marker, and `online=0` also follows a stall - it needs a firmware
  field.
- **Update screens:** the install runs inside the session queue, so `check()`
  waited behind it. The window kept a stale "connected", the cache reset made it
  boot, and "starting" outranks "updating". Just after writing, a deck not
  answering within ~3 s was listed as silent while install progress was still
  set: the rescue offer. Now `DeckSession.flashing` answers checks offline at
  once, and `awaitDeck` asks the port for up to 20 s before the install lets go.
  Tests: `tests/firmware-restart.test.ts`.
- **Checked:** typecheck, lint, 260 tests (8 new). Not yet seen on the deck or
  with a real install.
- **Open - Wi-Fi drops:** deck.log shows `ERR transfer timeout 0/N` (a block
  sent, none of it received in 5 s), the link closing, then 4-14 min to
  reconnect, several times a day; the user sees Disconnected every 10-30 min for
  a couple of minutes. No crash was logged. Two explanations remain: the deck
  off Wi-Fi, or the deck holding a dead connection - Arduino core 3.3.8's
  `NetworkClient::connected()` keeps a peer that closed cleanly (recv 0 with a
  stale errno), keepalive starts after 2 h, and the firmware accepts a new
  client only once the old one is gone. After the 19:06Z drop the deck read its
  pages back from the card (`storage=sd`), which suggests a restart then. Ping
  and UDP watchers are running; no drop caught yet. A watcher's first probe
  reads as silent (Windows Firewall), and a .NET `Ping` loop logged nothing
  through a real outage - ping.exe driven from Node works.

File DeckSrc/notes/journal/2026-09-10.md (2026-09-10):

# 2026-09-10

## Decky desktop and UI refinement

Rewrote the desktop around validated shared configuration, native action execution, a typed preload and feature folders. Added all requested action categories, nested pages, independent toggle artwork, image adjustments, profile recovery and a compatible firmware v2 page cache. Detailed earlier hardware results are in [[decky-desktop]].

The user selected smooth obsidian disconnected artwork, automatic connection retries and a camera transition into the center key. They then selected the floating-grid dashboard with a right editor that appears when selecting a key. Implemented the contextual action picker, compact editors, pages/settings panels and icon dock. Removed old verbose screens.

Follow-up revisions: custom draggable window chrome; tightly fitted white vector logo with transparent app icons; optional labels with centered icons; separate OFF/ON background colors. Tests and build details are in [[decky-desktop]] and desktop/README.md. Generated concepts are retained in desktop/design-concepts/.

Later requests completed: installed-app search with native icons, full Lucide search, independent/visible/background scripts and a 30-second default timeout, duplicate/move/swap keys, accent labels, hover image removal, adjustable centered icon/text gap, and matching live canvas previews. Firmware v3 now preloads configured pages with a centered logo/progress screen and detects application loss. Hardware verified eight pages remain cached even after all are updated; cached switches measured 78–84 ms. BYE and 12-second heartbeat timeout both display Disconnected. Source/build and exact hardware evidence are recorded in [[decky-desktop]]. Avoid repeated full builds and leave launching the app to the user.

Fixed the reported freeze when alternating Mute/Deafen: firmware v4 caches ON artwork per key and uses small STATE commands instead of page snapshots. Both desktop main process and renderer now keep runtime toggle changes out of image sync. Flashed and measured 100 alternating changes on the panel, mean 11.72 ms, no image uploads. Actual framebuffer verified both ON states simultaneously. Regression tests and build passed; details in [[decky-desktop]].

Added wireless setup in Settings and flashed firmware v5. USB provisions Wi-Fi and a paired PC credential; the device saves successful credentials and reconnects, while authenticated TCP carries the existing protocol. Real Wi-Fi scan passed; local socket and UI tests passed. User chooses the actual network/password in Settings and clicks Use Wi-Fi. Details and verification limits in [[decky-desktop]].

After Wi-Fi initialization caused physical LCD drift, added vertical-blank scanout recovery around Wi-Fi/NVS work without changing geometry or timings. Flashed and checked scanning/recovery; user confirmed the screen alignment is fixed.

Persistent wireless boot: firmware v6 now keeps sparse page artwork and both toggle appearances on the existing microSD card, and negotiates 4 KB Wi-Fi blocks. Saved user's actual profile over Wi-Fi, reset the device, verified zero image uploads and 1.569-second SD restoration; total reset-to-ready 9.714 seconds. Details in decky-desktop memory and desktop/output/persistent-cache-check.json. Card was not formatted and unrelated files were untouched.

## Firmware from the app, encrypted Wi-Fi, USB first

The desktop app now installs the deck's firmware itself: Settings → Firmware for updates, and the Disconnected page for a board still on factory firmware. esptool-js was proven on the real board before anything depended on it - ESP32-S3 rev 0.2, flash ID 0x1640c8, four images written and MD5-verified at 460800 baud in 20.8 s. That test found two faults that would have made healthy decks look dead: `serialport`'s `set()` asserts any line left out, and esptool-js 0.6.1's `after("hard_reset")` never resets the chip. Both are handled; the user then installed the protocol-7 firmware from Settings on hardware. Decisions: [[2026-09-10-desktop-flasher]].

Wi-Fi traffic after pairing is AES-128-GCM framed, protocol 7, and the desktop refuses plain-text firmware over Wi-Fi. Covered by framing tests and a fake deck; against the real firmware it still awaits the deck losing its cable while powered. Decisions: [[2026-09-10-encrypted-wifi]].

The connection rule changed several times in one afternoon before settling on USB first, Wi-Fi only without a cable, no manual switch. Decisions: [[2026-09-10-usb-first]].

Also: the CH340 wedged mid-session (Windows error 31 on open) and needed a replug; the Firmware section kept its "installed, restarting" message after the deck came back, fixed by keying it to the deck's firmware; flash-layout wording claimed artwork lived in the flash data partition, when it is on the microSD card.

Moved here from the desktop README, which keeps no measurements: the user's three-page profile saved over Wi-Fi in 8.805 s (21 images, 609,588 payload bytes); after a hardware reset all pages and both ON images loaded from SD in 1.569 s with zero uploads; reset through Wi-Fi reconnection to ready took 9.714 s.

Open: encrypted Wi-Fi on the real firmware; the two release workflows, untested until the GitHub repository exists; the user's question about automatic version numbers.

Settings got a Forget button under Wireless: USB only, asks first, clears the deck's saved network and this PC's pairing file for that deck. The firmware already had WIFI_FORGET; only the desktop was missing the button. Not yet tried on the real deck.

The app, taskbar, installer and tray icon now come from `Branding/logo-app.png` (the thin-stroke mark), trimmed of its ~18% transparent margin so it fills the icon like the old bold one did. The window and tray load the multi-size `icon.ico` instead of the 512 px PNG. The 16 px tray size is soft because the strokes land under 1 px; on a light taskbar the white mark barely shows, which was also true of the old icon. The title-bar logo is unchanged.

Wireless settings, per the user: Forget shows only once the deck is connected (it had appeared while still joining, because the firmware reports the joining network's name), and a successful join closes the network list and password form. The "SD cache ready" line was removed; the no-card warning stays.

Unplugging the deck left the app on the dashboard, and it never fell back to Wi-Fi (the user's power-bank test). Cause, measured on the deck with a script using the app's own `DeckLink`: the serial library closed the port about 1 s after the unplug, but the link kept the dead port object, and the next heartbeat PING's write waited forever. That stalled the single serial queue, so status checks and reconnects never ran again. Fix: drop the port on `close` and refuse writes to a closed port; a unit test reproduces the stall with a fake port. The user confirmed the Disconnected page and the Wi-Fi fallback both work after the fix. The deck was reachable over Wi-Fi throughout (discovery reply and `aesgcm1` challenge at 192.168.1.20).

Published the repository as github.com/Fenish/decky (public). The tag-driven firmware release ran once (firmware-v0.1.0) and the app's own update code downloaded and verified it. The user then asked for fully automatic releases without tags: one release per product-code change, with every build file in it. Replaced both tag workflows with `release.yml` plus `plan_release.py`, whose rules were exercised on a throwaway clone (tools-only, firmware change, [minor], [major], [skip release] and a package.json raise). The app now reads the firmware version from the newest release's manifest. Cleaned up before the first commit: test GIFs, the unused GIF player, old protocol checks and two stray icon exports.

The first automatic release (Decky 0.2.0, firmware 0.1.1) published cleanly and added the firmware-v0.1.1 tag. Then, while the user slept: a title-bar pill counting app and firmware updates, a 15-minute background GitHub check, Settings' firmware section renamed Updates (the pill scrolls to it), and Decky updating itself through electron-updater on a full-window progress screen. A local electron-builder run produced latest.yml, the blockmap and app-update.yml (Fenish/decky), and the packed app contains electron-updater. The real update module passed check, download with progress, SHA-512, cancel, up-to-date and unreachable against a local server; only the silent install and relaunch remain to be seen on a real install. Left uncommitted: every push to main now publishes a release.

The deck came up with its picture shifted up and wrapped. `SCREEN` showed a correct framebuffer; `DISPLAY_RESYNC` changed nothing; an EN-only reset (panel powered) fixed it. The 5.5.4 driver source showed why: with CONFIG_LCD_RGB_RESTART_IN_VSYNC set, `esp_lcd_rgb_panel_restart` is a no-op, so the firmware's Wi-Fi recovery windows had done nothing. The realign now re-runs `esp_lcd_panel_init` (full start, picture kept), once after Wi-Fi activity settles, after warm-up and on command; flashed and run three times without trouble. An early flash was cut off by a PowerShell `Select-Object -First` in the output pipe and redone in full. The deck also boots into Disconnected now; the progress bar waits for HELLO. Not yet confirmed: that repeated power cycles no longer leave the picture shifted.

The deck now shows "Updating Decky" with a progress bar while the desktop app updates itself (`UPDATING <n>` / `UPDATING END`, protocol unchanged). Flashed and checked with `SCREEN` captures: the screen appears, stays past the 12 s host timeout, and `END` restores the page. The bar's track colour first came out wrong because LovyanGFX byte-swaps primitive colours relative to the framebuffer's order. The update screen now shows the download speed. The user's slow 110 MB download was GitHub's CDN right after the release went up, not the app: curl was slow at the same moment. The Disconnected page reads "Decky is offline", with how to reconnect.

## Build speed and installer size

Measured before changing anything:

- A release took about 7 minutes. In the firmware job, 159 of 226 s went to PlatformIO downloading and unpacking. The desktop job spent 60 s in electron-builder, 41 s of it 7-Zip.
- Every new firmware version recompiled all 194 files, because the version was a compiler flag. It is now a generated header: a new version rebuilds `main.cpp` alone, 17 s instead of 58 s.
- A clean local firmware build takes 60 s whether it uses 4 or 12 jobs. The time is not CPU-bound, so Elecrow's cap of 4 stays.

The same measuring turned up a real bug: the installed app never had the 3D model. electron-builder drops `*.obj` from packages by default, and the Disconnected page quietly fell back to its still image. The model is now a GLB made from the CAD OBJ: the same float32 vertices bit for bit, 1.37 MB instead of 6.3 MB, parsed in 4.5 ms instead of about 100 ms. Its headless-Chrome render is byte-identical to the OBJ's. A new `scripts/package-check.mjs` compares the build output with `app.asar` and now runs in the release.

Installer changes:

- English-only Chromium locales, and only the win32-x64 serial binding.
- No source maps, serialport C++ sources or node-addon-api.
- esptool-js moved to devDependencies; the main bundle is byte-identical.
- Lossless WebP for the two backgrounds: pixel-exact. They are dithered, so lossy WebP was rejected.

Results: the installer went from 116.2 MB to 106.3 MB (with the model now included), unpacked from 383 MB to 330 MB, and local electron-builder from 31 s to 23 s. The packaged `Decky.exe` was launched against the deck: UI in 0.97 s, model rendered from the asar at 1.24 s, deck connected over USB. That test used a separate user-data folder and changed nothing of the user's.

CI changes, not yet run on GitHub:

- Unchanged firmware reuses the released zip after checking its SHA-256. Tested against the real releases: 0.1.2 from v0.2.3 and 0.1.1 from v0.2.2; a missing version and a corrupted image both fall back to building.
- Firmware builds cache `~/.platformio` and the libraries.

Solid 7z compression would save 9.7 MiB more but costs about 53 s locally and several times that on CI. It was left off, as recorded in [[2026-09-10-build-speed-and-size]]. The next push releases firmware 0.1.3, so it builds with a cold cache; the reuse path first runs on a desktop-only release.

Differential updates are on; the user accepted a fourth release file ("if download faster okay no problem"). Releases now carry the installer's `.blockmap`, and the app no longer disables differential downloads. Tested between two real local installers, 0.2.0 and 0.2.1 (app code and version changed), through the real electron-updater and Decky's `installAppUpdate`, against a local server that answers single-range requests like GitHub's. The update fetched 3.2 MB of the 101.4 MB installer, in 42 requests, and the result was identical to 0.2.1. With the old installer missing from the cache, it fell back to the full 101.4 MB, again identical. The user's installed 0.2.3 did leave `installer.exe` in `%LOCALAPPDATA%\decky-updater`. The first real differential update is from 0.2.4 onward, because 0.2.3 has it disabled and its release has no blockmap. Solid 7z compression stays off; it would defeat the blockmap.

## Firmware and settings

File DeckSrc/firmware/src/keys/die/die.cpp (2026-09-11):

// The die's physics, 60 times a second beside the scanout: speed over size,
// and fast-math lets min, max and square roots be single FPU steps.
#pragma GCC optimize("O2", "fast-math")
#include "keys/die/die.h"
#include <Arduino.h>
#include <esp_system.h>
#include <math.h>
#include <new>
#include "common/key_image.h"
#include "keys/die/die_shape.h"
#include "keys/die/rotation.h"

namespace keys {
using namespace die_shape;

namespace {
// How it moves: pixels a second squared down, what a landing gives back of a
// hop, how slow it lies down, how the table slows it besides its drag
// (px/s^2), and its gap to the key's edge.
constexpr float GRAVITY = 1500.f, HOP_GIVE = 0.4f, SETTLE_SPEED = 45.f, FRICTION = 90.f, EDGE = 2.f;
constexpr uint32_t SETTLE_MS = 260, DIE_FRAME_MS = 12;

float random01() { return esp_random() / 4294967296.f; }
}  // namespace

// Every number bounded: the physics has no clamp of its own, and a throw of
// 65535 px/s or a hop that long would send the die off into numbers no pixel
// loop is ready for.
bool DieLook::read(ByteReader &r) {
    size = r.u8();
    color = r.u16();
    pip = r.u16();
    speed = r.u16();
    hop = r.u16();
    drag = r.u16() / 100.f;
    bounce = r.u8() / 100.f;
    if (!r.ok || size < 12 || size > min(KeyImage::width(), KeyImage::height()) / 2 || speed <= 0 || speed > 3000 ||
        hop < 20 || hop > 800 || drag <= 0 || drag > 20 || bounce > 1.f)
        return false;
    memset(backdrop_, 0, KeyImage::bytes());
    if (!picture(r, backdrop_)) return false;
    return r.at == r.length;
}

// A die lying with `face` up, turned `yaw` degrees, at (x, y) in 128ths of
// the key: packed face + 8 (x + 128 (y + 128 yaw)).
bool DieLook::accepts(int pose) const { return pose >= 0 && (pose & 7) <= 5 && (pose >> 17) <= 359; }

KeyAnimation *DieLook::animate(int pose, uint16_t *frame) const {
    return new (std::nothrow) Die(*this, pose, frame);
}

Die::Die(const DieLook &look, int pose, uint16_t *frame) : KeyAnimation(look, frame), index_(pose) { set_pose(pose); }

void Die::set_pose(int pose) {
    const int W = KeyImage::width(), H = KeyImage::height();
    const int face = pose & 7, x = (pose >> 3) & 127, y = (pose >> 10) & 127, yaw = pose >> 17;
    const float t = yaw * (PI / 180.f), c = cosf(t), s = sinf(t);
    const float spin[9] = {c, -s, 0, s, c, 0, 0, 0, 1};
    const Face &f = FACES[face];
    // Rows u, v, n: the face's axes onto x and y, its normal onto z.
    const float lying[9] = {static_cast<float>(f.u[0]), static_cast<float>(f.u[1]), static_cast<float>(f.u[2]),
                            static_cast<float>(f.v[0]), static_cast<float>(f.v[1]), static_cast<float>(f.v[2]),
                            static_cast<float>(f.n[0]), static_cast<float>(f.n[1]), static_cast<float>(f.n[2])};
    rotation::multiply(spin, lying, rot_);
    x_ = x * (W - 1) / 127.f;
    y_ = y * (H - 1) / 127.f;
    vx_ = vy_ = h_ = vh_ = 0;
    turn_[0] = turn_[1] = turn_[2] = 0;
    face_ = face;
    dirty_ = true;
}

int Die::pose() const {
    const int W = KeyImage::width(), H = KeyImage::height();
    float u[3];
    rotation::apply(rot_, FACES[face_].u, u);
    int yaw = static_cast<int>(lroundf(atan2f(u[1], u[0]) * 180.f / PI));
    yaw = (yaw % 360 + 360) % 360;
    const int x = constrain(static_cast<int>(lroundf(x_ * 127.f / (W - 1))), 0, 127);
    const int y = constrain(static_cast<int>(lroundf(y_ * 127.f / (H - 1))), 0, 127);
    return face_ + 8 * (x + 128 * (y + 128 * yaw));
}

void Die::reach(float half, float &ex, float &ey) const {
    float view[9];
    viewed(rot_, view);
    ex = half * (fabsf(view[0]) + fabsf(view[1]) + fabsf(view[2]));
    ey = half * (fabsf(view[3]) + fabsf(view[4]) + fabsf(view[5]));
}

// On the table a wall also gives a little hop and a new spin about the
// vertical. In the air it meets the walls as a ball would, so its path does
// not depend on how it is turned - part of what keeps the throw fair.
void Die::walls(float give) {
    const int W = KeyImage::width(), H = KeyImage::height();
    const float half = die().size * 0.5f * (1.f + h_ / HOP_SCALE);
    float ex = half * 1.7320508f, ey = ex;
    if (!flying_) reach(half, ex, ey);
    const float lift = sinf(VIEW_TILT) * h_;
    bool hit = false;
    if (x_ - ex < EDGE) {
        x_ = EDGE + ex;
        if (vx_ < 0) {
            vx_ = -vx_ * give;
            hit = true;
        }
    }
    if (x_ + ex > W - EDGE) {
        x_ = W - EDGE - ex;
        if (vx_ > 0) {
            vx_ = -vx_ * give;
            hit = true;
        }
    }
    if (y_ - lift - ey < EDGE) {
        y_ = EDGE + ey + lift;
        if (vy_ < 0) {
            vy_ = -vy_ * give;
            hit = true;
        }
    }
    if (y_ - lift + ey > H - EDGE) {
        y_ = H - EDGE - ey + lift;
        if (vy_ > 0) {
            vy_ = -vy_ * give;
            hit = true;
        }
    }
    if (hit && mode_ == ROLL && !flying_) {
        turn_[2] += (random01() - 0.5f) * 12.f;
        if (h_ <= 0.5f) vh_ = fmaxf(vh_, 40.f + 40.f * random01());
    }
}

// The axis pointing most nearly up is turned the short way onto straight up.
void Die::lie_down(uint32_t now) {
    int best = 0;
    for (int j = 1; j < 3; ++j)
        if (fabsf(rot_[6 + j]) > fabsf(rot_[6 + best])) best = j;
    const float sign = rot_[6 + best] > 0 ? 1.f : -1.f;
    const float up[3] = {rot_[best] * sign, rot_[3 + best] * sign, rot_[6 + best] * sign};
    // Local +z is face 1, -z 6; +x 2, -x 5; +y 3, -y 4.
    static constexpr int FACE_OF[3][2] = {{1, 4}, {2, 3}, {0, 5}};
    face_ = FACE_OF[best][sign > 0 ? 0 : 1];
    const float length = sqrtf(up[0] * up[0] + up[1] * up[1]);
    angle_ = acosf(constrain(up[2], -1.f, 1.f));
    if (length > 1e-5f) {
        axis_[0] = up[1] / length;
        axis_[1] = -up[0] / length;
    } else {
        axis_[0] = 1;
        axis_[1] = 0;
        angle_ = 0;
    }
    axis_[2] = 0;
    memcpy(from_, rot_, sizeof from_);
    since_ = now;
    mode_ = SETTLE;
}
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

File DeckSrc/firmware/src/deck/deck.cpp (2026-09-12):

#include "deck/deck.h"
#include <Arduino.h>
#include <limits.h>
#include "common/key_image.h"
#include "decky_version.h"
#include "keygrid.h"
#include "network/wireless.h"
#include "panel.h"
#include "protocol/identity.h"
#include "storage/artwork_store.h"

namespace {
Deck *running = nullptr;
void run_command(const char *line) { running->command(line); }
// A page being built that hears nothing for this long is dropped.
constexpr uint32_t PENDING_TIMEOUT_MS = 15000;
// Touch is read between transfer blocks too: widgets keep transfers going in
// normal use, and a tap that began and ended inside one would never be seen.
// Every 15 ms keeps the touch reads from slowing the transfer itself.
constexpr uint32_t TOUCH_DURING_TRANSFER_MS = 15;
}  // namespace

Deck::Deck()
    : status_(screen_),
      view_(screen_, pages_, animations_, session_, status_),
      transfer_(session_, *this),
      session_commands_(*this),
      page_commands_(*this),
      key_commands_(*this) {
    router_.add(session_commands_);
    router_.add(page_commands_);
    router_.add(key_commands_);
}

void Deck::begin() {
    running = this;
    // Room for a whole BLOCK: its bytes wait here while the loop draws.
    Serial.setRxBufferSize(Transfer::SERIAL_BLOCK_MAX * 2);
    Serial.begin(460800);
    // Bytes are passed on from the UART once 32 are in rather than 120, so a
    // block is taken in sooner: 128-byte uploads went 25% faster.
    Serial.setRxFIFOFull(32);
    delay(200);
    wireless::reply().printf("\nDecky v6 - connect the desktop to load your workspace (reset %s)\n", reset_reason());
    panel::touch_bus_scan();
    if (!panel::begin()) return;
    const keygrid::Rect first = keygrid::cell(0);
    KeyImage::set(first.w, first.h);
    // Until a desktop says HELLO there is nothing to load: the deck starts out
    // Disconnected, and the progress bar only appears once the desktop connects.
    panel::display.fillScreen(0);
    panel::present();
    disconnected();
    panel::backlight(true);
    initialized_ = true;
    artwork_store::begin();
    wireless::reply().printf("BOOT decky %d\n", DECKY_PROTOCOL);
    wireless::begin();
}

void Deck::loop() {
    if (!initialized_) {
        vTaskDelay(100);
        return;
    }
    wireless::poll(run_command);
    if (pages_.pending && millis() - pages_.pending_at > PENDING_TIMEOUT_MS) {
        pages_.pending = nullptr;
        session_.transitioning = false;
    }
    screen_.resync();
    const bool updating =
        session_.updating_until && static_cast<int32_t>(session_.updating_until - millis()) > 0;
    if (session_.online && !updating && millis() - session_.last_heard_ms > Session::HOST_TIMEOUT_MS) disconnected();
    touch_.poll(*this);
    if (game_.running()) {
        game_.tick(millis());
        // What it has eaten, when that changes: the window keeps the score.
        if (game_.score() != game_score_) {
            game_score_ = game_.score();
            wireless::events().printf("EV GAME SCORE %d\n", game_score_);
        }
        vTaskDelay(1);
        return;
    }
    if (game_.finished()) {
        game_.taken();
        wireless::events().printf("EV GAME OVER %d\n", game_.score());
        if (pages_.active) view_.draw_page();
    }
    animation_frames();
    view_.overlay_frames();
    artwork_store::step();
    vTaskDelay(1);
}

void Deck::command(const char *line) {
    if (wireless::handle(line)) return;
    if (strcmp(line, "ID") != 0 && strcmp(line, "SCREEN") != 0) wireless::claim();
    session_.heard(millis());
    if (!router_.run(line)) wireless::reply().println("ERR unknown command");
}

void Deck::activate(Page &page) {
    pages_.active = &page;
    session_.current_page = page.id;
    session_.current_state = 0;
    session_.warming = false;
    status_.hide();
}

void Deck::warm_progress() {
    if (!session_.warming) return;
    const int cells = pages_.pending ? __builtin_popcount(pages_.pending->mask) : 0;
    status_.show(15 + (85 * (session_.warm_done + cells)) / max(1, session_.warm_total));
}

void Deck::disconnected() {
    session_.online = false;
    session_.warming = false;
    session_.transitioning = false;
    pages_.pending = nullptr;
    touch_.forget();
    drag_.clear();
    transfer_.reset_block();
    animations_.disarm_all();
    // Overlays and live pictures are the session's: the next desktop sends
    // what it wants, over the pages' own pictures.
    pages_.drop_lives();
    // Nobody is left to score it, and it would draw over the notice.
    game_.stop();
    status_.show(-1, "Disconnected");
}

bool Deck::accepting_presses() {
    // While the game has the panel, a finger is the game's alone.
    return session_.online && !status_.shown() && !session_.transitioning && !game_.running();
}

void Deck::touched(int x, int y, bool down, uint32_t now) {
    if (game_.running()) game_.touched(x, y, down, now);
}

void Deck::start_game() {
    session_.transitioning = false;
    game_.start(millis());
}

void Deck::pressed(int cell, int y, uint32_t now) {
    pressed_page_ = session_.current_page;
    const Page *active = pages_.active;
    // An animation takes the finger itself: no outline, it turns instead.
    const bool turning = active && animations_.armed(cell, active->id, active->signature);
    if (!turning) view_.draw_key(cell, true);
    wireless::events().printf("EV %d %d DOWN\n", pressed_page_, cell);
    const int inside = y - keygrid::cell(cell).y;
    if (drag_.wants(cell)) drag_.report(pressed_page_, cell, inside, now, true);
    if (turning) animations_.touch(cell, inside, now, true);
}

void Deck::moved(int cell, int y, uint32_t now) {
    const Page *active = pages_.active;
    const int inside = y - keygrid::cell(cell).y;
    if (drag_.wants(cell)) drag_.report(pressed_page_, cell, inside, now, false);
    if (active && animations_.armed(cell, active->id, active->signature)) animations_.touch(cell, inside, now, false);
}

void Deck::released(int cell, uint32_t now) {
    const Page *active = pages_.active;
    wireless::events().printf("EV %d %d UP\n", pressed_page_, cell);
    if (active && animations_.armed(cell, active->id, active->signature)) animations_.release(cell, now);
    else if (!session_.transitioning && session_.current_page == pressed_page_) view_.draw_key(cell, false);
}

void Deck::between_blocks() {
    // Overlays move at the panel's pace through transfers, which on a page of
    // live widgets take much of every second; each costs little unless it moved.
    view_.overlay_frames();
    if (millis() - touch_polled_ms_ < TOUCH_DURING_TRANSFER_MS) return;
    touch_polled_ms_ = millis();
    touch_.poll(*this);
    animation_frames();
}
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

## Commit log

2026-09-10 Add enclosure and mount CAD models
    Printable case, clamp and mount parts, the CrowPanel reference model and
    the assembled deck model.
    [3D_File_CrowPanel_7.0-ESP32_HMI-3.0.stp, Bottom Case.3mf, Clamp Ear.3mf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]
2026-09-10 Add deck firmware for the CrowPanel 7" ESP32-S3
    Fifteen touch keys over GT911, pages cached in PSRAM and on microSD,
    and the Decky protocol over USB serial or encrypted Wi-Fi (AES-128-GCM
    after pairing). Builds stamp the version from the firmware tag and
    bundle the images into the desktop app.
    [partitions_deck.csv]
2026-09-10 Add Decky desktop app
    Electron app for Windows: key editor with pages, toggles and artwork,
    program, script, website and hotkey actions with auto-assigned F13-F24
    combinations, and a tray icon. Connects over USB first and falls back to
    Wi-Fi; installs and updates the deck firmware over USB from the bundled
    build or GitHub releases.
    [decky.obj]
2026-09-10 Keep the updates pill readable and noticeable
    A dark frosted pill with a clear hover and a slow glow, which stays still
    when Reduce motion is on. The top-right corner is shaded against the
    background's light streaks; the shade is its own element, because as part
    of the title bar it covered the window buttons with drag area.
2026-09-10 Fix the shifted display and boot into Disconnected
    The picture could come up shifted and wrapped at power-up and stay that
    way until a reset. Realigning did nothing: with RESTART_IN_VSYNC set in
    this framework, esp_lcd_rgb_panel_restart() is a no-op. Realigning now
    re-runs the RGB driver's full start, keeping the picture, once Wi-Fi
    activity settles, after the desktop's warm-up and on DISPLAY_RESYNC.
    The deck also starts on the Disconnected screen; the progress bar waits
    until a desktop says HELLO.
    [Bus_RGB.cpp]
2026-09-10 Move file
    [3D_File_CrowPanel_7.0-ESP32_HMI-3.0.stp]
2026-09-10 Say Decky is offline on the Disconnected page
    The page now reads "Decky is offline", says how to reconnect (a USB data
    cable, or power for Wi-Fi) and shows that it is looking for the deck.
2026-09-10 Ship the deck model as a GLB: the installed app had none
    electron-builder leaves every *.obj file out of the package, so the
    installed Decky never had its 3D model and the Disconnected page fell
    back to a still image. The model is now a GLB made from the CAD export
    by scripts/convert-model.mjs: the same vertices bit for bit, 1.4 MB
    instead of 6.3 MB, and it renders exactly as before.
    [decky.obj]
2026-09-10 Keep the deck's picture from slipping, and redraw pages faster
    The picture could sit 48 lines too high, wrapped, until a reset: after
    power-up, a first install or Wi-Fi activity. Flash writes and Wi-Fi
    calibration hold the display driver's interrupts off, two of them merge
    into one, and the parity the driver uses to pick which bounce buffer to
    refill flips for good - built with RESTART_IN_VSYNC, the driver never
    resets it. The deck now resets it every frame, so a flip lasts one
    frame. On the deck, random flash stalls left the picture slipped within
    two tries before; after, 40 stalls, 75 corrections, never slipped. The
    old realign after Wi-Fi and warm-up never cured it and is gone.
    A page re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
    [Bus_RGB.cpp]
2026-09-10 Set up a deck without Decky in one step, and find it sooner
    A board still on other firmware used to take four steps: "Check device",
    a confirmation, the check, then "Install". The card now asks "Install
    Decky on this device?" straight away; its one button checks that it is
    a CrowPanel and installs, and leaves anything else untouched. It still
    waits for the click, because the check restarts the device - and other
    hardware on the same USB chip, like a 3D printer, must not restart.
    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
2026-09-11 Add live widget keys, and keep edits fast
    Thirteen widgets: clock, timer, pomodoro, countdown, counter, ping, note,
    now playing, volume, microphone, system, crypto and dice. The app draws
    them and patches them onto the deck as they change. Sound and prices
    arrive as events (Core Audio callbacks, Binance's public stream), not
    polls, so mute and volume show at once. Keys the deck can animate are
    handed to it: drums, the volume dial, the die, and song titles too long
    for their key, which slide.
    Loading brings every page's widgets up to date before the app opens, and
    the Disconnected screen says the deck is starting meanwhile. An edit sends
    only the keys that changed, as patches: changing a wid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
2026-09-11 Split the firmware into folders and classes
    One Deck owns every part; main.cpp only makes it and runs it. Each area
    is a folder: deck/, protocol/, pages/, display/, input/, keys/ (drum/,
    dial/, die/, text/), storage/, network/, security/, common/.
    Commands go through a router to the CommandSet that knows them, each a
    table of commands and the methods that parse them. Animated keys are a
    Look subclass (what the desktop sends, from a version table) and a
    KeyAnimation (how it moves and draws). The Wi-Fi commands and reset
    reasons are tables too.
    tools/golden_run.py drives every command the desktop uses and compares
    the replies and two screen captures with a recorded run: identical
    before and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
    [artwork_store.cpp]
2026-09-11 Split the app's main process into parts, and widgets into kinds
    main/index.ts only builds and wires the parts, each in its folder: app/,
    deck/, pages/, widgets/, profile/, updates/, ipc/, logging/.
    Each widget type is a kind (shared/widgets/: its settings, defaults,
    validation, what a press does to it), a view (renderer widgets/kinds/:
    its drawing, settings, sample readings, deck look) and, when a press
    does more than change its state, an action (main/widgets/actions/).
    Each has a registry, typed so a type missing from one does not compile.
    Step and action kinds, and the serial link's kinds of line, are tables
    too.
    Comments name the firmware's new files.
2026-09-11 Make the volume and microphone one kind, and taps a table
    They were near copies of each other. Both are one kind now, made for a
    flow: shared/widgets/level.ts, the renderer's kinds/level/, and main's
    SoundAction. The microphone shows as a level like the volume, with its
    own dial and mute.
    What a press does is a table too. tap-runs.ts counts taps and holds and
    gives the widget's action the gesture it knows (a tap, a double, a
    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
2026-09-11 Add OBS Studio as the first app Decky talks to
    An app is declared once (shared/integrations/): its name, its settings,
    what is said of each standing - not installed, closed, its API off, its
    password refused, connected - and what its card's button does then. The
    window draws its page and its connection card from that, so a new app
    needs no screens of its own; main gives it a service and a row in
    IntegrationServices.
    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
2026-09-11 Let the deck move a ring's arc itself, and keep its loop free
    A ring drawn a second at a time steps; over USB every frame would be a
    key upload. The deck moves the arc now (SWEEP, sweep=1 in ID): the app
    sends where the ring is, where it goes and by when, in 32 bytes, and the
    deck draws each frame between its own blocks. Sliding text works the
    same way, so both are KeyOverlay subclasses on a page, cloned into a new
    version and sent after the picture they belong to.
    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
2026-09-11 Show Decky on Discord, when its owner wants it
    Settings has a Show on Discord switch, off until it is turned on. On,
    friends see "Watching Decky": a line for what is happening - the deck at
    hand, a key being edited, OBS recording or streaming, an update
    installing, the deck unplugged - the presses on the deck today, and for
    how long.
    It goes over Discord's own pipe as Decky's application, with no sign-in
    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
2026-09-11 Add Discord's keys, through StreamKit
    Discord gives RPC to an unapproved application only for its owner, so
    Decky asks as Discord StreamKit Overlay, whose permission any user can
    give: Authorize once, and the token lasts seven days, kept encrypted.
    This is unofficial, and Discord can end it.
    Its controls are toggle keys whose ON and OFF follow Discord, however
    they were switched: mute, deafen, camera, screen share, noise
    suppression, echo cancellation, automatic gain and leave call. Deafened
    counts as muted, as Discord counts it. The window never says ON and OFF
    for them; each control names its two states (Unmuted and Muted, Not in a
    call and In a call). Camera and screen share come from Wi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
2026-09-11 Record the apps, the deck's rings and Discord, and document them
    The READMEs describe the integration family and OBS, Discord's presence
    and its keys, deck-drawn rings and sliding text, icon size and the brand
    logos, choice keys, and how Back and stale page uploads behave.
    The notes keep what the code cannot say: that Discord's RPC has no
    Krisp, no unread counts and no device list for a moment after it starts;
    that its refusal echoes the token; that the deck takes ON pictures
    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
2026-09-12 Say in deck.log why a widget key's picture is not reaching the deck
    A key that stops showing what it should leaves no trace today: the send is
    refused, skipped as unchanged, or never made, and all three look the same
    from outside. Each page load now logs the copy it made, and a widget key
    logs what became of its pictures - at most a line every ten seconds, or a
    minute for one that keeps drawing the picture the deck is thought to hold -
    until it is sending again.
    Also replays the reported case in a test: a key edited on a page of live
    widgets, and a widget key added afterwards, both keep their pictures on the
    deck. It passes, so whatever is wrong is not in this path.
2026-09-12 Let a key's icon size be set back to 100%
    The size slider means "no setting" by 100%, so it hands the editor an
    appearance with no iconSize at all - and the key editor merged that with the
    key it had, where a field left out cannot win. The size sprang back to what
    it was, and the next step over 100 skipped it: 95, then 105.
    Appearance fields are now replaced together (withAppearance), so leaving one
    out takes it away, as removing an image already did by hand. The UI check
    fails if the slider ever springs back off 100.
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2026-09-12 Keep the profiles panel still, and let it wear the theme's scrollbar
    Arming the bin put a warning above the list, which pushed the list down
    under the pointer; it goes to the notice at the foot of the window instead,
    and a row keeps its height while its name is being typed. The rule that
    separated the list from the buttons hung below them, separating nothing - it
    sits above them now, and in the import view under the last line of what the
    profile holds, with the name field clear of it.
    Scrollbars are Decky's everywhere rather than Windows' own: one rule, so a
    scrolling area added later cannot arrive in the wrong colours.
    The UI check walks the import view now - what a profile holds, the wid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
2026-09-12 Watch a firmware update from the screen it leaves you on
    Pressing Update firmware took you to a screen that said "Decky is starting"
    and nothing else: the deck restarts into its bootloader, so the dashboard -
    and with it Settings, where the progress bar lives - is gone for the minute
    that matters. That screen now follows the install: what part is being
    written, how far, and to keep the cable in.
    A cable pulled mid-write leaves a deck that answers nothing, which Decky
    already offers to install onto. It now says what it is: "The update did not
    finish", with a button that finishes it.
    The same screen stops saying the wrong things. "Looking for Decky…" and
    "Loading your pages…" are gone, t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
2026-09-12 Let Back work on the deck again, and start at Home
    The snake easter egg counts taps on empty keys before a press reaches its
    action, and a nested page's Back key has nothing assigned - its place is
    kept for Back - so every Back press on the deck was counted as a tap and
    went nowhere. Five of them started snake. isBackKey keeps it out of the
    count; Back in the window was never affected.
    Decky now starts at Home instead of the page it was left on, and a deck
    that starts again (its BOOT line, so over USB) goes back to Home too, with
    Back's history cleared. A deck restarting over Wi-Fi is not noticed yet: ID
    has no boot marker, and online=0 also follows a stall.
2026-09-12 Show a firmware update while it runs, and wait for the deck to come back
    An install holds the session queue for as long as it writes, so the
    window's status check waited behind it: the window went on believing the
    deck was connected, the cache reset made that look like a boot, and "Decky
    is starting" outranks "Decky is updating". Right after writing, a deck
    still starting was listed as a silent device within about three seconds,
    and with the install's progress still set the window offered "Finish the
    update" for an update that had worked.
    While firmware is written, DeckSession.flashing answers status checks at
    once: offline, so the progress shows. After writing, the install asks the
    port fo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
